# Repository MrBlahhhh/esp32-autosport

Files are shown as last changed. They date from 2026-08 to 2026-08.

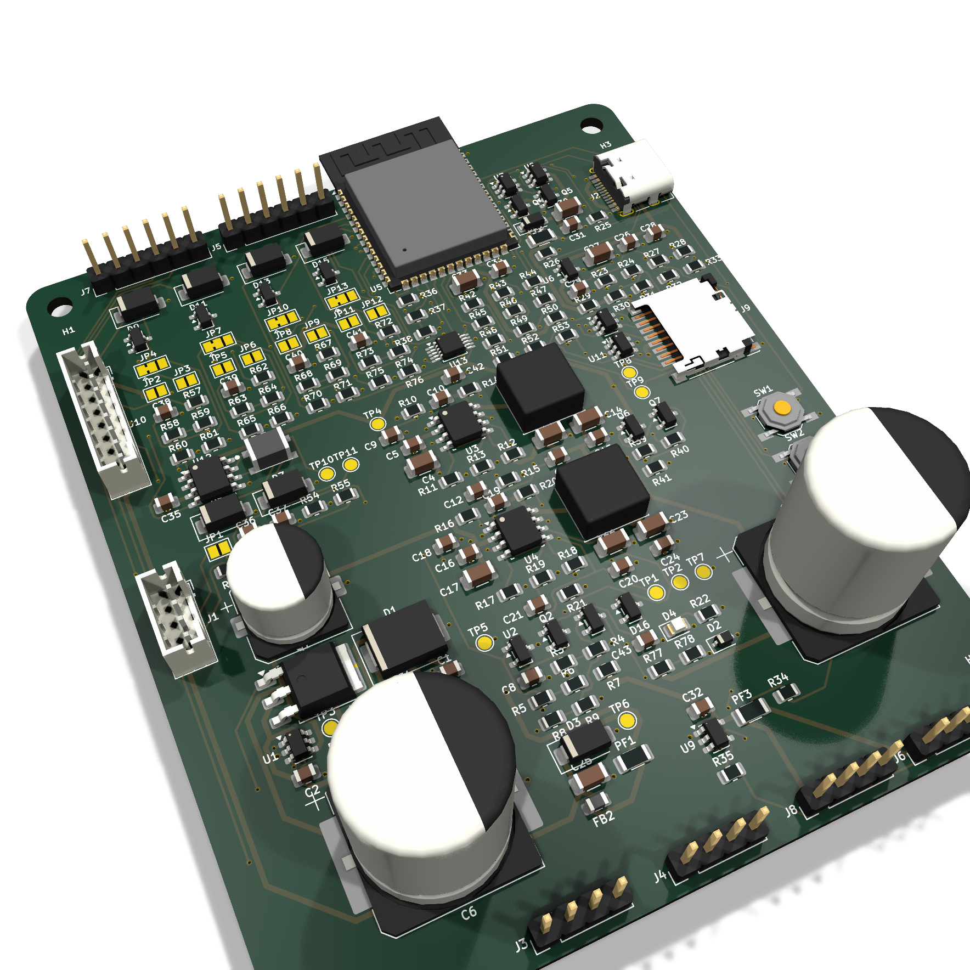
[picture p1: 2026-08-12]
plots/board-iso.png

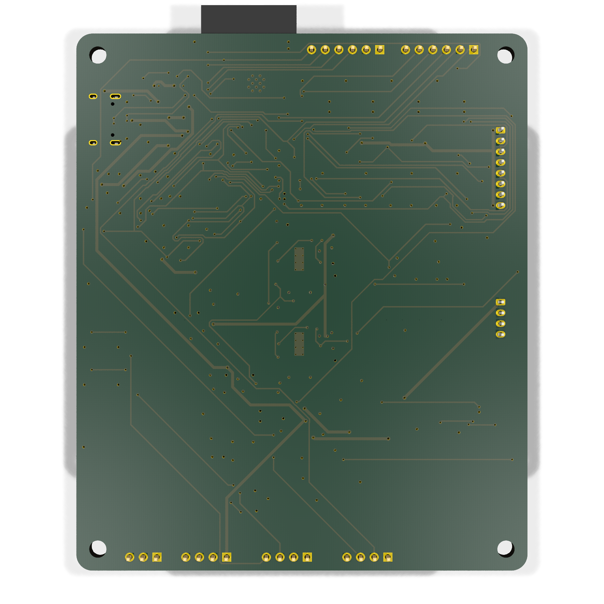
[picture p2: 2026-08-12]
plots/board-back.png

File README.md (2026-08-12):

# ESP32-S3 CAN + microSD Automotive Logger — Rev B

## TL;DR

A data logger you wire straight into a race car: 12 V and CAN come in on one
4-pin plug, sensor readings and CAN traffic get written to a microSD card.

- **You cannot kill it with the wiring.** Battery backwards? Blocks it,
  forever, no blown fuse. Alternator load dump, jump start, ignition spikes?
  Clamped. A sensor wire shorted to 12 V? That channel's fuse trips, the
  board keeps logging.
- **Ignition-off doesn't corrupt the card.** The board sees the power cut
  ~150 ms before it actually dies and uses that time (banked in two big
  capacitors) to finish the write and close the file.
- **4 sensor inputs, jumper-set for 0–3.3 V / 0–5 V / 0–16 V**, readable
  fast-and-rough on the ESP32's own ADC or slow-and-precise on a 16-bit
  ADS1115. Plus battery voltage monitoring, USB-C, a WS2812 shift-light
  header, and spare I/O.
- **The Python in `gen/` is the real source.** It generates, places, routes,
  audits, and circuit-simulates the whole board; the KiCad files are build
  outputs. `python gen/build_board.py` rebuilds the PCB from nothing, and
  [`gen/README.md`](gen/README.md) documents the whole pipeline — including
  the schematic-drawing conventions — so the next board can reuse it.
- **The firmware runs before the board exists.** `gen/simulate_firmware.py`
  compiles the sketch for the PC against a model of this board and feeds it
  CAN frames, sensor voltages and an ignition cut. Porting the proven MINI R53
  shift-light firmware to this hardware turned up five defects that no ERC,
  DRC or SPICE run can see — including a wideband that reads 17 % high and a
  sensor rail that never powers up.
- **State: routed clean, simulated, firmware ported, never manufactured.**
  Order a small prototype run first.

---

A single-CAN, single-microSD ESP32-S3 board with a motorsport-grade front end:
reverse-battery protection that survives being hooked up backwards indefinitely,
load-dump clamping, and four analog sensor inputs whose dividers are selected by
solder jumpers.

Feature set is deliberately close to the Autosport Labs ESP32-CAN-X2 and the
ESP32 Dual CAN-FD dev board — same ESP32-S3-WROOM-1 module, same 4-pin JST-PH
harness convention (12 V / GND / CAN_H / CAN_L), same jumper-selectable 120 Ω
termination — but trades the second CAN channel for an onboard microSD socket
and conditioned analog inputs. Termination ships **off** here rather than on,
which is the one place this board deliberately breaks with that convention:
the common case is plugging into a vehicle bus that is already terminated.

**Status: Rev B, fully routed.** Schematic is ERC-clean on KiCad 9.0. The PCB
is **84 x 100 mm**, 4-layer, **fully placed and routed with zero DRC errors and
nothing unconnected** — 1731 tracks, 323 vias, 206 footprints, 115 nets. Rev B
carries the fixes from an external datasheet review (§7): the LM74700 enable
divider, the ANODE capacitor, two TVS standoff corrections, transient clamps
on the analog harness inputs, and a dozen smaller items. `fab/` holds the
Gerbers, drill, BOM and pick-and-place in JLCPCB's format, BOM and CPL verified
to list the same 167 designators. See §9 for how the board is built, §10 for
what simulation and the physical audit say about it, and §11 for
the ordering steps. **Nothing has ever been fabricated — the first order should
be a small prototype run.**

---

## 1. Specification

| | |
|---|---|
| MCU | ESP32-S3-WROOM-1-N16R8 (16 MB flash, 8 MB octal PSRAM) |
| Supply input | 6–36 V continuous, reverse-protected to −65 V, transients clamped at 64.5 V, 154 ms power-cut ride-through (51 ms worst-case on a flat battery) |
| CAN | 1× CAN 2.0B, TJA1051T/3, ESP32-S3 TWAI controller, split termination, **off by default** |
| Storage | microSD, 4-bit SDMMC, switchable card supply |
| Analog in | 4 channels, solder-jumper divider, **0–5 V by default** (0–3.3 V / 0–16 V by jumper) + optional pull-up bias, shared by the ESP32 ADC and a 16-bit ADS1115 |
| Extras | Battery voltage monitor, USB-C (native USB), I²C/Qwiic, UART0, SPI breakout, WS2812 5 V DIN header, 6-pin spare-IO header |
| Rails | +5 V @ 1 A, +3V3 @ 1 A, +5 V sensor excitation (separately fused) |
| Parts | 195 component instances, 97 distinct BOM lines, all surface-mount except 8 through-hole connectors |

---

## 2. Power chain

```
J1.1 ──[F1 2A]──┬──[FB1 ferrite]── LM74700-Q1 + Q1 (ideal diode) ──┬── +VBAT
                │                                                  ├── C3 100µF bulk
                └── D1 SMCJ40CA clamp                              ├── U3 LM5164 ─→ +5V ─[PF1]─→ +5VS
                    (ahead of the FET)                             └── U4 LM5164 ─→ +3V3
```

### Reverse-battery protection

`U1` (LM74700-Q1) drives `Q1`, a 100 V N-channel MOSFET, as an ideal diode.
`Q1`'s **source faces the battery and its drain faces the load**, so the body
diode points forward: current passes in normal operation, and with the battery
connected backwards the body diode is reverse-biased and the FET is held off.
Nothing conducts, nothing gets hot, and the fuse does not blow — you can hook it
up backwards all day.

The forward drop is the FET's I·R (6.8 mΩ × 0.5 A ≈ 3 mV) rather than a diode's
0.4 V, so nothing is wasted in normal running either.

**Order matters here.** `D1`, the transient clamp, sits *ahead* of the blocking
FET. Clamping downstream of it leaves `Q1` and the LM74700 exposed to whatever
arrives on the harness: on a negative transient `Q1` turns off and stands the
whole pulse across its drain-source, and pulses 1 (−100 V) and 3a (−150 V) both
exceed its 100 V rating. In front of the FET the clamp catches those first —
simulation puts `Q1` at 55 V during pulse 1, against 100 V (§10).

That placement is only safe because `D1` is **bidirectional**. A unidirectional
part in this position would forward-conduct on a sustained reverse connection
and blow `F1`, which is exactly the outcome the ideal diode exists to avoid. At
40 V standoff either way, a −14 V reverse battery is still `Q1`'s job to block
and only real transients are clamped.

`R1`/`R2` set the LM74700 UVLO so the board enables at roughly 5.9 V and drops
out cleanly during cranking rather than browning out in an undefined state.

### Transient rating and its assumption

`D1` is an SMCJ40CA: 40 V standoff either polarity, 64.5 V clamping at 1500 W
(10/1000 µs). 40 V rather than 33 V so the part stands off the declared 36 V
top of the input window instead of sitting in conduction there.

That covers **ISO 7637-2 pulse 5b with centralised load-dump suppression**
(test level ~35 V), which is what any alternator with an internal avalanche
clamp produces — i.e. everything built in the last several decades. Simulation
(§10) shows the harness reaching 31 V in that case with the TVS never
conducting at all. Pulses 1, 2a, 3a and 3b are likewise covered: the worst is
pulse 1, where the clamp takes 0.07 J against roughly 2 J of capability at that
pulse width. A 24 V jump-start sits below the standoff voltage so it does not
conduct.

It does **not** cover unsuppressed load dump. At the pulse 5b level IV of 87 V
the clamp is asked to absorb 219 J against about 6.7 J of capability and is
destroyed (§10). That needs a higher-energy clamp or a series pre-regulator —
**say so if the target vehicle has an external-regulator alternator.**

Both bucks are LM5164s rated to **100 V**, so at the 64.5 V clamp level there
is still headroom on the switcher inputs; the clamp fires before anything
downstream is stressed. The tighter limit is the LM74700's own 65 V, which the
clamp level sits directly on top of — another reason the unsuppressed case is
out of scope rather than marginal.

### Why two bucks instead of a buck plus an LDO

`U3` (+5 V) and `U4` (+3V3) both run directly off `+VBAT`. It costs one extra
inductor versus 12 V→5 V→3.3 V cascading, and buys two things:

1. **Fault isolation.** A shorted 5 V sensor wire in the harness loads `U3`
   and trips `PF1`, but `U4` and the MCU never see it. A cascaded 3.3 V rail
   would collapse with the 5 V rail.
2. **No heat.** A 5 V→3.3 V linear at 600 mA burns ~1 W, which in an engine
   bay at 85 °C ambient is a thermal problem in a small package. A switcher
   burns almost nothing.

Both parts are the same LM5164, so it is one line on the BOM in quantity 20
rather than two different regulators.

### Power-fail detection and ride-through

The ignition cuts this board's power with a log file open on the SD card,
every single drive. The chain that makes that survivable:

1. **Detect** — a TLV431 watches `VBAT_F` *ahead* of Q1 through a 100k/12.7k
   divider and asserts `PWR_FAIL` (GPIO15, rising edge) when the harness
   drops below **11.0 V**. Sensing ahead of the ideal diode is the point:
   when the ignition opens, the harness collapses within microseconds while
   `+VBAT` coasts, so the warning arrives before any stored energy has been
   spent. A 1 M feedback resistor adds ~0.3 V of hysteresis so cranking sag
   cannot chatter the interrupt.
2. **Coast** — `+VBAT` holds 760 µF (100 µF + 2 × 330 µF/100 V). Energy is
   ½CV², so the bank lives on the input rail where a volt is worth most.
3. **Shed** — `SENS_EN` (GPIO16) drives a 2N7002 + AO3401 high-side switch on
   the sensor rail. Sensors are external loads firmware cannot otherwise
   turn off, and at four × 20 mA they double the drain. The switch is off at
   reset — the rail comes up only when firmware asks.

Simulated end to end (§10, `sim/ridethru.png`): detection in under 1 ms, and
from `PWR_FAIL` to the converters dropping out is **154 ms with the sensor
rail shed, 75 ms without** — both measured on the 760 µF bank.

That is the *healthy-battery* case: the ignition opens at 13.5 V and `+VBAT`
starts its coast from there, because `Q1` isolates it from the harness. Open
the ignition on a battery already down at the trip point and the bank starts
at 10.7 V instead — energy goes as V², so that alone is 1.9× less charge. The
Monte Carlo puts that flat-battery corner at **78 ms median, 51 ms at 0.1 %**
with worst-case tolerances (§10). Both are real; they bound opposite ends of
the same event, and firmware should be sized against the 51 ms.

**Firmware contract:** on `PWR_FAIL` rising — drop `SENS_EN`, stop sampling,
flush and close the file, then idle. Do not start a new write while
`PWR_FAIL` is high. The window is guaranteed by hardware; spending it is
firmware's job.

The firmware that spends it now exists and has been run against that window
(§10, *Firmware in the loop*). Measured: the file is closed **31 ms** after
`PWR_FAIL`, leaving 121 ms of the bank unspent, and the card may take up to a
**~130 ms** flush before the close no longer fits — though that, too, is
against the nominal window; on the flat-battery corner the budget is 51 ms and
only a healthy card fits. That is roughly seven times a
healthy card's latency but it is a limit, not unlimited protection — a card
that stalls for longer than that still loses the file.

### Reversed 5 V on the exposed 5 V pins

Asked and answered per connector: **USB-C** cannot be reversed through the
connector (VBUS/GND positions are fixed; the plug is rotation-symmetric).
**J10 sensor +5VS** survives a reversed 5 V by design — D3 forward-conducts
at −0.7 V and PF1 trips, resettable. A **backwards WS2812 strip** trips PF3;
the strip is on its own. **J8 rail break-out is unprotected** — it is a bare
bench header, and a reversed supply clipped onto it lands directly on the
+5 V rail's loads. Treat J8 like any bare rail.

### 5 V sensor excitation

`+5VS` is the +5 V rail behind the `SENS_EN` load switch, `PF1` (200 mA hold
/ 400 mA trip polyfuse), a ferrite, and `D3` (SMAJ6.0A). A sensor wire
shorted to chassis or to battery trips the polyfuse and clamps the transient
without taking the board down — and a tripped rail can now also be cycled
from firmware instead of waiting for the polyfuse to cool.

Note this is a *fused tap off the 5 V rail*, not a separately regulated
reference. For ratiometric sensors where absolute accuracy matters, the ADC
should ratio against a measurement of `+5VS` — or add a dedicated precision
reference. See §7.

---

## 3. Analog input conditioning

Each of the four channels is identical:

```
AINn_IN ──[1k series]──┬─────────[10k]────┬── AINn ──→ ADC
                       │                  │
                  [JPn PULLUP]        [JPn BYPASS] (shorts the 10k)
                       │                  │
                    2.49k             [JPn RANGE] ─┬─[15k]─ GND   (position A)
                       │                           └─[2.21k]─ GND (position B)
                    +5VS                  │
                                    [100nF] + BAT54S clamp to GND / +3V3
```

### Jumper matrix

| RANGE | BYPASS | Input range | Ratio | At the ADC | Clips at | Typical sensor |
|---|---|---|---|---|---|---|
| **A** | open | **0–5.0 V — ships like this** | 0.5769 | 2.885 V at 5.0 V in | 5.37 V in | MAP, TPS, wideband AFR, most 5 V sensors |
| open | **closed** | 0–3.3 V | 1.0000 | 3.300 V at 3.3 V in | 3.10 V in | 3.3 V-native sensor, ratiometric output |
| **B** | open | 0–16 V | 0.1673 | 2.677 V at 16.0 V in | 18.53 V in | Battery-referenced signals, 12 V switch inputs |

**All four channels ship in the 0–5 V position** — `RANGE` bridged 1–2,
`BYPASS` open — because that is what almost every automotive sensor is, and
because it means the firmware's `DIVIDER_GAIN` matches the board as delivered
rather than assuming a jumper somebody has to remember to fit. Cut the 1–2
bridge to move a channel to either of the other two rows.

The upper leg is the 1 k series resistor plus the 10 k, so 11 k against 15 k
gives 15/26 = 0.5769 on the 5 V range and 2.21/13.21 = 0.1673 on the 16 V one.

**These deliberately do not divide to 3.3 V.** The ESP32-S3 ADC tops out near
3.10 V at 12 dB attenuation, and a divider scaled to land exactly there has no
margin: a 5 V sensor rail is rarely exactly 5.000 V, and anything that
overshoots clips silently at full scale — which reads as a plausible-but-wrong
value rather than an obvious fault. At 0.5769 a 5 V channel does not clip until
5.37 V in. The 1:1 mode is the exception and has no headroom by design; it
assumes a sensor that genuinely cannot exceed 3.3 V. The BAT54S clamps protect
the pin either way, but clamping is protection, not measurement.

Source impedance at the ADC node is 11 k ∥ 15 k = **6.35 kΩ** on the 5 V range
(1.84 kΩ on the 16 V range). With the 100 nF filter cap that puts the −3 dB
point at about 250 Hz — ideal for AFR, temperature and pressure, and the limit
if you ever want something fast on a channel.

`PULLUP` is independent of the above: closing it puts 2.49 kΩ to `+5VS` on the
input node, turning the channel into a bias network for **2-wire NTC sensors**
(coolant, oil, air temp) or open-collector/switch-to-ground inputs. Leave it
open for anything that drives its own output.

Every channel lands on **ADC1** (`GPIO1`, `GPIO2`, `GPIO4`, `GPIO5`), which is
the half of the ESP32-S3 ADC that keeps working while WiFi is active. ADC2 is
unusable with WiFi up — that constraint drove the pin assignment.

The same four conditioned nodes also feed `U13`, an **ADS1115** (16-bit
delta-sigma, on the existing I²C bus at 0x48). The ESP32-S3's internal ADC is
only good for ±1–2 % even after calibration — ±0.2 AFR on a 0–5 V wideband
output — so firmware picks per channel: fast-and-rough on the internal ADC, or
slow-and-accurate (up to 860 SPS) on the ADS1115. The divider resistors are
0.1 % thin-film so the front end does not throw away what the converter buys,
and the note in the schematic records that the 1 k series resistor is part of
the divider chain — the exact scale factor is a firmware calibration constant.

`R77` (100 k) and `R64` (10 k) divide `+VBAT` by 11 onto `GPIO6` for
battery-voltage logging: 14.0 V reads 1.27 V, and the 36 V top of the input
range reads 3.27 V.

---

## 4. CAN

`U12` is a TJA1051T/3 — 5 V bus drive with a separate `VIO` pin tied to +3V3, so
the ESP32 sees 3.3 V logic with no level shifter. `S` is pulled low by `R54`
(10 k) so the transceiver comes up in normal mode with the MCU still in reset;
`GPIO21` can raise it for silent (listen-only) sniffing. `CAN_TX` has no
external pull — the TJA1051 pulls TXD high internally, so a floating pin at
boot is recessive and a bare board cannot jam the bus.

Bus side, in order from the transceiver out:

- `L3` common-mode choke — TDK ACT45B-510-2P-TL003, 51 µH, AEC-Q200. The
  footprint is project-local (`footprints/esp32autosport.pretty`) and its pads
  are renumbered so the symbol's winding 1–2 maps to the package.
- Split termination: `R55`/`R56`, two 60.4 Ω in series with `C28` 4.7 nF to
  ground at the midpoint. Split termination beats a single 120 Ω resistor
  because it gives the common-mode noise somewhere to go instead of
  reflecting it.
- `JP1` in series with the top half — **open by default: the board ships
  unterminated**. Bridge the pads only when this board is an end node on a bus
  of its own. Every vehicle bus, OBD-II diagnostics included, is already
  terminated at both ends, and a third 120 Ω across the pair takes it to about
  40 Ω and can stop it working. This deliberately departs from the Autosport
  Labs convention of shipping terminated, because the common case here is
  plugging into a car that is already correct.
- `D6`/`D7` SMAJ26CA bidirectional clamps to ground on each line.

CAN_H/CAN_L run to `J1` pins 3 and 4, so one 4-pin JST-PH carries power and bus
in a single harness.

### OBD-II and "K-DCAN"

A BMW/MINI K+DCAN cable carries **two unrelated buses**, and this board has
hardware for exactly one of them.

**D-CAN — yes, already.** Diagnostic CAN is ISO 15765-4: plain 500 kbit/s CAN
on OBD-II pins 6 and 14, which is what `U12` and the TWAI controller do. `J1`
maps onto an OBD-II plug with nothing in between — pin 16 to `J1.1`, pins 4/5
to `J1.2`, pin 6 to `J1.3`, pin 14 to `J1.4` — so one cable both powers the
board and connects it to the bus. What is left is software: ISO-TP
(ISO 15765-2) segmentation and whichever of UDS or KWP2000 the target speaks.

> **Termination is already off.** `JP1` ships open (§4), which is what a
> vehicle bus wants — it is already terminated at both ends, and a third
> 120 Ω across the pair drops it to ~40 Ω and can stop it working entirely.
> So there is nothing to cut before plugging into a car; bridge `JP1` only
> for a bench bus where this board is an end node. Note also
> that `CAN_S` (GPIO21) lets firmware pick listen-only for sniffing, so the
> board need never ACK a bus it is only observing.

**K-line — no, and it cannot be bodged.** ISO 9141-2 / KWP2000 is a single
bidirectional wire on OBD-II pin 7 idling at battery voltage and pulled to
ground by an open-collector driver. That needs a transceiver — an L9637D or
equivalent — and there is none on this board. Feeding it into an analog input
does not work either: on the 0–16 V setting the anti-alias filter rolls off at
891 Hz (§10), which destroys even 9600 baud, and it gives no way to transmit.
Routing it to `J7` is worse, since those are strapping pins and a K-line
idling high at boot would hold `IO46` in the wrong boot mode.

This matters for the **MINI R53** specifically: its instrument CAN carries
`0x316` at 500 kbit/s, which this board already reads and logs — but its
*diagnostics and flashing* are K-line at 9600 8E1, negotiating to 62500 baud
for flash reads. The shift light and telemetry work on this hardware. A
tuning or flashing tool does not.

Adding it needs an external L9637D module on the `J5` SPI header — the S3's
UARTs matrix onto any GPIO, so two of `GPIO40`–`42`/`47` become K-line TX/RX,
and `J5` supplies +3V3 and ground. The one wire `J5` cannot supply is the
transceiver's battery feed: `J8` breaks out +5 V, +3V3 and ground only, so
12 V has to come from `TP3` or upstream of `J1`. **For a rev C, an on-board
L9637D is the highest-value addition** — SO-8, about a dollar, two GPIOs and a
`+VBAT` tap — and it would make one board cover both halves of a K+DCAN cable.

---

## 5. microSD

Wired for **4-bit SDMMC** (`GPIO9`–`GPIO14`), not SPI — roughly 4× the write
throughput, which matters when logging a busy bus.

- 33 Ω series damping on CLK, CMD and D0–D3.
- 10 kΩ pull-ups on CMD and D0–D3, the value Espressif's SD documentation
  asks for. **These pull to `SD_VDD`, the switched rail, not to +3V3** —
  pull-ups to a permanent rail would back-feed a powered-down card through
  its ESD structures. The pull-up on D3 is also what selects SD mode over
  SPI mode when the card powers up. Card detect keeps a weaker 47 kΩ: it is
  a mechanical contact, not a bus line, so there is no reason to burn the
  standing current.
- `Q6`/`Q7` form a high-side switch on the card supply, driven by `GPIO7`, so
  firmware can hard power-cycle a card that has locked up mid-write. This is
  the single most useful recovery mechanism in a logger; SD cards do wedge.
- `GPIO8` reads the socket's card-detect switch.

**Firmware note:** tristate the SDMMC pins before dropping `SD_PWR_EN`, or the
MCU will back-feed the card through its I/O pins while its supply is off.

---

## 6. GPIO map

| Module pin | GPIO | Net | Function |
|---|---|---|---|
| 39 | IO1 | `AIN1` | Analog ch 1 (ADC1_CH0) |
| 38 | IO2 | `AIN2` | Analog ch 2 (ADC1_CH1) |
| 4 | IO4 | `AIN3` | Analog ch 3 (ADC1_CH3) |
| 5 | IO5 | `AIN4` | Analog ch 4 (ADC1_CH4) |
| 6 | IO6 | `VBAT_SNS` | Battery voltage ÷11 (ADC1_CH5) |
| 7 | IO7 | `SD_PWR_EN` | microSD supply enable (high = on) |
| 12 | IO8 | `SD_CD` | Card detect |
| 17–22 | IO9–IO14 | `SD_D3,D2,D1,D0,CMD,CLK` | SDMMC 4-bit |
| 10, 11 | IO17, IO18 | `CAN_TX`, `CAN_RX` | TWAI |
| 23 | IO21 | `CAN_S` | Transceiver silent mode (low = normal) |
| 13, 14 | IO19, IO20 | `USB_DM`, `USB_DP` | Native USB |
| 31, 32 | IO38, IO39 | `I2C_SDA`, `I2C_SCL` | Qwiic header |
| 36, 37 | IO44, IO43 | `UART_RX`, `UART_TX` | UART0 header |
| 33–35, 24 | IO40–42, IO47 | `SPI_SCK`, `SPI_MISO`, `SPI_MOSI`, `SPI_CS` | SPI breakout |
| 25 | IO48 | `LED_DIN_MCU` | WS2812 data (via 5 V AHCT buffer → header) |
| 27 | IO0 | `MCU_BOOT` | BOOT button |
| 3 | EN | `MCU_EN` | RESET button |
| 15, 16, 26 | IO3, IO46, IO45 | — | Spare-IO header `J7`, each with a 10 k pull-down |
| 8 | IO15 | `PWR_FAIL` | Power-fail interrupt (high = harness below 11 V); also J7 pin 4 as a probe point |
| 9 | IO16 | `SENS_EN` | Sensor-rail (+5VS) enable, active high, off at reset; also J7 pin 5 |
| 28, 29, 30 | IO35, IO36, IO37 | — | **Unusable** — octal PSRAM |

`IO3`, `IO45` and `IO46` are strapping pins, and each carries a 10 kΩ
pull-down (`R36`–`R38`) chosen for its strapping role: `IO45` low sets
VDD_SPI to 3.3 V, `IO46` low selects normal boot, `IO3` low fixes the JTAG
source. The board therefore boots correctly with `J7` empty. What the
pull-downs cannot survive is something plugged into `J7` that actively
*drives* one of them high at boot — 10 kΩ loses to a driver — so do not hang
anything on `J7` that asserts a level before the MCU is out of reset.

### WS2812 shift-light header

`J6` (silk **WS2812**): `LED_5V` / `LED_DIN` / `GND`. `LED_DIN` is driven by a
`74AHCT1G125` powered from `+5V`, so the strip sees a real 5 V logic level.
Firmware bit-bangs / RMT on **GPIO48**. `LED_5V` is behind a 0.5 A polyfuse off
the board 5 V rail — enough for an 8-LED stick, not a full belly-band.

### SPI breakout

`+3V3` / `GND` / `SCK` / `MISO` / `MOSI` / `CS` on GPIO40/41/42/47. Intended for
an external MCP2515 (second CAN), CC1101 (433 MHz TPMS), or MAX6675, etc.

---

## 7. Review before layout

Resolved in the rev A review (2026-08, against datasheet SNVSAU4D and TI
drawing 4214849/B):

1. ~~RON placeholders~~ — computed from Eq. 12: **31.6 kΩ → 396 kHz** on the
   5 V rail, **20.5 kΩ → 402 kHz** on the 3.3 V rail. Minimum on-time at the
   64.5 V clamp is 196 ns / 128 ns, both far above the 50 ns floor.
2. ~~Footprint~~ — the original `EP2.41x3.3mm` exposed pad was *smaller* than
   the DDA0008B pad itself (max 2.71 × 3.4 mm). Now on
   `EP2.95x4.9mm_Mask2.71x3.4mm_ThermalVias`, which matches TI's example land
   pattern exactly (2.95 × 4.9 copper, 2.71 × 3.4 mask-defined opening).
3. ~~Load-dump assumption~~ — confirmed: the target vehicle's alternator never
   exceeds 20 V, so the SMCJ40CA's 40 V standoff has comfortable margin and the
   centralised-suppression assumption in §2 holds. Simulation later put a
   number on what happens if it does not: see §10.
4. ~~Clamp injection~~ — quantified: one analog input shorted to 20 V battery
   back-feeds ≈1.6 mA through its BAT54S into +3V3. With the MCU running
   (≥ 20 mA) the rail cannot lift, but in deep sleep the always-on load is only
   ≈1.3 mA (power LED), so one faulted channel floats the rail to ≈3.6 V and
   two would exceed the ESP32's absolute maximum. Fixed with `D2`, a 3.6 V
   zener rail clamp (MM3Z3V6T1G).

Two more issues surfaced while reading the datasheet, both fixed:

- **Bootstrap capacitors were 100 nF.** The LM5164 datasheet mandates exactly
  2.2 nF and warns that larger values overstress the internal VCC regulator
  and damage the device. Both `CBST` are now 2.2 nF 50 V X7R.
- **No feedback ripple injection.** The outputs are all-ceramic, so FB had no
  in-phase ripple — the datasheet (Table 6-1) says a COT converter is unstable
  without it. Both rails now carry a Type-3 network (RA from SW, CA to the
  output, CB into FB: 121 k / 3.3 nF / 270 pF on 5 V, 95.3 k / 3.3 nF / 270 pF
  on 3.3 V), sized per TI's design example for ≈20 mV of ramp at 14 V in.

5. ~~ESP32-S3 ADC linearity~~ — resolved for the AFR use case: `U13`, an
   onboard ADS1115 (16-bit, I²C), now shares the four conditioned input
   nodes, and the divider resistors are 0.1 % thin-film. See §3.

6. ~~Layout rules~~ — the board is laid out now (§9). The switching-regulator
   rules this item called for are all in `gen/generate_pcb.py` and
   `gen/route_bucks.py` as fixed placements: tight input-cap loops on
   `U3`/`U4` with `C4` at the VIN pin, a solid GND plane under the whole
   ideal-diode block, and the CAN choke beside `J1`.

Still open for a second pair of eyes:

7. `+5VS` accuracy (§2) if ratiometric sensors are used. (AFR is absolute, not
   ratiometric, so this does not affect the wideband channel.)
8. **Nothing has been fabricated.** Every check here is a software check —
   ERC, DRC, datasheet review, sourcing. No one has powered one on.

Found later, during the pin audit (§6), and worth knowing rather than fixing:

9. The WS2812 buffer input floats at boot. `GPIO48` reaches `U9` pin 2 through
   a 33 Ω series resistor with no pull-down, so that CMOS input is undefined
   from power-on until firmware drives it — a brief random flicker on the
   strip and a milliamp or so of shoot-through in `U9`. Harmless, and cheaper
   to fix in firmware (drive `GPIO48` low first) than to respin for.
10. `J7` (Spare IO) has three signals and no ground pin. Use `J8`'s ground two
    headers along. Also note all three of its pins are strapping pins — see
    §6.

### Sourcing (JLCPCB assembly)

**Every part number in `fab/bom.csv` was re-checked against the live LCSC and
JLCPCB catalogues on 2026-08-12** — all 23, one at a time, confirming the MPN,
the package and that the part exists. Two were wrong:

| Was | Resolved to | Should be |
|---|---|---|
| `C8544` for `Q5` MMBT3906 | **S9018, an NPN** from JSCJ | `C84105` — ST(Semtech) MMBT3906, PNP, SOT-23 |
| `C7975` for `U9` SN74AHCT1G125DBVR | **LMV324IPWRG4**, a quad op-amp in TSSOP-14, out of stock | `C7484` — TI SN74AHCT1G125DBVR, SOT-23-5 |

The `Q5` one was live in the BOM and would have assembled an NPN where the USB
over-voltage cutoff needs a PNP — protection that silently does not work. The
`U9` one was only ever in this table; the generator already carried a comment
saying `C7975` was wrong and left the field blank, and that fix never reached
the prose. Both are corrected, and `L2`'s 22 µH inductor picked up a verified
number (`C340243`) on the way past.

The critical semiconductors, all confirmed present and in stock:

| Part | MPN | JLC # | Notes |
|---|---|---|---|
| ESP32 module | ESP32-S3-WROOM-1-N16R8 | C2913202 | 13 087 in stock |
| Buck ×2 | LM5164DDAR | C477928 | Non-automotive variant — the Q1 is backordered at DigiKey and nearly dry at Mouser; same silicon, minus AEC-Q100 |
| Ideal-diode ctrl | LM74700QDBVRQ1 | C2941042 | SOT-23-6, 3 987 in stock |
| Reverse-batt FET | IPD068N10N3G | C88066 | Replaces PSMN4R3-100BSE, **which does not exist** (nearest real Nexperia part is a D2PAK); TO-252, drops into the same footprint, 6.8 mΩ costs ~3 mV at load |
| CAN transceiver | TJA1051T/3 | C58988 | NXP original, 11 085 in stock; the BOM carries the `,118` reel suffix |
| Precision ADC | ADS1115IDGSR | C37593 | VSSOP-10, 24 565 in stock. Non-automotive variant — the Q1 needs a manufacturer quote at DigiKey |
| WS2812 buffer | SN74AHCT1G125DBVR | **C7484** | TI, SOT-23-5. **Not C7975** |
| USB OVP transistor | MMBT3906 | **C84105** | ST(Semtech), PNP. **Not C8544** |
| Buck inductors | ASWPA8050S330MT / S220MT | C340244 / C340243 | Sunlord automotive series, 8×8 mm, 3 A Isat. JLCPCB-catalogue parts — the LCSC product page 404s, which is normal for JLC-only stock |

Nine lines still have no part number and are picked by hand at order time: the
`330 µF`/`100 µF` 100 V electrolytics, the green LED, `PMEG4010`, both
polyfuses, `DMG2301L`, the `TL3342` buttons, `TLV431ASN1T1G`. The 0.1 %
thin-film divider resistors are commodity and auto-match on value + package.

---

## 8. Files

| Path | What |
|---|---|
| `esp32s3-can-sd-logger.kicad_pro` | KiCad project. **Owns the netclasses** — Power 0.5 mm / CAN 0.25 mm — and the 0.2 mm min-drill rule |
| `esp32s3-can-sd-logger.kicad_sch` | Root sheet |
| `power.kicad_sch` | Protection and rails |
| `mcu.kicad_sch` | ESP32-S3, USB-C, headers |
| `sdcard.kicad_sch` | microSD |
| `can.kicad_sch` | CAN transceiver and bus network |
| `analog.kicad_sch` | 4 sensor channels + battery monitor |
| `bom.csv` | BOM with quantities for 1 and 10 boards |
| `netlist.txt` | Human-readable net list (the design's source of truth) |
| `plots/schematic.pdf` | Rendered schematic, all six sheets |
| `gen/generate_schematic.py` | Generator — edit this, not the `.kicad_sch` files |
| `gen/validate.py` | Verifies the output with KiCad itself |
| `gen/build_board.py` | One-command board build: places, stitches, routes, verifies |
| `gen/generate_pcb.py` | Board generator — run with KiCad's bundled Python |
| `gen/stitch_planes.py` | Via from every GND / +3V3 pad to its plane |
| `gen/export_dsn.py` | Specctra export with the inner layers locked as planes |
| `gen/import_ses.py` | Imports the router's session and refills the pours |
| `gen/finish_routing.py` | Ties duplicated connector pins; reports leftovers |
| `gen/maze_route.py` | Rip-up-and-retry router for what the autorouter fences in |
| `gen/tidy_silk.py` | Shrinks and re-places reference designators; no copper |
| `gen/netclasses.py` | Per-net track and via sizes, read from the project file |
| `gen/export_fab.py` | Gerbers, drill, JLC assembly BOM and position files |
| `gen/export_plots.py` | Rebuilds everything under `plots/` — run it after any change |
| `gen/route_bucks.py` | Places buck islands + routes SW/VIN critical copper |
| `esp32s3-can-sd-logger.kicad_pcb` | Generated 4-layer board, fully placed and routed |
| `footprints/esp32autosport.pretty` | Project footprints (TDK ACT45B CAN choke) |
| `plots/board-routed.png` | Render of the finished board, top |
| `plots/board-back.png` | Render of the finished board, bottom — routing only, no parts |
| `fab/` | Gerbers, drill, JLC BOM and pick-and-place (generated) |
| `docs/PREORDER.md` | Pre-order checklist: what is checked, what is not, what to do at upload |
| `gen/audit_paste.py` | Stencil apertures: IPC-7525 area ratio and thermal-pad paste coverage |
| `gen/audit_mechanical.py` | Vibration screen: board resonance and Steinberg fatigue on the tall cans |
| `docs/BRINGUP.md` | Staged first-power checklist, tied to the study values |
| `firmware/esp32_shiftlight_wideband/` | Firmware for this board: shift light, wideband BLE bridge, microSD logger |
| `firmware/vendor/` | Verbatim copy of the R53 sketch — the control build, do not edit |
| `gen/simulate_firmware.py` | Firmware-in-the-loop studies: runs the sketch and feeds it inputs |
| `fwsim/` | The host shims and board model those studies run on |
| `gen/mutate_firmware.py` | Mutation test: breaks the firmware 16 ways and checks the suite notices |
| `sim/fw/` | Per-run scenario, trace, serial log and findings (generated) |

### KiCad version

The committed files are **KiCad 7.0 schematic format** (`version 20230121`).
KiCad 8 and 9 open them directly and upgrade the format on load, so nothing
needs converting — just open `esp32s3-can-sd-logger.kicad_pro`. Note that once
KiCad 9 saves, the files are rewritten in 9's format; re-running the generator
would put them back to 7's.

### Running ERC

`kicad-cli` gained an `erc` subcommand in 8.0. On KiCad 8 or 9, `validate.py`
picks it up automatically and reports violations as failures. To run it alone:

```sh
kicad-cli sch erc --output erc.json --format json \
    --severity-error --severity-warning esp32s3-can-sd-logger.kicad_sch
```

On KiCad 7 the check is skipped with a notice, since the subcommand does not
exist there. **ERC passes clean on KiCad 9.0** (no errors, no warnings) as of
rev A; the committed files embed symbol definitions from the KiCad 9 libraries,
so opening them on an older KiCad may report harmless lib-mismatch warnings.

### Regenerating

The schematic is generated. The netlist tables in `gen/generate_schematic.py`
are authoritative; symbol geometry and **all pin numbering** are pulled from the
installed KiCad libraries, so no pin number is ever hand-typed.

```sh
python3 gen/generate_schematic.py
python3 gen/validate.py
```

`validate.py` loads every sheet through KiCad, exports the hierarchy's netlist,
asserts that KiCad's own extracted connectivity matches `netlist.txt`
node-for-node, and runs ERC where available. It currently passes on **107 nets /
168 component instances**.

The generator embeds symbol definitions copied verbatim from the installed
libraries, so the embedded copies always match whatever KiCad generation you
regenerate on (it handles both the 7/8 space-indented and the 9 tab-indented
library formats, and resolves the generic MOSFET symbols from `Transistor_FET`
where KiCad 9 moved them out of `Device`). The generator prints a warning when
the library generation differs from the one last validated against — run
`validate.py` afterwards; it will catch a sheet that fails to load and runs a
full ERC.

Editing the `.kicad_sch` files by hand is fine — they are ordinary KiCad files —
but the next generator run will overwrite them.

---

## 9. Board layout and routing

The board is generated the same way the schematic is. One command does the
whole chain:

```sh
python gen/build_board.py --freerouting freerouting.jar
```

| Stage | Script | What it does |
|---|---|---|
| 1 | `generate_pcb.py` | Places every part, draws the outline, planes, keepouts |
| 2 | `route_bucks.py` | Hand-shaped copper for the two buck power loops |
| 3 | `stitch_planes.py` | A via from every GND / +3V3 pad down to its plane |
| 4 | `export_dsn.py` | Specctra export, **In1/In2 marked as power planes** |
| 5 | freerouting | Routes the remaining signals on F.Cu / B.Cu |
| 6 | `import_ses.py` | Brings the routes back, refills the pours |
| 7 | `finish_routing.py` | Ties duplicated connector pins, reports leftovers |
| 8 | `maze_route.py` | Rips up and re-routes whatever is still open |
| 9 | `tidy_silk.py` | Shrinks and shuffles the reference designators |

84 x 100 mm, 4 layers: **F.Cu / GND / +3V3 / B.Cu**, JLCPCB JLC04161H-7628
stackup, 0.2 mm minimum drill (the LM5164 thermal vias), 0.5 mm copper-to-edge
enforced by a rule-area band around the perimeter.

Five things in that pipeline are worth knowing, because every one of them
was learned the hard way:

**The inner layers must be declared `power` in the DSN.** KiCad exports every
copper layer as `signal`, so an autorouter cheerfully runs traces straight
through what are meant to be solid pours -- the first attempt here had `IO45`
and `SPI_MOSI` crossing the middle of the +3V3 plane, which fragmented it and
orphaned everything that depended on it. `export_dsn.py` rewrites those two
layer declarations, and routing then stays on the outer layers where it
belongs.

**Plane pads are stitched before routing, not after.** A pad on GND or +3V3
does not want a routed track, it wants a via next to it; doing all 113 of them
up front means the router treats them as obstacles and has only signals left to
solve. 110 get a via; the three that do not are the exposed thermal pads of
`U3`, `U4` and the module, which the pour bonds to directly. `stitch_planes.py` places each via with real point-to-rectangle and
point-to-segment distance checks -- bounding boxes are far too pessimistic in a
dense field and refuse room that is really there.

**The last few connections need rip-up, not a better search.** An autorouter
takes the easy nets first and fences the awkward ones in, so what it leaves
behind has no path at all -- `SD_CLK` ran straight under the ESP32 module's
pads 20 and 21 and walled both of them off, and at 1.27 mm pitch nothing slips
past sideways. `maze_route.py` grids each copper layer at 0.1 mm, searches both
layers at once with Dijkstra, and when that fails works out which nets are
pressed against the dead end, tears them out, routes the trapped net through
the space they leave, and re-routes them afterwards. Three details make it
work rather than thrash:

- **A rip removes tracks, never pads.** Ignoring a ripped net's pads too lets
  the router lay copper straight across them.
- **Blockers are ranked from the tighter pocket.** Flood from both ends and
  score the smaller one -- an end that can reach half the board has a frontier
  thousands of cells long, and the innocent nets along it drown out the few
  actually doing the trapping.
- **Connections are to a net, not a pad.** USB-C carries D- on both A7 and B7;
  A7 escapes only down a 16 um corridor, finer than any grid, while B7 opens
  onto the whole board. Aiming at the net's existing copper turns an
  impossible route into an easy one.

Nets with more than four pads are never ripped: a two-pad signal comes back as
one trace, but a rail that daisy-chains six decoupling caps comes back as six
separate connections, each able to fail on its own.

**The netclasses live in the `.kicad_pro`, and two things used to lose them.**
This one is worth spelling out because it fails silently -- narrow track is
legal track, so nothing errors, nothing warns, and the board looks finished.

`generate_pcb.py` builds its board with `CreateEmptyBoard()`, which knows only
the Default class; saving that board rewrote the project file from the board's
own settings and threw Power and CAN away. Everything downstream then routed
at the default width, **including the 1 A rails** -- 0.2 mm copper, which is
1.01 A at a 20 °C rise and 147 mV of drop over a 60 mm run. On `+5VS`, the
sensor excitation rail, that droop lands directly on every ratiometric reading
the 0.1 % dividers exist to protect. The generator now lifts `net_settings` out
before the save and puts it back after, and reports what it restored.

The second loss was `net.GetNetClass()`, which returns an undecorated
SwigPyObject in these scripts and raises `AttributeError` on any method. A
`try/except ... return DEFAULT` around it turns straight into 0.2 mm power
rails. `gen/netclasses.py` reads the classes and their glob patterns out of the
project file instead, and both routers size every track and via from it.

**Pads are not their bounding boxes.** The router's occupancy grid may use
bounding boxes -- being too cautious only costs it room -- but deciding *where
a trace may end* cannot. A 1.70 mm round header pad has a 1.70 mm square
bounding box whose corners are ~0.35 mm off the copper, so 23 % of the apparent
landing area is bare laminate. Ending there produces a connection that is not
one, which is how every header on J3/J4/J5/J7 stayed open while the router
insisted it had routed them. The island builder asks `pad.HitTest()` instead,
which is exact for round, oval and rounded-rectangle pads alike.

### Placement

- **Left edge:** sensor harness (`J10`) and power/CAN harness (`J1`) -- one
  wiring direction toward the car.
- **Top:** four identical analog channel columns with their solder jumpers
  facing up for probing; ESP32 module top-centre with the **antenna
  overhanging the board edge**, so the module's own RF keepout falls entirely
  off-board; Spare-IO and SPI headers to its left.
- **Right edge:** USB-C and microSD for bench access, then RESET/BOOT and the
  status LEDs.
- **Middle:** the two stacked buck islands, each with its input caps at the
  VIN pin and its RON/FB/ramp network alongside.
- **Bottom edge:** battery front end beside `J1`, and the UART0 / I2C / rail /
  WS2812 headers along the edge.

The USB-C receptacle sits ~2.5 mm inboard of flush rather than overhanging.
Its A/B duplicate pins (D+ on A6 and B6, D- on A7 and B7) have to be tied
together on copper for a reversible cable, and at 0.5 mm pitch that needs a
via channel between the pad row and the edge keepout. The case opening sets
plug access anyway.

## 10. Simulation and physical audit

Two scripts check what ERC and DRC structurally cannot. ERC asks whether the
netlist is self-consistent and DRC asks whether the copper is manufacturable;
neither asks whether the circuit works, or whether the board survives a car.

```
python gen/simulate.py                          # ngspice: the circuits
"…/KiCad/9.0/bin/python.exe" gen/audit_pcb.py   # pcbnew: the layout's physics
"…/KiCad/9.0/bin/python.exe" gen/overstress.py  # closed-form worst case
```

`simulate.py` needs ngspice, numpy and matplotlib and runs on any Python 3. It
writes its decks, data and plots to `sim/`, so every number below can be
re-derived rather than taken on trust.

**What it confirms.** The divider maths in §3 is right to three digits: 5.0 V
in gives 2.859 V at the ADC on the 0–5 V setting and 16.0 V gives 2.670 V on
the 0–16 V setting, against the 2.88 and 2.67 the schematic notes predict.
Both converters run well inside their inductors — 0.27 A of ripple on a 2.13 A
peak against a 3.0 A saturation rating for +5 V, 0.35 A on 1.18 A against
3.4 A for +3V3 — with 26 mV and 44 mV of output ripple at 13.5 V in, computed
against the output MLCCs' biased capacitance rather than their printed value.
ISO 7637-2 pulses 2a, 3a and 3b never reach the clamp at all: the 100 µF bulk
and the ferrite swallow them and the TVS absorbs a measured 0 J.

**What it flags.**

1. **Pulse 1 still browns the board out, now for ~5.6 ms.** A -100 V, 2 ms
   transient turns Q1 off, and the board runs on the 760 uF bank at full
   load until the harness recovers. The ride-through caps shrank the outage
   from 8.2 ms but cannot absorb it: the pulse actively holds the harness
   at -47 V for 2 ms, and the bank spends most of its charge riding that
   out. Nothing is damaged -- Q1 stands off 59 V against its 100 V rating --
   and the power-fail detector fires on the way down, so firmware sees it
   as an ordinary power cut and closes the file. A reset mid-drive on a
   full ISO pulse 1 is the accepted outcome. **This is a decision, not a
   defect.**

2. **An unsuppressed load dump destroys the front end.** At the pulse 5b
   level IV of 87 V the SMCJ40CA absorbs 219 J against roughly 6.7 J of
   capability at that pulse width. The suppressed 35 V case is a non-event:
   31 V at the harness, the TVS never conducts. So D1's note claiming it
   "absorbs ISO 7637-2 pulse 5b load dump" holds only for a vehicle with a
   centrally suppressed alternator — every modern one, but an assumption the
   board depends on rather than a property it has.

3. **The anti-alias corner moves with the range jumper**: 261 Hz on the 0–5 V
   setting, 891 Hz on 0–16 V, 1.65 kHz bypassed. The 100 nF sees a different
   source impedance in each configuration, so the filter is whatever the
   divider leaves it. Two of the three sit above the 430 Hz Nyquist of the
   ADS1115 at its fastest rate.

4. **A 36 V input with BYPASS closed backfeeds +3V3.** Each channel pushes
   32 mA through its BAT54S into the rail, 129 mA across four. Harmless while
   the ESP32 is drawing its share; a rail-pumping hazard on a sleeping or
   unpowered board with a live loom.

5. **A non-compliant USB brick used to backfeed the 5 V rail — now cut
   off.** VBUS reaches +5V through PF2 and D5, and the buck can source but
   not sink, so a brick that negotiated 9 V put ~8.4 V on the rail — over
   the TJA1051's 6 V absolute maximum. Fixed with a TLV431 + AO3401 series
   cutoff tripping at 5.77 V (the same recipe as the sensor-rail switch):
   re-simulated, a compliant 5 V source passes at 4.99 V, the switch opens
   at 5.95 V of brick, and the rail never exceeds 5.2 V from anything up
   to 14 V. Off-the-shelf OVP parts were rejected first — the TPS25200
   class cuts off near 7 V, which is no protection for a 6 V limit.

**Second-round studies** (also in `gen/simulate.py`):

- **Battery-connect inrush**: the 760 µF bank charges through Q1's body diode
  before the LM74700 wakes — **44.0 A peak, 0.274 A²s** of surge and 11.7 mJ
  in the diode over 0.80 ms. The fuse's I²t burden is linear in C, so this is
  the price of the bigger bank: it was 0.20 A²s at 540 µF. A 2 A nano fuse is specified around 1 A²s; verify the exact
  figure on the datasheet at order, but the margin is ~3.6×.
- **Engine crank (ISO 16750-2 profile)**: warm (6.0 V dip) and cold (4.5 V
  dip, 15 ms) both ride through — the bank carries the bottom of the dip and
  the 6.5 V starter plateau sits above the converters' dropout. `PWR_FAIL`
  asserts exactly once per crank; the 1 M hysteresis prevents chatter, so
  firmware sees one clean "close the file" event per start.
- **Monte Carlo tolerances** (20 000 samples): power-fail trip lands in
  10.72–11.29 V at 99.8 %; the 0.1 % analog divider stack holds gain error
  to ±0.08 %; +5 V spans 4.85–5.15 V and +3V3 spans 3.19–3.38 V worst-case;
  the battery monitor's 1 % divider is ±1.9 % — calibrate it in firmware.
  Ride-through on a **flat battery** (bank starting at the 10.7 V trip point
  rather than 13.5 V) is 78 ms median and **51 ms at the 0.1 % corner** with
  caps −20 % and load +40 %. That is the number firmware has to fit inside,
  not the 154 ms of §2 — which assumes a healthy battery.

**What it does not cover.** The LM5164's control loop. It is a constant-on-time
part with an encrypted TI model, so the buck deck drives the power stage at an
ideal duty cycle: it answers what the passives have to survive, not whether the
loop is stable or how it recovers from a load step. That needs TI's PSpice
model.

`audit_pcb.py` reads the routed board and checks rail current capacity against
IPC-2221, copper inside the antenna keepout, how far each bypass capacitor sits
from the pin it bypasses, dissipation against the copper and thermal vias under
each converter, and drilled holes that overlap. That last check exists because
DRC only compares holes on *different* nets: two vias of the same net can sit
on one point and pass, and the fab then drills it twice.

The decoupling check is what found the two placement defects fixed here — the
+3V3 converter had no input capacitor of its own and was reaching 12.6 mm
across to the +5 V island's pair, and the CAN transceiver's +5 V bypass sat
8.8 mm from its supply pin. Both now sit at their pins, pinned by `PIN_FIXED`
in `gen/generate_pcb.py` so the zone packer cannot drift them again.

### Firmware in the loop

A third script runs the **firmware itself** and feeds it inputs:

```
python gen/simulate_firmware.py
```

The sketch is compiled unmodified for the PC against shims for Arduino,
FastLED, NimBLE, Wire, SD_MMC and TWAI, on a virtual clock, over a model of
this board — which GPIO is really wired to what, the divider ratios, the
switched sensor rail, the ADC ceiling, the power-fail detector and the
ride-through budget. Scenarios inject CAN frames, sensor voltages, BLE
connect/subscribe events and harness collapse. `fwsim/README.md` documents it,
including what it cannot see.

It exists because ERC, DRC and ngspice all pass on a board whose firmware
reads the wrong pin. A wrong GPIO number is not a compile error; it is a board
that boots, prints happy status lines, and measures nothing.

**The control.** `firmware/vendor/` holds a verbatim copy of the shift-light +
wideband sketch running in the MINI today. Study 1 requires the harness to
agree that it is clean on its own hardware before any claim it makes about
this board is worth reading.

**What it found.** Run unmodified on this board, that known-good firmware has
five defects, none of them bugs in it — every one is a pin that means
something different here:

| | |
|---|---|
| WS2812 data | drives `GPIO4`, which is `AIN3` here. The strip is on `GPIO48`; the shift light is dark for the entire run |
| TWAI TX/RX | `GPIO5`/`GPIO6` are `AIN4` and `VBAT_SNS` here. No frame ever arrives, and the CAN controller drives two analog inputs |
| I²C (ADS1115) | `GPIO7`/`GPIO8` are `SD_PWR_EN` and `SD_CD` here. Selecting the 16-bit converter from the phone toggles the microSD supply |
| `DIVIDER_GAIN` | 2.0 is the reciprocal of that board's 10k/10k. This front end is 0.5769, so every wideband reading is **17 % high**, and the sketch's own 5.5 V clamp then silently truncates the top of the range |
| `+5VS` | switched and off at reset. Nothing on the sensor harness reads anything until `SENS_EN` goes high, which that firmware never does |

Plus the power-fail contract above, which that board has no signal for.

**The port.** `firmware/esp32_shiftlight_wideband/` is the same firmware with
those fixed, plus SD logging and the `PWR_FAIL` path. It passes all 49 checks.
Study 11 is what sized the shutdown: it swept card latency and caught a
redundant `flush()` before `close()` in the shutdown path — two full card
writes instead of one — which had cut the tolerable card latency roughly in
half. `sim/firmware.png` plots the shift light tracking CAN and the
ignition-off sequence.

### Assembly and mechanics

Two checks that no ERC, DRC or SPICE run reaches, both added because the
capacitor change made them relevant.

**Stencil** (`gen/audit_paste.py`). Paste release is governed by IPC-7525's
area ratio; below ~0.66 the paste stays in the aperture and the joint starves.
The worst aperture here is **1.04** at JLC's standard 0.12 mm foil, so the
0.5 mm-pitch USB-C is comfortable. At the other extreme, a large exposed pad
given a solid aperture floats the part on molten solder: the three that matter
are already windowed in the library footprints — `U5` to **48 %** across nine
apertures, `U3` and `U4` to **44 %** across four each. Both converters sit
slightly under the 50 % guide, which is safe for assembly and marginally thin
for heat transfer; noted rather than changed.

**Vibration** (`gen/audit_mechanical.py`). The ride-through capacitors are
16 mm cans standing 22 mm off the board on two solder joints each — the
tallest, heaviest parts on it, and 1.58× the overturning moment of the
16 × 17.5 mm cans they replaced. Screened against ISO 16750-3 body-mount
random vibration: first mode ~272 Hz, 26.6 Grms response by Miles' equation,
0.267 mm of 3-sigma deflection against a **0.44 mm** Steinberg 10⁷-cycle
limit. It passes, with **1.7×** margin — thin enough that a bead of RTV or
epoxy staking each can at assembly is cheap insurance, and the script says so.
These are screening calculations with their assumptions printed; they say
"fine", not "qualified".

### External DFT review

An automated design-for-test review (tomachie, 85/100) was run on the design.
Three findings became hardware: **test points on SD_CLK/SD_CMD** (the SD bus
is the most likely bring-up debug target and was otherwise unprobeable),
**a second USBLC6 on the USB-C CC pins** (first contacts to mate on every
plug insertion, previously bare), and **two SRV05-4 arrays on the card-slot
contacts** (swapped by hand constantly; only the ESP32's ~2 kV pin diodes
stood behind them).

The rest was triaged and declined deliberately: its "unconnected J9 pin 4"
is a pin-type classification of the FET-switched SD_VDD (the `PWR_FLAG`
case, verified connected on copper); PWR_FAIL/SENS_EN/I2C/SPI/UART "missing
test points" are already on 0.1" headers, which beat test points; IPC-7351B
footprint renaming, ATE isolation resistors on the buttons, bed-of-nails
coverage scores and boundary scan are production-line concerns that a
prototype run priced for flying-probe does not buy anything from.

### Bring-up

[`docs/PREORDER.md`](docs/PREORDER.md) is the checklist to work through
**before** uploading `fab/` — what has been checked, what has not, and the
handful of things only JLC's own DFM report can tell you.

[`docs/BRINGUP.md`](docs/BRINGUP.md) is the staged first-power checklist —
every step carries the expected value and points back at the simulation
study that derived it. `fab/board.step` is the full 3D model for designing
the dash enclosure around.

### Ordering note: BOM part-number coverage

`fab/bom.csv` is in JLCPCB's format (`Comment,Designator,Footprint,JLCPCB
Part #`), and BOM/CPL designators are machine-verified to agree. All 70
lines carry a part number — the 30 specific ones checked against the live
catalogue, and the 40 generic R/C filled in from what JLC's own matcher chose
on a real order run. **Nothing is left to pick by hand, and nothing is left to
fuzzy-matching.** The nine lines that used to be blank were
filled in on 2026-08-13, after a real order run showed what the fuzzy matcher
does when the field is empty. Never guess a C-number into the file -- a wrong
part number assembles the wrong part, and two of the ones already in here
turned out to be exactly that.

**Three parts are deliberately absent from `fab/`** and are hand-fitted:
`C3`, `C6` and `C7`, the bulk and ride-through electrolytics. JLCPCB's SMD
aluminium electrolytic library stops at **47 µF** once 100 V is required, so
there is no part to order: `C3` matched nothing at all, and the only offer for
`C6`/`C7` was `C3034842`, a **through-hole** radial can on an SMD land
pattern. Buy all three separately and solder them yourself — they are the
largest parts on the board and the easiest to hand-solder. This is not a
consequence of the 220 → 330 µF change; the 220 µF part was equally
unavailable, and nobody had run a catalogue match to find out.

## 11. Handoff — remaining work

**Schematic is done.** Do not redesign power/CAN/analog unless a datasheet
conflict appears. Edit `gen/generate_schematic.py` only; then
`python gen/generate_schematic.py && python gen/validate.py`.

**The board is finished.** 341 of 341 connections routed, **zero DRC errors,
zero unconnected**: 1432 tracks, 249 vias, solid GND and +3V3 pours, every net
at its netclass width. Rebuild it any time with `python gen/build_board.py --freerouting freerouting.jar` —
placement, plane vias and the buck loops are deterministic, so the only thing
that varies between runs is the autorouter's solution for the signals, and
stage 8 closes out whatever it leaves.

The 105 remaining DRC findings are all `warning`-severity silkscreen overlap
on a board with 206 parts in 84 x 100 mm. Reference designators are at 0.8 mm,
the floor for both the board's own text rule and JLC's silkscreen, and values
are hidden. Nothing here affects fabrication or assembly.

### Ordering it from JLCPCB, step by step

Everything you upload is already in `fab/`. Regenerate it any time with
`python gen/export_fab.py`.

**1 — Upload the board.** At [jlcpcb.com](https://jlcpcb.com), *Order now*,
then *Add gerber file* and give it `fab/esp32s3-can-sd-logger-gerbers.zip`.
It will read 84 x 100 mm and 4 layers off the files.

**2 — Board options.** Everything not listed here can stay at its default.

| Option | Set it to | Why |
|---|---|---|
| Layers | 4 | detected automatically |
| PCB Qty | 5 | the cheapest quantity, and this is a first run |
| Thickness | 1.6 mm | what the stackup assumes |
| Impedance control | **No** | nothing here is fast enough to need it — see below. Leaving it off also keeps you on JLC's default 4-layer 1.6 mm stackup, JLC04161H-7628, which is what the board is built to anyway |
| Surface finish | **ENIG** | worth the few extra dollars — HASL leaves an uneven surface, and the USB-C and the module are 0.5 mm pitch |
| Outer copper | 1 oz | |
| Remove order number | "Specify a location" or Yes | otherwise they print their job number wherever they like |

**Why no impedance control.** It is the option people reach for on a
4-layer board, and this one does not need it. The ESP32-S3's USB is
**full-speed only** (12 Mbps, no high-speed PHY), and at those edge rates a
trace has to run past roughly 100 mm before it behaves like a transmission
line — `USB_DM` is 30 mm and `USB_DP` 27 mm. CAN at 1 Mbps has edges measured
in tens of nanoseconds against a 49 mm run, and the SD bus is 40 MHz over
10 mm with 33 Ω series damping already fitted. There is no RF on the board;
the antenna is inside the module. Turning impedance control on would cost more
and pin the stackup you were going to get regardless.

**3 — Turn on assembly.** Switch *PCB Assembly* on. Assembly side **Top**,
quantity 5, tooling holes *Added by JLCPCB*. Every part is on the top face.

**4 — Upload the parts files.** BOM is `fab/bom.csv`, CPL (they may call it
"pick and place") is `fab/positions.csv`. Both list the same **167
designators** — they have to, because JLC pairs them up by designator and
anything present in one and missing from the other simply does not get
assembled. The eight through-hole connectors are deliberately in neither
file; you solder those yourself, so there is nothing to mark "do not place".

**The BOM's part-number column must be headed `JLCPCB Part #`.** That is the
only name JLC reads. Head it `LCSC` and the column is silently ignored, every
line falls through to the fuzzy text matcher, and you get offered a mechanical
limit switch for a Schottky diode named "40V 1A" and a real WS2812 LED for a
header named WS2812. Both happened.

**5 — Match the parts.** All **70** lines arrive with a part number and match
themselves. **There is nothing to pick.** Most carry a specific
manufacturer part number and should match on it — the rest are generic
passives where any equivalent will do.
Take *Basic* parts over *Extended* where the value and package match; Extended
parts add a setup fee each. Two things to hold to: the 0.1 % divider resistors
(`R43`–`R62`) must stay **0.1 %**, that tolerance is the whole point of the
analog front end, and `C3`/`C6`/`C7` (the bulk and ride-through electrolytics) must stay **100 V** rated.

**6 — Check the placement preview, carefully.** This is the step that bites
people. JLC's library orients some packages differently from KiCad, so
polarised parts can come back rotated 180°. Look hard at every diode (`D1`–
`D14`), the electrolytics `C3`/`C6`/`C7`, the LEDs, and the ICs, and correct any that
face the wrong way in their previewer. Everything else is symmetrical and
cannot go on backwards.

**7 — Order.** Roughly two weeks including assembly.

### The eight parts you solder yourself

JLC places all 167 surface-mount parts. These eight are through-hole, and
through-hole assembly is a separate, pricier service — it is easier to buy
them and solder them yourself. They are large, widely spaced, and a good
first soldering job.

| Ref | Part |
|---|---|
| `J1` | 4-pin JST-PH — power and CAN harness |
| `J10` | 8-pin JST-PH — sensor harness |
| `J3` `J4` `J5` `J6` `J7` `J8` | 0.1" pin headers — UART0, I²C/Qwiic, SPI, WS2812, spare IO, rail break-out |

The mounting holes, the 13 solder jumpers and the 7 test points are bare
copper, not parts — nothing to fit.

### After the boards arrive

Before connecting anything to a car: put a bench supply on `J1` at **12 V with
the current limit set to 100 mA**, and check `TP3` (+VBAT), `TP4` (+5 V),
`TP5` (+3V3) and `TP6` (+5VS) with a meter, against ground on `TP7`.
(`TP1` and `TP2` are the converters' power-good outputs, not rails — both
should read high once the rails are up. The full map is `TP1` PG_5V, `TP2`
PG_3V3, `TP3` +VBAT, `TP4` +5V, `TP5` +3V3, `TP6` +5VS, `TP7` GND, `TP8`
SD_CLK, `TP9` SD_CMD, `TP10` CAN_H, `TP11` CAN_L.) If a rail is wrong or the supply
hits its limit, nothing is damaged. Then set the jumpers for your sensors
per the table in §3 if you need something other than the default. The `RANGE`
jumpers ship **bridged 1-2, the 0–5 V range**, which is what almost every
automotive sensor wants and what the firmware's `DIVIDER_GAIN` assumes.

### This board has never been fabricated

Rev B has been checked as hard as software can check it — ERC, DRC, a
datasheet review that caught five real defects (§7), and part-by-part JLC
sourcing — but no one has yet held one. Treat the first order as a
prototype run: build a few, not fifty.

**Firmware exists now** — `firmware/esp32_shiftlight_wideband/`, ported from
the R53 shift-light sketch and passing all 31 firmware-in-the-loop checks
(§10). It covers TWAI, the WS2812 header on GPIO48, the wideband on the
internal ADC and the ADS1115, microSD logging and the `PWR_FAIL` shutdown
path. The GPIO map in §6 is still the contract, and `fwsim/` now enforces it.

**Still out of scope:** the SPI client breakout, the three spare-IO pins, and
anything the simulator explicitly cannot see — the radio, USB, FreeRTOS
scheduling and flash wear (`fwsim/README.md`). None of it has run on real
silicon; the firmware has never been flashed to a board, because no board
exists yet.

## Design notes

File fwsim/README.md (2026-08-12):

# fwsim — running the firmware, not just the circuit

`gen/simulate.py` answers what the **circuit** does. This answers what the
**firmware** does on top of it.

That is a different question, and on a board whose GPIO map is not the one the
code was written against it is a more dangerous one. A wrong pin number is not
a compile error. It is a board that boots, prints cheerful status lines once a
second, and measures nothing.

```sh
python gen/simulate_firmware.py                 # everything
python gen/simulate_firmware.py --only port     # one study
python gen/simulate_firmware.py --sketch r53    # just the original
```

## How it works

The sketch is compiled **unmodified** for the host against shims in `shim/`
that implement the Arduino, FastLED, NimBLE, Wire, SD_MMC and TWAI calls it
makes. Under the shims sits a model of the board. `runner.cpp` calls `setup()`
once and `loop()` until the scenario ends.

Two ideas carry the whole thing.

**Time is virtual.** `delay(20)` does not sleep, it advances a counter, and so
does every modelled cost: a WS2812 refresh, an I²C transaction, an ADC
conversion, a card flush. A minute of driving runs in milliseconds and runs
identically every time. It also means the numbers are only as good as those
costs — they are listed in `sim.cpp` and are the first thing to argue with if a
timing result looks wrong.

**The board is a model, not an assumption.** A GPIO is not a number, it is
whatever the schematic hung on it. Reading an ADC on a pin this board uses as
the microSD supply enable does not return a value, it returns a fault. Two
profiles are built in, both from README §2, §3 and §6:

| Profile | What it is |
|---|---|
| `s3zero` | Waveshare ESP32-S3-Zero, SN65HVD230, 10k/10k on the wideband — what the R53 sketch was written for |
| `autosport` | this board |

`s3zero` exists to be the control. Before the harness is allowed to say
anything about the new board, study 1 requires it to agree that the shipping
R53 firmware — known-good, running in a car right now — is clean on its own
hardware. A harness that fails that check is broken, whatever else it reports.

## Scenarios

A scenario is a line-based text file. Bare directives configure the run; lines
beginning `@<ms>` are events applied at that moment in simulated time.

```
board autosport
duration 3000
trace 2                 # trace sample period, ms

@0    vbat 13.8         # harness volts; drives PWR_FAIL and the ride-through
@0    sensorrail 1 5vs  # channel 1 is excited from the switched +5VS rail
@0    range 1 r5v       # jumper: bypass | r5v | r16v
@0    canid 0x316
@0    canrate 100       # frames/s from the generator, 0 stops it
@0    rpm 3000          # what the generator encodes
@500  ble connect
@600  ble subscribe 1
@1500 vbat 0.0          # ignition off
```

Other commands: `canframe <id> <dlc> <bytes...>` injects one raw frame,
`busoff` forces the bus-off state, `sensor <ch> <volts>` sets a source,
`ads 0|1` fits or removes the ADS1115, `ble hwmode <n>` / `ble disconnect` /
`ble initfail 1`, `sdflush <ms>` and `sdstall 0|1` set card latency.

Each run writes four files to `sim/fw/`: the scenario, a `.csv` trace, a `.log`
of the firmware's own serial output with virtual timestamps, and
`.faults.txt`. Every number in the report can be re-derived from them.

## How good are these tests?

Measured, not asserted. `gen/mutate_firmware.py` takes the ported firmware,
introduces sixteen real defects one at a time -- a constant carried over from
the other board, a deleted line, a transposed pin -- rebuilds, and re-runs the
studies against each mutant. A defect that still passes is a hole in the
suite, not a harmless change.

The first run caught **7 of 16 (44 %)**, and the survivors all had one shape:
the LED bands, the stale blanking, the bus-off recovery and the notify gating
were only ever exercised against the vendored R53 sketch on the `s3zero`
model. The ported firmware inherited the confidence without ever being asked.
Studies 13 and 14 exist because of that, and the suite now catches **16 of 16**.

Run it after changing the firmware or the studies:

```sh
python gen/mutate_firmware.py          # ~5 min, rebuilds per mutation
python gen/mutate_firmware.py --list   # what it tries
```

Two of the sixteen only fail because a check asserts on *warnings*, not just
errors -- a WS2812 buffer left floating at boot, a card unmounted by pulling
its supply. Both are legal C++ that a compiler and a DRC are equally blind to.

## Findings

Faults are recorded once per (code, message) pair, so a bug inside a 20 ms loop
produces one line and not three thousand. Severity is `ERROR` (this does not
work on this board), `WARN` (works, but is storing up trouble) or `note`.

The runner exits non-zero if any `ERROR` was recorded, so a scenario can be a
CI gate.

## What it does not cover

The shims model the **API contract**, not the implementation. A bug inside
NimBLE will not appear here, and neither will a stack overflow, a heap
fragmentation failure, an RMT peripheral conflict, FreeRTOS scheduling, flash
wear or anything about the radio. There is no Xtensa instruction set involved —
this is the sketch's logic compiled for x86.

It answers questions about the firmware's own logic and its fit to the
hardware. For anything below that line the answer is still a board on a bench.

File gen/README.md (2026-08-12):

# The generator pipeline

Everything in this project is generated: the Python in this directory is the
source of truth and every `.kicad_sch` / `.kicad_pcb` / `fab/` / `plots/`
file is a build artifact. Nothing is ever hand-edited in KiCad — if it were,
the next regeneration would silently discard it. This file documents how the
pipeline works and, more importantly, the rules that were learned the hard
way, so the next boards can reuse all of it. The intended flow for a new design is at the bottom of this file.

## The one-command loops

```
# schematic loop (any Python 3)
python gen/generate_schematic.py && python gen/validate.py

# board loop (needs KiCad 9 installed, freerouting.jar in the repo root)
python -u gen/build_board.py --passes 60

# the checks DRC cannot make (after a build)
"C:\Program Files\KiCad\9.0\bin\python.exe" gen/audit_pcb.py
python gen/simulate.py            # needs ngspice, numpy, matplotlib

# outputs
python gen/export_plots.py        # schematic.pdf + three board renders
"...\bin\python.exe" gen/export_fab.py   # JLCPCB gerbers/BOM/CPL
```

## What each file owns

| file | owns |
|---|---|
| `generate_schematic.py` | the part and net tables (the design itself), sheet packing, symbol/wire/label emission, netclasses, title blocks |
| `sch_blocks.py` | hand-drawn schematic layouts for every recurring circuit — coordinates only, no electrical content |
| `generate_pcb.py` | board outline, placement zones, fixed placements (`FIXED`, `BUCK_FIXED`, `PIN_FIXED`), planes, keepouts |
| `build_board.py` | the 10-stage build driver, with a lock so two builds cannot fight |
| `route_bucks.py` | hand-shaped copper for the switching loops |
| `finish_routing.py` | ties for duplicated connector pins (runs before AND after autorouting) |
| `stitch_planes.py` | a via from every GND/+3V3 pad to its plane, with hole-collision checks |
| `maze_route.py` | rip-up-and-retry router for whatever freerouting leaves open |
| `tidy_silk.py` | reference designator declutter; touches no copper |
| `validate.py` | compares KiCad's own netlist node-for-node against `netlist.txt`, runs ERC |
| `audit_pcb.py` | current capacity, antenna keepout, decoupling distance, thermal, drill overlaps |
| `simulate.py` | twelve ngspice/numpy/scipy studies of the circuits themselves |
| `audit_routes.py` | post-route extraction: IR drop over the real copper, bus lengths/skew, SW-node area |
| `audit_straps.py` | every ESP32 strapping pin's state at reset vs what the netlist hangs on it |
| `overstress.py` | closed-form worst-case for every external input |
| `export_plots.py` | schematic.pdf + board renders (top, back, iso) into `plots/` |
| `export_fab.py` | JLCPCB gerber zip, BOM csv, CPL csv into `fab/` (KiCad python) |

## Design rules the pipeline enforces mechanically

- Parts are identified by **(sheet, value, exact pad-net signature)**
  everywhere — placement tables, schematic blocks, buck routing. References
  renumber on every run and must never be used as keys.
- Values are **display-short** ("600R", "0.2A PTC", "AO3401A"); ratings live
  in the hidden Voltage/Tolerance/Note/MPN fields. `split_value()` separates
  voltage and tolerance automatically. Because values are matching keys, a
  value rename must be applied to `generate_schematic.py`, `sch_blocks.py`,
  `generate_pcb.py` and `audit_pcb.py` in the same commit.
- Every recurring or nontrivial circuit gets a **hand-drawn block** in
  `sch_blocks.py`. The column packer is only for true one-liners (bypass
  caps, single pull-resistors that belong to no connector) — anything that
  reads as "parts floating in space" should be blocked or attached.

## How to draw a schematic block (the hard-won rules)

A block is a dict: `sheet`, `anchor` (value, netset), `parts`
[(value, netset, dx, dy, rot)], `wires` [polylines], `junctions`, `rails`
[(net, x, y, facing)], `labels` {net: (x, y, angle)}. All coordinates are
mm relative to the anchor, on the **1.27 mm grid** — 12.07 is not a grid
point, 12.70 is; off-grid ends throw ERC "off connection grid" warnings.

**Rotation → pin positions** (sheet coordinates, y grows downward):

- Two-pin R/C/L/fuse (pins 1/2 at lib (0, ±3.81)):
  rot 0 → pin 1 top, pin 2 bottom; rot 180 → flipped;
  rot 90 → pin 1 left; rot 270 → pin 1 right.
- GSD FETs / BEC BJTs (G/B lib (−5.08, 0), D/C (2.54, 5.08), S/E (2.54, −5.08)):
  rot 0 → gate left, drain top, source bottom;
  rot 90 → gate bottom, drain left-top, source right-top;
  rot 270 → gate top, source left-bottom, drain right-bottom.
  The mapping is: rot 270 ≡ (lx,ly)→(ly,lx), rot 90 ≡ (lx,ly)→(−ly,−lx).
- TL431DBZ: A left, K right, REF top (rot 0).

**Connectivity rules** (each of these broke a build before it was learned):

- A wire must **end** at every junction on it. To tap a wire mid-span,
  split it into two wires that both end at the tap point and add a junction
  there. Three or more wire-ends (or wire-ends plus a pin) at one point
  need a junction; exactly two objects sharing an endpoint connect without
  one, and adding a junction to a bare two-object meeting point *breaks*
  the netlist.
- Crossing wires without a junction are legal and do not connect — use
  crossings freely, the way any dense schematic does.
- A wire routed through a third part's **pin point** connects to it. Route
  around pins you do not mean to touch.
- Labels attach anywhere along a wire or at a pin end. One label position
  per net per block. The emitter picks local vs global form automatically
  from whether the net leaves the sheet.
- Pins on power nets (GND, +3V3, +5V, +VBAT, +5VS, VBUS) may simply be
  left unwired: the emitter hangs the right power symbol on them. Only
  signal nets need wires or labels.
- **The anchor keeps its natural rotation** — only member parts get the
  block's `rot`. If the drawing needs a part rotated, that part cannot be
  the anchor (this is why SENSW anchors on the 2N7002, not the P-FET).
- Value text is placed above/below the body; leave a grid step of air
  between parallel runs or the text lands on the neighbouring wire.

**Label and text readability** (learned by zooming into ugly sheets):

- Every private net still needs exactly **one label for its name** — delete
  them all and KiCad silently renames the net `Net-(R5-Pad2)`, which breaks
  name-based netlist comparison and the schematic/board net linkage. But
  the label does not have to sit on the circuit: put it on a **short
  vertical spur** (one wire, one junction) rising into open sheet, angle 90.
- Labels at wire ends must extend **away** from the circuit: angle 180 on a
  left-pointing stub, 0 on a right-pointing one. A label anchored at a left
  stub-end with angle 0 prints its text right across the part it feeds.
- Part pitch on a shared run: **>= 10-12 mm** between centres, more when a
  value is long. Budget a full symbol's width between one part's text and
  the next part's body.
- Every pin that gets an auto GND/power symbol needs **~10 mm of empty
  sheet** beyond it for the symbol body plus its text.
- To actually judge a sheet, render it: `kicad-cli sch export svg`, then a
  headless browser screenshot (`msedge --headless --screenshot=... file:///
  ...svg`), and zoom in. Text collisions are invisible at full-page scale
  and glaring at reading scale — review at the scale a reader uses.

**Never put a control character in any emitted string.** A literal newline
inside a symbol property is accepted by KiCad's loader and then silently
breaks connectivity for every symbol after it in the file — the netlist
drops them with no error pointing anywhere near the cause. The emitter now
flattens all whitespace in properties; keep it that way.

## Writing simulation decks (ngspice gotchas, each cost an hour)

- `tran` picks its own tmax and will step right over ns-scale pulses.
  Always pass it explicitly: `tran <step> <stop> 0 <step>`.
- An "ideal diode" as a tanh-blended behavioral source leaks backward.
  Use a hard clamp: `B1 a b I=max(V(a)-V(b),0)/R_on`.
- An RC delay hung directly on a behavioral comparator output loads it and
  shifts the threshold. Buffer first: `Bbuf buf 0 V=V(comp)`, RC off `buf`.
- LTRA transmission lines go unstable next to coupled inductors; the ideal
  `T` element (`T1 p1 n1 p2 n2 Z0=120 TD=21n`) is solid. Calibrate drivers
  to the datasheet's loaded test condition, not open-circuit levels.
- `wrdata` on an AC vector writes complex pairs. Convert first:
  `let m = mag(v(out))` and write `m`.
- Keep component values in the decks in step with the schematic tables —
  the duplication is deliberate; a disagreement is a bug report.

## Fab outputs, plots, and the ordering package

- JLCPCB BOM header is exactly `Comment,Designator,Footprint,JLCPCB Part #`.
  Basic parts auto-match from the footprint+value; extended parts need a
  real LCSC C-number in the part's `lcsc=` field — **never guess one**.
  Parts without a number get listed in the project README for hand-matching
  in the order UI. Check BOM designator count == CPL count after export.
- `kicad-cli pcb render` needs its rotate argument quoted *inside* the
  string: `["--rotate", "'-30,0,25'"]` — without the inner quotes the
  leading `-` is eaten as a flag.
- STEP model for enclosure work: `kicad-cli pcb export step --subst-models`.
- **NTFS timestamp tunneling:** a regenerated file keeps its old
  CreationTime — even through delete-then-recreate within ~15 s — and
  Explorer's default "Date" column shows CreationTime, so fresh plots look
  stale to the user. After regenerating, stamp them:
  `Get-ChildItem plots | % { $_.CreationTime = $_.LastWriteTime }`.

## Build discipline (how a night of rebuilds went wrong)

- **One build at a time, ever.** The `.build_board.lock` exists for this;
  never put `rm -f .build_board.lock` inside a launch command "to be safe" —
  that is how two autorouters ended up writing the same board file.
- Stopping a build's shell does **not** stop freerouting: the java process
  survives and keeps routing a board that no longer exists. Kill java
  explicitly (`taskkill /F /IM java.exe`) after aborting a build.
- Always launch the driver with `python -u`. Block-buffered stdout means an
  empty log for ten minutes, which is indistinguishable from a hang and has
  caused healthy builds to be killed.
- A placement zone must have **more rect area than the sum of its parts'
  courtyards** (SOT-23 ~12 mm2, 0805 ~7 mm2, plus ~30 % packing loss). The
  shelf packer does not fail when a zone is too small -- it silently spills
  parts onto whatever is below. Watch the post-placement DRC line (the
  early tie stage prints it) instead of waiting ten minutes for routing.
- freerouting runs at below-normal priority (set in build_board.py) so a
  build does not take the machine down with it.

## Verification ladder

Every change climbs the same ladder, and each rung catches a class of
mistake the rung below cannot:

1. `generate_schematic.py` — dies loudly on unmatched block parts.
2. `validate.py` — ERC plus node-for-node netlist comparison.
3. `build_board.py` — DRC to 0 violations / 0 unconnected.
4. `audit_pcb.py` — the physics DRC does not know about.
5. `simulate.py` — does the circuit *work*, across tolerance and abuse.

## Starting a new board from this pipeline

The next boards are dedicated PCBs for **existing, running ESP32 projects**,
so the requirements are not invented — they are extracted:

0. Read the running project's firmware first. The pin map (`#define`s /
   board config), the peripheral drivers it initialises (which buses, which
   sensors, which voltages), and the modules on the current dev-board build
   ARE the part tables. List every external connection the firmware
   touches, then add the infrastructure the dev board was silently
   providing: power input + protection, USB, decoupling, boot straps,
   and (for anything in a vehicle) the ride-through/PWR_FAIL contract so
   firmware can keep its existing shutdown behaviour.

1. Copy `gen/` wholesale; delete the project-specific tables in
   `generate_schematic.py` (sheets/parts) and `generate_pcb.py` (zones,
   FIXED/BUCK_FIXED/PIN_FIXED, HOLES, board size) and `sch_blocks.py`.
2. Write the part tables first; run the schematic loop until validate
   passes with everything column-packed and ugly.
3. Draw blocks for each circuit cluster; re-run the loop after each one.
4. Define zones roughly, build the board, then iterate placement from the
   courtyard-overlap warnings and the renders.
5. Keep `simulate.py`'s decks in step with the schematic tables — the
   component values are duplicated there on purpose, so a disagreement is
   a bug report.
6. Before ordering: full ladder green, `export_fab.py`, BOM==CPL count,
   `docs/BRINGUP.md`-style staged checklist written from the studies'
   expected values, and JLC's free DFM at upload as the last gate.

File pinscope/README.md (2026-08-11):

# Pinscope inputs

[Pinscope](https://github.com/Faradworks/Pinscope) is a datasheet-backed
schematic reviewer: it parses a netlist and BOM into a design graph, pulls pin
tables and limits out of the manufacturers' datasheet PDFs, and reviews each IC
against its datasheet *and* its context in this circuit. It is the one class of
check nothing else here does — KiCad's ERC knows the netlist is self-consistent,
but has no idea whether pin 5 of `U7` is allowed to sit at 3.3 V.

These two files are what it takes as input. Regenerate them whenever the
schematic changes:

```sh
kicad-cli sch export netlist --format pads \
    --output pinscope/esp32-autosport.asc esp32s3-can-sd-logger.kicad_sch
python gen/export_pinscope_bom.py
```

| File | What |
|---|---|
| `esp32-autosport.asc` | PADS-PCB netlist — 168 parts, 107 nets |
| `esp32-autosport-bom.csv` | BOM in Pinscope's column layout (`Reference`, `Manufacturer Part Number`, …) |

Both have been checked against Pinscope's own parsers
(`backend/pinscopex/parsers.py`): format detected as `pads`, 168 parts and 107
nets recovered, `validate_netlist()` returns **no errors**, and every reference
in the netlist resolves in the BOM apart from `TP1`–`TP7`, which are bare
copper pads and correctly absent.

## Running it

Pinscope needs an **Anthropic API key** — it calls the API to read the
datasheets, so a run costs real money, which is why this repo stops at
preparing the inputs.

It has no CLI. The documented route is the web UI on `localhost:3000`, but the
FastAPI backend exposes the whole flow, so it can also be driven with `curl`:

```
POST /projects                        create
POST /projects/{id}/upload/netlist    esp32-autosport.asc
POST /projects/{id}/upload/bom        esp32-autosport-bom.csv
POST /projects/{id}/upload/datasheets the PDFs
POST /pipeline/{id}/estimate          what the run will cost
POST /pipeline/{id}/start
GET  /pipeline/{id}/status
GET  /report/{id}                     findings, with page citations
```

Datasheets are needed for the eight ICs — `U1` LM74700-Q1, `U2`/`U3` LM5164,
`U4` ESP32-S3-WROOM-1, `U5` USBLC6-2SC6, `U6` SN74AHCT1G125, `U7` TJA1051T/3,
`U8` ADS1115 — plus the FETs if you want them covered. Pinscope can fetch them
itself given DigiKey API keys, or take uploaded PDFs.

## What preparing these already found

Nothing to do with Pinscope's analysis — just from making the BOM parse:

- `bom.csv` was written with **seven values against an eight-column header**,
  so the LCSC column was dropped entirely and every note shifted left into it.
  Fixed in `gen/generate_schematic.py`.
- With the LCSC numbers visible again, the sourcing table in the main README
  turned out to have the wrong part for the CAN transceiver: **C58988**, not
  C38695.

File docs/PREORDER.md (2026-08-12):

# Pre-order checklist

Everything worth checking before `fab/` is uploaded and money is spent. Run
top to bottom; each stage says what it proves and, where it can be automated,
the command that does it.

The board has never been fabricated, so the point of this list is not
confidence — it is making sure the *checkable* things have been checked, and
being explicit about what is left resting on judgement.

```sh
python gen/validate.py            # schematic vs netlist.txt, plus ERC
python gen/audit_docs.py          # docs vs design: designators and numbers
python gen/audit_polarity.py      # every polarised part, plus a fab checklist
python gen/simulate.py            # 12 circuit studies (needs ngspice)
python gen/simulate_firmware.py   # 49 firmware-in-the-loop checks
python gen/mutate_firmware.py     # proves those checks would fail if the firmware broke
python gen/audit_paste.py         # stencil apertures: IPC-7525 + thermal-pad coverage
python gen/audit_mechanical.py    # vibration screen for the tall capacitors
"…/KiCad/9.0/bin/python.exe" gen/audit_pcb.py
"…/KiCad/9.0/bin/python.exe" gen/audit_routes.py
"…/KiCad/9.0/bin/python.exe" gen/audit_straps.py
"…/KiCad/9.0/bin/python.exe" gen/overstress.py
```

All of the above pass as of 2026-08-12.

---

## 1. Automated, and currently green

| Check | Script | What it would catch |
|---|---|---|
| Schematic matches the netlist, ERC clean | `validate.py` | a generator edit that did not land |
| Docs match the design | `audit_docs.py` | the `U7`/`U12` class of error, and any number in the README rotting |
| Polarity of every diode, electrolytic, IC | `audit_polarity.py` | a part designed in backwards |
| Circuit behaviour, 12 studies | `simulate.py` | ISO 7637-2 survival, ripple, ride-through, inrush, crank, tolerances |
| Firmware against a model of this board | `simulate_firmware.py` | wrong GPIO, wrong divider constant, an unspent power-fail window |
| Whether those firmware checks are worth anything | `mutate_firmware.py` | a test suite that passes because it asserts nothing — 16 of 16 injected defects caught |
| Stencil apertures | `audit_paste.py` | starved fine-pitch joints; a thermal pad given so much paste the part floats |
| Vibration on the tall parts | `audit_mechanical.py` | solder-joint fatigue on the 22 mm capacitor cans |
| Copper: current capacity, decoupling distance, thermals, overlapping drills | `audit_pcb.py` | a 1 A rail on 0.2 mm track; two vias drilled on one point |
| Routing quality | `audit_routes.py` | |
| Strapping pins | `audit_straps.py` | a boot pin held the wrong way |
| Worst-case part stress | `overstress.py` | a part run past its rating at the clamp level |

## 2. Done by hand this session, worth repeating if parts change

- **Every JLC part number checked against the live catalogue**, one at a time,
  confirming MPN and package. This found `C8544` (an NPN sold as our PNP) and
  `C7975` (a quad op-amp sold as our logic buffer). §7 records the outcome.
  **Repeat this whenever a part number changes** — nothing offline can do it,
  because it is a question about someone else's inventory.
- **Footprint-vs-package sanity**: the catalogue lookup returns a package for
  each part; compare it with the footprint in `bom.csv`. That is what would
  have caught `C7975` (TSSOP-14 against a SOT-23-5 land) even without noticing
  the MPN was wrong.

## 3. Not yet done — worth doing before ordering

Ranked by what they would cost if skipped. Items 1-3 of the original list are
now automated and green (see above); what is left is the part that needs
someone else's data or a physical model.

1. **JLC's own DFM report.** Free at upload, and it checks their actual
   process: minimum annular ring, solder-mask sliver, silkscreen-on-pad,
   acid traps. Nothing here models their fab. **Upload the gerbers and read
   the report before paying** — the single highest-value remaining check, and
   it costs nothing.
2. **Placement preview, part by part.** `audit_polarity.py` prints the 32
   parts that have an orientation with board position and which net pin 1
   sits on. Every polarised part is placed at 0°, so anything that appears
   rotated in JLC's previewer is their library, not this design.
3. **3D clearance against the enclosure.** `fab/board.step` is current, but
   the ride-through capacitors went from 16×17.5 mm to 16×22 mm. Re-check the
   dash enclosure against the new STEP.
4. **A behavioural COT loop model.** `simulate.py` drives the LM5164 power
   stage at an ideal duty cycle because TI's model is encrypted, so loop
   stability and load-step recovery are answered by nothing at all. A
   behavioural constant-on-time model in ngspice would not be silicon-exact
   but would close that gap.
5. **2-D thermal solve at 70 °C ambient.** `audit_pcb.py` does closed-form
   per-part dissipation into copper area; a finite-difference solve over the
   real pours would catch interactions, including whether the taller cans now
   shadow `U3`/`U4`.

## 4. Things that cannot be checked without hardware

State them rather than pretend otherwise:

- **Nothing has been powered on.** Every check in this repository is a
  software check.
- **The LM5164 control loop.** Constant-on-time with an encrypted TI model;
  `simulate.py` drives the power stage at an ideal duty cycle, so it answers
  what the passives survive, not whether the loop is stable or how it recovers
  from a load step. Needs TI's PSpice model or a bench.
- **RF.** The antenna is inside the module and overhangs the board edge; no
  RF simulation was done or is planned.
- **Real ESD and real transients.** Simulated against ISO 7637-2 waveforms,
  never injected.
- **The firmware on real silicon.** `fwsim` models the API contract, not the
  implementation: no NimBLE bug, stack overflow, RMT conflict, PSRAM init
  problem or FreeRTOS scheduling issue can appear in it.
- **`+5VS` accuracy for ratiometric sensors** (§7 item 7), still open.
- **The vibration screen is a screen.** `audit_mechanical.py` idealises the
  board as a simply-supported plate and uses Steinberg's empirical fatigue
  limit. It says "fine with 1.7x margin", not "qualified". Its assumptions are
  printed with every run for exactly that reason.

## 5. Ordering-day gotchas already known

From §11, repeated here because they are the ones that cost money:

- The BOM's part-number column must be headed exactly **`JLCPCB Part #`**.
  Any other name is silently ignored and every line falls through to the
  fuzzy matcher.
- **Check the placement preview for polarity** — see §2 above.
- Take *Basic* over *Extended* where value and package match; Extended parts
  carry a setup fee each.
- `R43`–`R62` must stay **0.1 %**; `C3`/`C6`/`C7` must stay **100 V**.
- The eight through-hole connectors are deliberately in neither the BOM nor
  the CPL. `export_fab.py` now re-execs itself under KiCad's Python to
  guarantee that — it used to return an empty exclusion set when `pcbnew` was
  missing, producing fab files that looked perfect and quietly asked JLC to
  assemble all eight.

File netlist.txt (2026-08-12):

Net connectivity for ESP32-S3 CAN + microSD Automotive Logger rev B
(114 nets)

+3V3           #FLG5.1 C20.2 C22.1 C23.1 C24.1 C27.1 C28.1 C29.1 C36.1 C42.1 D11.2 D13.2 D15.2 D16.2 D2.1 D4.2 D9.2 J3.1 J4.2 J5.1 J8.2 L2.2 Q6.2 R15.2 R18.1 R21.2 R23.1 R24.1 R31.1 R32.1 R33.2 R39.1 R5.1 R53.1 TP5.1 U10.5 U11.5 U12.5 U13.8 U5.2
+5V            #FLG4.1 C11.2 C13.1 C14.1 C15.1 C32.1 C35.1 D5.1 J8.1 L1.2 PF3.1 Q2.2 R12.1 R7.1 TP4.1 U12.3 U9.5
+5VS           #FLG6.1 C25.1 D3.1 FB2.2 J10.1 J10.8 JP11.1 JP2.1 JP5.1 JP8.1 TP6.1
+VBAT          #FLG2.1 C16.1 C17.1 C3.1 C4.1 C5.1 C6.1 C7.1 Q1.3 R10.1 R16.1 R77.1 TP3.1 U1.4 U3.2 U4.2
AIN1           C38.1 D9.3 JP3.2 JP4.2 R59.2 U13.4 U5.39
AIN1_A         JP3.1 R57.2 R58.2 R59.1
AIN1_IN        D8.1 J10.2 R57.1
AIN1_PU        JP2.2 R58.1
AIN1_R1        JP4.1 R60.1
AIN1_R2        JP4.3 R61.1
AIN2           C39.1 D11.3 JP6.2 JP7.2 R64.2 U13.5 U5.38
AIN2_A         JP6.1 R62.2 R63.2 R64.1
AIN2_IN        D10.1 J10.3 R62.1
AIN2_PU        JP5.2 R63.1
AIN2_R1        JP7.1 R65.1
AIN2_R2        JP7.3 R66.1
AIN3           C40.1 D13.3 JP10.2 JP9.2 R69.2 U13.6 U5.4
AIN3_A         JP9.1 R67.2 R68.2 R69.1
AIN3_IN        D12.1 J10.4 R67.1
AIN3_PU        JP8.2 R68.1
AIN3_R1        JP10.1 R70.1
AIN3_R2        JP10.3 R71.1
AIN4           C41.1 D15.3 JP12.2 JP13.2 R74.2 U13.7 U5.5
AIN4_A         JP12.1 R72.2 R73.2 R74.1
AIN4_IN        D14.1 J10.5 R72.1
AIN4_PU        JP11.2 R73.1
AIN4_R1        JP13.1 R75.1
AIN4_R2        JP13.3 R76.1
BST_3V3        C19.1 U4.7
BST_5V         C10.1 U3.7
CANH_T         L3.1 U12.7
CANL_T         L3.3 U12.6
CAN_H          D6.1 J1.3 JP1.1 L3.2 TP10.1
CAN_L          D7.1 J1.4 L3.4 R56.2 TP11.1
CAN_RX         U12.4 U5.11
CAN_S          R54.1 U12.8 U5.23
CAN_SPLIT      C37.1 R55.2 R56.1
CAN_TX         U12.1 U5.10
EN_3V3         C18.1 R16.2 U4.3
EN_5V          C9.1 R10.2 U3.3
FB_3V3         C21.2 R18.2 R19.1 U4.5
FB_5V          C12.2 R12.2 R13.1 U3.5
GATE_RB        Q1.1 U1.5
GND            #FLG1.1 C13.2 C14.2 C15.2 C16.2 C17.2 C18.2 C2.2 C22.2 C23.2 C24.2 C25.2 C26.2 C27.2 C28.2 C29.2 C3.2 C30.2 C31.2 C32.2 C33.2 C34.2 C35.2 C36.2 C37.2 C38.2 C39.2 C4.2 C40.2 C41.2 C42.2 C43.2 C5.2 C6.2 C7.2 C8.2 C9.2 D1.2 D10.2 D11.1 D12.2 D13.1 D14.2 D15.1 D16.1 D2.2 D3.2 D6.2 D7.2 D8.2 D9.1 J1.2 J10.6 J10.7 J2.A1 J2.A12 J2.B1 J2.B12 J2.S1 J3.4 J4.1 J5.2 J6.3 J7.6 J8.3 J8.4 J9.10 J9.6 Q3.2 Q7.2 R11.2 R13.2 R17.2 R19.2 R2.2 R22.2 R25.2 R26.2 R27.2 R30.2 R36.2 R37.2 R38.2 R4.2 R41.2 R54.2 R60.2 R61.2 R65.2 R66.2 R70.2 R71.2 R75.2 R76.2 R78.2 R9.2 SW1.2 SW2.2 TP7.1 U1.2 U10.2 U11.2 U12.2 U13.1 U13.3 U2.3 U3.1 U3.9 U4.1 U4.9 U5.1 U5.40 U5.41 U6.3 U7.2 U8.2 U9.1 U9.3
I2C_SCL        J4.4 R32.2 U13.10 U5.32
I2C_SDA        J4.3 R31.2 U13.9 U5.31
IO3            J7.1 R36.1 U5.15
IO45           J7.2 R37.1 U5.26
IO46           J7.3 R38.1 U5.16
LED_5V         J6.1 PF3.2
LED_DIN        R35.1 U9.4
LED_DIN_A      R34.2 U9.2
LED_DIN_J      J6.2 R35.2
LED_DIN_MCU    R34.1 U5.25
MCU_BOOT       R24.2 SW2.1 U5.27
MCU_EN         C26.1 R23.2 SW1.1 U5.3
PFD_SENSE      C8.1 R3.2 R4.1 R6.2 U2.2
PG_3V3         R21.1 TP2.1 U4.6
PG_5V          R15.1 TP1.1 U3.6
PWR_FAIL       J7.4 R5.2 R6.1 U2.1 U5.8
PWR_LED_K      D4.1 R22.1
RAMP_3V3       C20.1 C21.1 R20.2
RAMP_5V        C11.1 C12.1 R14.2
RON_3V3        R17.1 U4.4
RON_5V         R11.1 U3.4
SD_CD          J9.9 R53.2 U11.4 U5.12
SD_CLK         R42.1 U5.22
SD_CLK_C       J9.5 R42.2 TP8.1 U10.1
SD_CMD         R43.1 U5.21
SD_CMD_C       J9.3 R43.2 R48.2 TP9.1 U10.3
SD_D0          R44.1 U5.20
SD_D0_C        J9.7 R44.2 R49.2 U10.4
SD_D1          R45.1 U5.19
SD_D1_C        J9.8 R45.2 R50.2 U10.6
SD_D2          R46.1 U5.18
SD_D2_C        J9.1 R46.2 R51.2 U11.1
SD_D3          R47.1 U5.17
SD_D3_C        J9.2 R47.2 R52.2 U11.3
SD_EN_G        Q7.1 R40.2 R41.1
SD_PG          Q6.1 Q7.3 R39.2
SD_PWR_EN      R40.1 U5.7
SD_VDD         #FLG8.1 C33.1 C34.1 J9.4 Q6.3 R48.1 R49.1 R50.1 R51.1 R52.1
SENS_EN        J7.5 R8.1 U5.9
SENS_EN_G      Q3.1 R8.2 R9.1
SENS_G         Q2.1 Q3.3 R7.2
SPI_CS         J5.6 R33.1 U5.24
SPI_MISO       J5.4 U5.34
SPI_MOSI       J5.5 U5.35
SPI_SCK        J5.3 U5.33
SW_3V3         C19.2 L2.1 R20.1 U4.8
SW_5V          C10.2 L1.1 R14.1 U3.8
TERM_A         JP1.2 R55.1
UART_RX        J3.3 U5.36
UART_TX        J3.2 U5.37
USB_CC1        J2.A5 R25.1 U8.1
USB_CC2        J2.B5 R26.1 U8.3
USB_DM         U5.13 U7.4
USB_DM_CON     J2.A7 J2.B7 U7.3
USB_DP         U5.14 U7.6
USB_DP_CON     J2.A6 J2.B6 U7.1
VBAT_F         D1.1 F1.2 FB1.1 R3.1
VBAT_FB        #FLG3.1 C1.2 C2.1 FB1.2 Q1.2 R1.1 U1.6
VBAT_IN        F1.1 J1.1
VBAT_SNS       C43.1 D16.3 R77.2 R78.1 U5.6
VBAT_UVLO      R1.2 R2.1 U1.3
VBUS           #FLG7.1 C30.1 C31.1 D5.2 Q4.3 U7.5 U8.5
VBUS_G         Q4.1 Q5.3 R27.1
VBUS_IN        J2.A4 J2.A9 J2.B4 J2.B9 PF2.1
VBUS_OV        Q5.1 R28.2 U6.1
VBUS_OVS       R29.2 R30.1 U6.2
VBUS_R         PF2.2 Q4.2 Q5.2 R28.1 R29.1
VCAP           C1.1 U1.1
VSENS_F        FB2.1 PF1.2
VSENS_SW       PF1.1 Q2.3

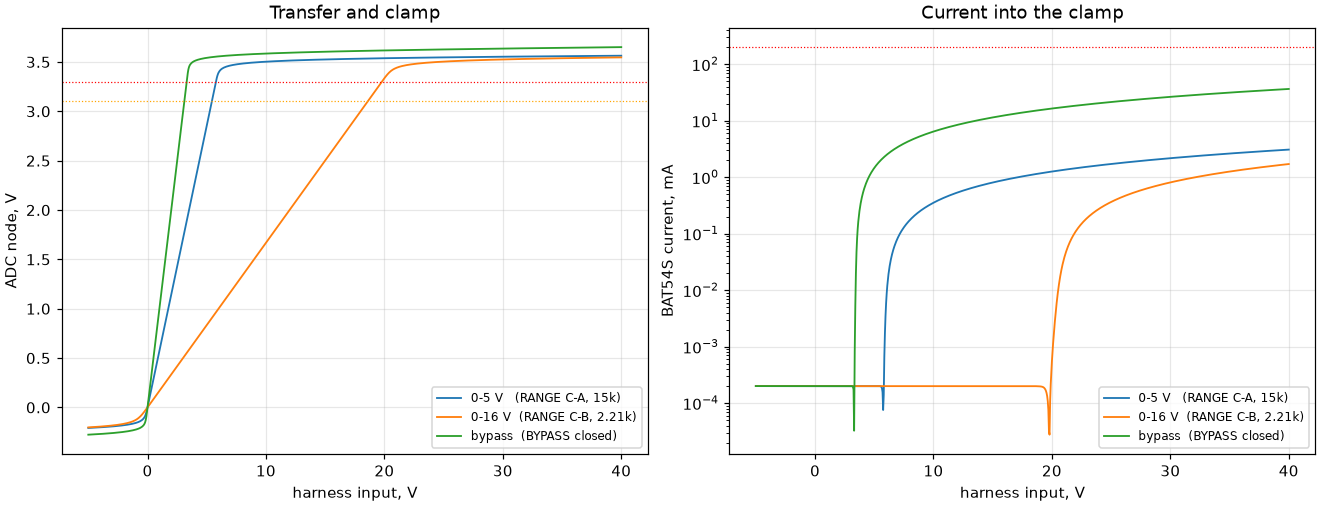
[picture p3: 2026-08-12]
sim/analog.png

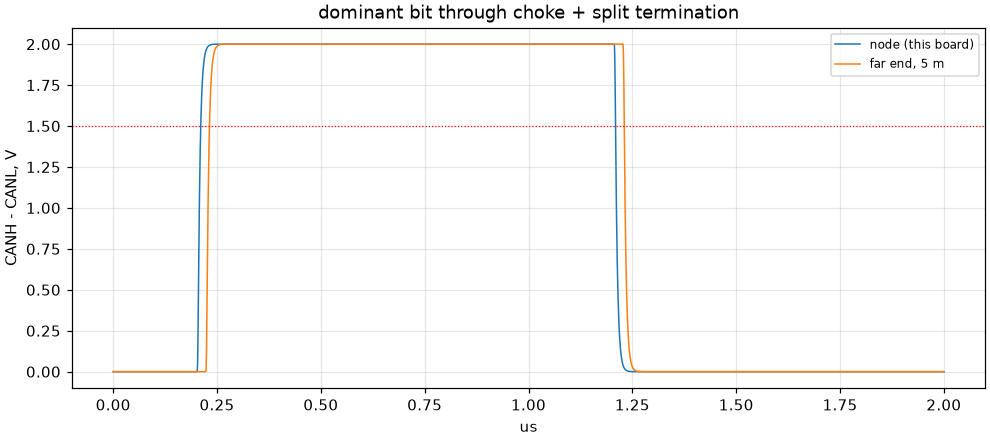
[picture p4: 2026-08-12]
sim/canbus.png

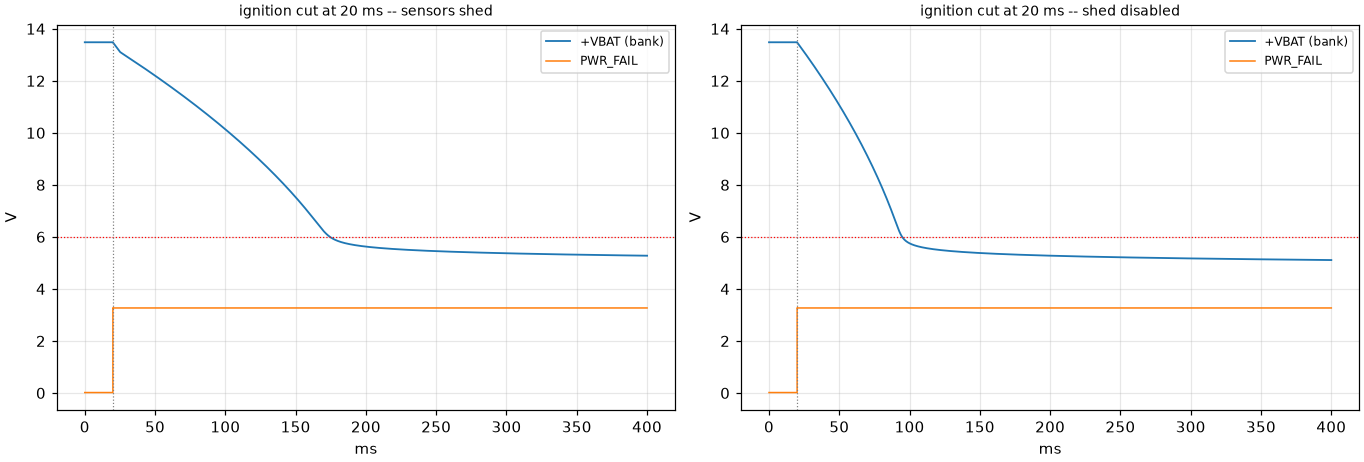
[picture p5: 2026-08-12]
sim/ridethru.png

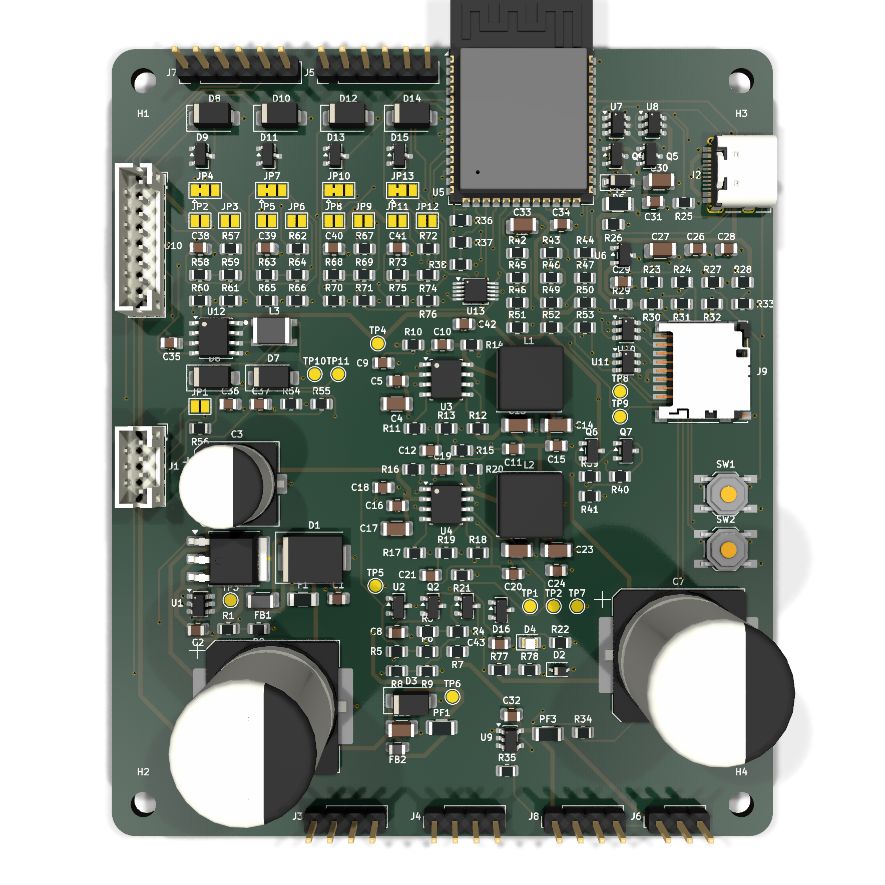
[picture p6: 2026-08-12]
plots/board-routed.png

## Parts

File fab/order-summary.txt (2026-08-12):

Parts order for 5 boards
========================================

1. From LCSC -- paste fab/order-lcsc-paste.txt into their
   quick-order box, or upload order-lcsc-simple.csv.
   Order quantities are already rounded up to LCSC's
   minimum order quantity and order multiple.

   part          order  needed  comment            designators
   C49678          100      75  100nF 16V          C15,C24,C28,C29,C31,C32,C34,C35,C36,C38,C39,C4
   C17414          100      75  10k                R23,R24,R28,R33,R36,R37,R38,R48,R49,R5,R50,R51
   C149504         100      65  100k               R1,R10,R12,R15,R16,R18,R21,R27,R39,R41,R7,R77,
   C17634          100      35  33                 R34,R42,R43,R44,R45,R46,R47
   C408389          50      25  BAT54S             D11,D13,D15,D16,D9
   C28260          100      20  2.2nF 50V          C10,C11,C19,C20
   C12891          100      20  22uF 16V           C13,C14,C22,C23
   C13585          100      20  10uF 16V           C25,C27,C30,C33
   C223989          21      20  SMAJ40CA           D10,D12,D14,D8
   C864177         100      20  1k 0.1%            R57,R62,R67,R72
   C2930178        100      20  2.49k              R58,R63,R68,R73
   C856630         100      20  10k 0.1%           R59,R64,R69,R74
   C728642         100      20  15k 0.1%           R60,R65,R70,R75
   C865368         100      20  2.21k 0.1%         R61,R66,R71,R76
   C28233          100      15  100nF 100V         C16,C2,C5
   C28323          100      10  1uF 16V            C1,C26
   C1732           100      10  270pF 50V          C12,C21
   C6872041        100      10  10uF 100V          C17,C4
   C128805         100      10  10nF 100V          C18,C9
   C134976          11      10  SMAJ26CA-13-F      D6,D7
   C17313          100      10  MF-MSMF050         PF2,PF3
   C15127           50      10  AO3401A            Q2,Q4
   C8545            50      10  2N7002             Q3,Q7
   C49254250       100      10  31.6k              R11,R13
   C17513          100      10  1k                 R22,R40
   C27834          100      10  5.1k               R25,R26
   C5713386        100      10  100k 1%            R29,R3
   C17673          100      10  4.7k               R31,R32
   C72998          100      10  60.4               R55,R56
   C2886898         11      10  TL3342F160QG       SW1,SW2
   C13612           50      10  SRV05-4.TCT        U10,U11
   C127592          50      10  TLV431ASN1T1G      U2,U6
   C477928          11      10  LM5164DDAR         U3,U4
   C7519            50      10  USBLC6-2SC6        U7,U8
   C1744           100       5  4.7nF 50V          C37
   C46653          100       5  1nF 50V            C8
   C80273            6       5  SMCJ40CA           D1
   C116949          50       5  MM3Z3V6T1G         D2
   C223993           6       5  SMAJ6.0A           D3
   C2297           100       5  green              D4
   C193342          50       5  PMEG4010           D5
   C187595         100       5  0466002.NR         F1
   C1533835        100       5  742792625          FB1
   C2661452        100       5  742792022          FB2
   C165948           6       5  TYPE-C-31-M-12     J2
   C719027           6       5  DM3D-SF            J9
   C340244           6       5  ASWPA8050S330MT    L1
   C340243           6       5  ASWPA8050S220MT    L2
   C76584            6       5  ACT45B-510-2P-TL00 L3
   C719178         100       5  MF-MSMF020         PF1
   C88066            6       5  IPD068N10N3G       Q1
   C84105           50       5  MMBT3906           Q5
   C7472914         50       5  DMG2301L           Q6
   C17438          100       5  121k               R14
   C2933365        100       5  20.5k              R17
   C163405         100       5  57.6k              R19
   C2960780        100       5  44.2k              R2
   C2930435        100       5  95.3k              R20
   C2930188        100       5  27.4k 1%           R30
   C17408          100       5  100                R35
   C2933300        100       5  12.7k 1%           R4
   C17713          100       5  47k                R53
   C17514          100       5  1M                 R6
   C17828          100       5  8.2k               R78
   C2941042         50       5  LM74700QDBVRQ1     U1
   C58988            6       5  TJA1051T/3,118     U12
   C37593            6       5  ADS1115IDGSR       U13
   C2913202          6       5  ESP32-S3-WROOM-1-N U5
   C7484            50       5  SN74AHCT1G125DBVR  U9

   69 distinct parts, 4920 pieces after MOQ rounding
   LCSC enforces the true per-part minimum at checkout, so
   anything undercalled here is bumped there, not rejected.

2. Not available from LCSC/JLC -- source separately

   C3           x5   100uF 100V SMD electrolytic, 10 mm can
                Nichicon UCD2A101MNL1GS or equivalent. Land is CP_Elec_10x10.5

   C6, C7       x10  330uF 100V SMD electrolytic, 16 mm can
                Land is CP_Elec_16x22 (same pads as 16x17.5). If 330 uF only exists at 18 mm, fit 220 uF at 16 mm instead -- the bank drops to 540 uF and the ride-through to ~108 ms, which is what the board was simulated at originally

   J1           x5   JST PH 4-pin vertical header, 2.00 mm
                B4B-PH-K-S

   J10          x5   JST PH 8-pin vertical header, 2.00 mm
                B8B-PH-K-S

   J3, J4, J8   x15  0.1" pin header, 1x04 vertical
                any

   J5, J7       x10  0.1" pin header, 1x06 vertical
                any

   J6           x5   0.1" pin header, 1x03 vertical
                any

   harness      x5   JST PH crimp housings + crimps for J1 (4) and J10 (8)
                buy with the headers or the harness cannot be made up

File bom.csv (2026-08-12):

Qty (1 board) | Qty (10 boards) | References | Value | Voltage | Tolerance | Footprint | Manufacturer part number | LCSC | Notes
1 | 10 | C1 | 1uF | 50V |  | Capacitor_SMD:C_0805_2012Metric |  | C28323 | LM74700 charge-pump reservoir
4 | 40 | C10 C11 C19 C20 | 2.2nF | 50V |  | Capacitor_SMD:C_0805_2012Metric |  | C28260 | Bootstrap: datasheet mandates exactly 2.2nF X7R -- a larger value overstresses the internal VCC regulator and damages the device
2 | 20 | C12 C21 | 270pF | 50V |  | Capacitor_SMD:C_0805_2012Metric |  | C1732 | Ramp coupling capacitor CB
4 | 40 | C13 C14 C22 C23 | 22uF | 16V |  | Capacitor_SMD:C_1206_3216Metric |  | C12891
15 | 150 | C15 C24 C28 C29 C31 C32 C34 C35 C36 C38 C39 C40 C41 C42 C43 | 100nF | 16V |  | Capacitor_SMD:C_0805_2012Metric |  | C49678
3 | 30 | C16 C2 C5 | 100nF | 100V |  | Capacitor_SMD:C_0805_2012Metric |  | C28233 | LM74700 ANODE input capacitor: the datasheet requires a minimum 22nF at ANODE and this node is behind FB1 with nothing else on it
4 | 40 | C25 C27 C30 C33 | 10uF | 16V |  | Capacitor_SMD:C_1206_3216Metric |  | C13585
1 | 10 | C26 | 1uF | 16V |  | Capacitor_SMD:C_0805_2012Metric |  | C28323 | EN reset delay
1 | 10 | C3 | 100uF | 100V |  | Capacitor_SMD:CP_Elec_10x10.5 | Nichicon UCD2A101MNL1GS |  | Bulk hold-up; any 100uF >=80V SMD electrolytic on a 10x10.5 land works -- match in the JLC catalog at order. Pin 1 is +
1 | 10 | C37 | 4.7nF | 50V |  | Capacitor_SMD:C_0805_2012Metric |  | C1744 | Split-termination common-mode stabiliser
2 | 20 | C17 C4 | 10uF | 100V |  | Capacitor_SMD:C_1206_3216Metric |  | C6872041 | Switcher input bypass
2 | 20 | C6 C7 | 330uF | 100V |  | Capacitor_SMD:CP_Elec_16x22 |  |  | Power-fail ride-through. With the sensor rail shed and the LEDs off the board draws about 0.35 W here, so the bank holds the rails up long enough to finish the block in flight and close the file. 16x22 rather than 16x17.5: the two footprints are identical in every copper and courtyard layer -- only the can is 4.5 mm taller -- so the extra 220 uF costs nothing but enclosure height. Any 330uF >=80V on a 16 mm land works; match in the JLC catalogue at order. Pin 1 is +
1 | 10 | C8 | 1nF | 50V |  | Capacitor_SMD:C_0805_2012Metric |  | C46653 | Just enough to keep switching noise off the reference. Larger would delay the very detection this exists to make early
2 | 20 | C18 C9 | 10nF | 100V |  | Capacitor_SMD:C_0805_2012Metric |  | C128805 | EN sits on a bare 100k to VBAT; this keeps a high-impedance enable node quiet in a vehicle
1 | 10 | D1 | SMCJ40CA |  |  | Diode_SMD:D_SMC | Littelfuse SMCJ40CA | C80273 | 40V standoff / 64.5V clamp @ 1500W, bidirectional: absorbs ISO 7637-2 pulse 5b load dump and the negative pulses, ahead of the FET. 40V not 33V so the part stands off the declared 36V input top
1 | 10 | D2 | 3.6V 300mW |  |  | Diode_SMD:D_SOD-323 | onsemi MM3Z3V6T1G | C116949 | Rail clamp: an analog input shorted to battery back-feeds ~1.6mA through its BAT54S into +3V3; with the MCU asleep the rail would otherwise float above the ESP32's 3.6V absolute maximum
1 | 10 | D3 | SMAJ6.0A |  |  | Diode_SMD:D_SMA | Littelfuse SMAJ6.0A | C223993 | Clamps harness-injected transients on the sensor 5V. 6.0V standoff, not 5.0V: a 5.0V part on a 5.0V rail leaks up to 800uA continuously
1 | 10 | D4 | green |  |  | LED_SMD:LED_0805_2012Metric |  | C2297 | The board's only LED: +3V3 is up, so the whole supply chain came through -- battery, ideal diode, and both converters
1 | 10 | D5 | 40V 1A |  |  | Diode_SMD:D_SOD-123 | PMEG4010 | C193342 | OR-ing: bench USB can power the board, but the 5V buck (5.00V) reverse-biases it whenever the car is connected
2 | 20 | D6 D7 | SMAJ26CA |  |  | Diode_SMD:D_SMA | Diodes Inc SMAJ26CA-13-F | C134976 | Bidirectional bus clamp
4 | 40 | D10 D12 D14 D8 | SMAJ40CA |  |  | Diode_SMD:D_SMA | Littelfuse SMAJ40CA | C223989 | Ch1 harness transient clamp (bidirectional, 400W)
5 | 50 | D11 D13 D15 D16 D9 | BAT54S |  |  | Package_TO_SOT_SMD:SOT-23 | MDD BAT54S | C408389 | Ch1 rail clamp (both polarities)
1 | 10 | F1 | 2A slow |  |  | Fuse:Fuse_1206_3216Metric | Littelfuse 0466002.NR | C187595 | Sacrificial: only opens on a hard fault, not on reverse polarity
1 | 10 | FB1 | 600R |  |  | Inductor_SMD:L_1206_3216Metric | Wurth 742792625 | C1533835 | Conducted-emissions bead
1 | 10 | FB2 | 600R |  |  | Inductor_SMD:L_0805_2012Metric | Wurth 742792022 | C2661452
4 | 40 | H1 H2 H3 H4 | M3 |  |  | MountingHole:MountingHole_3.2mm_M3
1 | 10 | J1 | PWR + CAN harness |  |  | Connector_JST:JST_PH_B4B-PH-K_1x04_P2.00mm_Vertical | JST B4B-PH-K-S(LF)(SN) | C131334 | Pin 1 +12V, 2 GND, 3 CAN_H, 4 CAN_L (Autosport Labs harness order)
1 | 10 | J10 | Sensor harness |  |  | Connector_JST:JST_PH_B8B-PH-K_1x08_P2.00mm_Vertical | JST B8B-PH-K-S(LF)(SN) | C157974 | Two 5V and two ground pins so sensors can be paired up
1 | 10 | J2 | USB-C |  |  | Connector_USB:USB_C_Receptacle_HRO_TYPE-C-31-M-12 | HRO TYPE-C-31-M-12 | C165948 | Programming / CDC console only -- not a power path in the car
1 | 10 | J3 | UART0 |  |  | Connector_PinHeader_2.54mm:PinHeader_1x04_P2.54mm_Vertical
1 | 10 | J4 | I2C / Qwiic |  |  | Connector_PinHeader_2.54mm:PinHeader_1x04_P2.54mm_Vertical
1 | 10 | J5 | SPI |  |  | Connector_PinHeader_2.54mm:PinHeader_1x06_P2.54mm_Vertical |  |  | IO40 SCK / IO41 MISO / IO42 MOSI / IO47 CS -- GPIO-matrix SPI
1 | 10 | J6 | WS2812 |  |  | Connector_PinHeader_2.54mm:PinHeader_1x03_P2.54mm_Vertical |  |  | Shift-light header: +5V / 5V-logic DIN / GND
1 | 10 | J7 | Spare IO |  |  | Connector_PinHeader_2.54mm:PinHeader_1x06_P2.54mm_Vertical |  |  | IO3/IO45/IO46 are strapping pins, each with a 10k pull-down -- anything attached must not fight them at boot. Pins 4 and 5 are no longer spare: IO15 is the power-fail interrupt and IO16 is the sensor-rail enable. They stay on the header as probe points, so the ride-through can be watched on a scope without unsoldering anything, but nothing else may drive them. The ground pin is here so a probe or a ribbon has a return
1 | 10 | J8 | Rail break-out |  |  | Connector_PinHeader_2.54mm:PinHeader_1x04_P2.54mm_Vertical
1 | 10 | J9 | microSD push-pull |  |  | Connector_Card:microSD_HC_Hirose_DM3D-SF | Hirose DM3D-SF | C719027 | Push-pull socket; DET is the card-present switch
1 | 10 | JP1 | TERM (default OFF) |  |  | Jumper:SolderJumper-2_P1.3mm_Open_Pad1.0x1.5mm |  |  | Ships OPEN: unterminated. Bridge the pads only when this board is an END node on its own bus. A vehicle's bus -- OBD-II diagnostics included -- is already terminated at both ends, and a third 120 ohm across the pair takes it to about 40 ohm and can stop it working. Defaulting terminated made that an easy mistake to make
1 | 10 | JP10 | RANGE3 (default 0-5V) |  |  | Jumper:SolderJumper-3_P1.3mm_Bridged12_Pad1.0x1.5mm |  |  | Ships BRIDGED 1-2 = the 0-5V range, which is what almost every automotive sensor is. Cut 1-2 and bridge 2-3 for 0-16V; cut 1-2 and leave both open for no divider (then close BYPASS3 for a raw 0-3.3V sensor). Defaulting to 0-5V also means the firmware's DIVIDER_GAIN matches the board as shipped
1 | 10 | JP11 | PULLUP4 |  |  | Jumper:SolderJumper-2_P1.3mm_Open_Pad1.0x1.5mm |  |  | Close for 2-wire NTC / open-collector sensors
1 | 10 | JP12 | BYPASS4 |  |  | Jumper:SolderJumper-2_P1.3mm_Open_Pad1.0x1.5mm |  |  | Close for a raw 0-3.3V sensor (shorts the upper leg)
1 | 10 | JP13 | RANGE4 (default 0-5V) |  |  | Jumper:SolderJumper-3_P1.3mm_Bridged12_Pad1.0x1.5mm |  |  | Ships BRIDGED 1-2 = the 0-5V range, which is what almost every automotive sensor is. Cut 1-2 and bridge 2-3 for 0-16V; cut 1-2 and leave both open for no divider (then close BYPASS4 for a raw 0-3.3V sensor). Defaulting to 0-5V also means the firmware's DIVIDER_GAIN matches the board as shipped
1 | 10 | JP2 | PULLUP1 |  |  | Jumper:SolderJumper-2_P1.3mm_Open_Pad1.0x1.5mm |  |  | Close for 2-wire NTC / open-collector sensors
1 | 10 | JP3 | BYPASS1 |  |  | Jumper:SolderJumper-2_P1.3mm_Open_Pad1.0x1.5mm |  |  | Close for a raw 0-3.3V sensor (shorts the upper leg)
1 | 10 | JP4 | RANGE1 (default 0-5V) |  |  | Jumper:SolderJumper-3_P1.3mm_Bridged12_Pad1.0x1.5mm |  |  | Ships BRIDGED 1-2 = the 0-5V range, which is what almost every automotive sensor is. Cut 1-2 and bridge 2-3 for 0-16V; cut 1-2 and leave both open for no divider (then close BYPASS1 for a raw 0-3.3V sensor). Defaulting to 0-5V also means the firmware's DIVIDER_GAIN matches the board as shipped
1 | 10 | JP5 | PULLUP2 |  |  | Jumper:SolderJumper-2_P1.3mm_Open_Pad1.0x1.5mm |  |  | Close for 2-wire NTC / open-collector sensors
1 | 10 | JP6 | BYPASS2 |  |  | Jumper:SolderJumper-2_P1.3mm_Open_Pad1.0x1.5mm |  |  | Close for a raw 0-3.3V sensor (shorts the upper leg)
1 | 10 | JP7 | RANGE2 (default 0-5V) |  |  | Jumper:SolderJumper-3_P1.3mm_Bridged12_Pad1.0x1.5mm |  |  | Ships BRIDGED 1-2 = the 0-5V range, which is what almost every automotive sensor is. Cut 1-2 and bridge 2-3 for 0-16V; cut 1-2 and leave both open for no divider (then close BYPASS2 for a raw 0-3.3V sensor). Defaulting to 0-5V also means the firmware's DIVIDER_GAIN matches the board as shipped
1 | 10 | JP8 | PULLUP3 |  |  | Jumper:SolderJumper-2_P1.3mm_Open_Pad1.0x1.5mm |  |  | Close for 2-wire NTC / open-collector sensors
1 | 10 | JP9 | BYPASS3 |  |  | Jumper:SolderJumper-2_P1.3mm_Open_Pad1.0x1.5mm |  |  | Close for a raw 0-3.3V sensor (shorts the upper leg)
1 | 10 | L1 | 33uH |  |  | Inductor_SMD:L_Sunlord_SWPA8040S | Sunlord ASWPA8050S330MT | C340244 | Shielded molded, Isat 3A vs the 1.75A max peak limit
1 | 10 | L2 | 22uH |  |  | Inductor_SMD:L_Sunlord_SWPA8040S | Sunlord ASWPA8050S220MT | C340243 | Same automotive series as L1. C340243 verified against the live JLC catalogue 2026-08-12: 22uH, 3A Isat, 8x8mm -- one part number below L1's C340244, which is the 33uH of the same series
1 | 10 | L3 | 51uH |  |  | esp32autosport:L_CommonMode_TDK_ACT45B | TDK ACT45B-510-2P-TL003 | C76584 | AEC-Q200 CAN choke; footprint pads renumbered so symbol winding 1-2 is the package's top (1-4) winding
1 | 10 | PF1 | 0.2A PTC |  |  | Resistor_SMD:R_1206_3216Metric | Bourns MF-MSMF020 | C719178 | Resettable: a shorted sensor wire trips this, not the board. Now behind the load switch, so a short is also something firmware can clear by dropping SENS_EN, rather than waiting for the fuse to cool
2 | 20 | PF2 PF3 | 0.5A hold |  |  | Resistor_SMD:R_1206_3216Metric | Bourns MF-MSMF050 | C17313
1 | 10 | Q1 | IPD068N10 |  |  | Package_TO_SOT_SMD:TO-252-3_TabPin2 | Infineon IPD068N10N3G | C88066 | Source to battery, drain to load: body diode blocks reverse polarity. The previously specified PSMN4R3-100BSE does not exist
2 | 20 | Q2 Q4 | AO3401A |  |  | Package_TO_SOT_SMD:SOT-23 | Alpha & Omega AO3401A | C15127 | Sensor-rail load switch. Source to +5V, so the body diode points into the rail and the switch blocks with the gate high
1 | 10 | Q3 | 2N7002 |  |  | Package_TO_SOT_SMD:SOT-23 | onsemi 2N7002 | C8545 | Level shifter: the P-FET's gate has to be pulled to GND from 5V, and a 3.3V GPIO cannot do that directly
1 | 10 | Q5 | MMBT3906 |  |  | Package_TO_SOT_SMD:SOT-23 | ST(Semtech) MMBT3906 | C84105 | Pulls the P-FET gate to its source on overvoltage. NOTE: this was C8544 until 2026-08-12, which is an S9018 -- an NPN, and not this part at all. Ordering it would have assembled the wrong polarity into the USB over-voltage cutoff and left the protection inoperative. Verified against the live catalogue: C84105 is an ST(Semtech) MMBT3906, PNP, SOT-23, 40 V
1 | 10 | Q6 | DMG2301L |  |  | Package_TO_SOT_SMD:SOT-23 | DMG2301L | C7472914 | High-side switch so firmware can power-cycle a wedged card
1 | 10 | Q7 | 2N7002 |  |  | Package_TO_SOT_SMD:SOT-23 | 2N7002 | C8545 | Level shift for the P-ch gate. Prefer an AEC-Q101 equivalent: the standard 2N7002 is not automotive qualified
13 | 130 | R1 R10 R12 R15 R16 R18 R21 R27 R39 R41 R7 R77 R9 | 100k |  |  | Resistor_SMD:R_0805_2012Metric |  | C149504 | UVLO upper leg
2 | 20 | R11 R13 | 31.6k |  |  | Resistor_SMD:R_0805_2012Metric |  | C49254250 | RON = 5.0V x 2500 / 400kHz (Eq 12) -> 396kHz; tON = 237ns at the 53.3V clamp, comfortably above the 50ns minimum
1 | 10 | R14 | 121k |  |  | Resistor_SMD:R_0805_2012Metric |  | C17438 | Ripple-injection ramp resistor RA
1 | 10 | R17 | 20.5k |  |  | Resistor_SMD:R_0805_2012Metric |  | C2933365 | RON = 3.3V x 2500 / 400kHz (Eq 12) -> 402kHz; tON = 154ns at the 53.3V clamp, above the 50ns minimum
1 | 10 | R19 | 57.6k |  |  | Resistor_SMD:R_0805_2012Metric |  | C163405 | FB lower
1 | 10 | R2 | 44.2k |  |  | Resistor_SMD:R_0805_2012Metric |  | C2960780 | UVLO lower leg. Ratio 0.3065 against V_EN_IH 1.06/2.0/2.6V gives release at 3.5/6.5/8.5V. The earlier 25.5k assumed a 1.2V threshold and would not have started until 9.8V typical, 12.8V worst case
1 | 10 | R20 | 95.3k |  |  | Resistor_SMD:R_0805_2012Metric |  | C2930435 | Ripple-injection ramp resistor RA
2 | 20 | R22 R40 | 1k |  |  | Resistor_SMD:R_0805_2012Metric |  | C17513
2 | 20 | R25 R26 | 5.1k |  |  | Resistor_SMD:R_0805_2012Metric |  | C27834
2 | 20 | R29 R3 | 100k |  | 1% | Resistor_SMD:R_0805_2012Metric |  | C5713386 | Power-fail divider, upper leg
1 | 10 | R30 | 27.4k |  | 1% | Resistor_SMD:R_0805_2012Metric |  | C2930188 | Trip at 1.24V x 127.4/27.4 = 5.77V: above a compliant source's 5.25V ceiling, below the TJA1051's 6V absolute maximum
2 | 20 | R31 R32 | 4.7k |  |  | Resistor_SMD:R_0805_2012Metric |  | C17673
7 | 70 | R34 R42 R43 R44 R45 R46 R47 | 33 |  |  | Resistor_SMD:R_0805_2012Metric |  | C17634 | Edge-rate limit into the level shifter
1 | 10 | R35 | 100 |  |  | Resistor_SMD:R_0805_2012Metric |  | C17408 | Series termination into the strip. The buffer drove the connector directly, and a WS2812 strip is metres of unterminated lead
1 | 10 | R4 | 12.7k |  | 1% | Resistor_SMD:R_0805_2012Metric |  | C2933300 | Lower leg: trips at 1.24V * 112.7/12.7 = 11.00V on the harness, below anything a healthy battery does and far above the converters' dropout, so there is a whole ride-through between detect and death
15 | 150 | R23 R24 R28 R33 R36 R37 R38 R48 R49 R5 R50 R51 R52 R54 R8 | 10k |  |  | Resistor_SMD:R_0805_2012Metric |  | C17414 | Cathode pull-up. 10k gives the part 330uA, over the TLV431's 100uA minimum cathode current. A 2.5V TL431 would need 1mA and so a 2.2k here, and the divider below would have to change with it
1 | 10 | R53 | 47k |  |  | Resistor_SMD:R_0805_2012Metric |  | C17713 | Card-detect pull-up
2 | 20 | R55 R56 | 60.4 |  |  | Resistor_SMD:R_0805_2012Metric |  | C72998 | Split termination upper half
4 | 40 | R57 R62 R67 R72 | 1k |  | 0.1% | Resistor_SMD:R_0805_2012Metric |  | C864177 | Ch1 series/fault-current limit; 0.1% thin film -- it is inside the divider chain, so its tolerance is a gain error
4 | 40 | R58 R63 R68 R73 | 2.49k |  |  | Resistor_SMD:R_0805_2012Metric |  | C2930178 | Ch1 bias resistor
4 | 40 | R59 R64 R69 R74 | 10k |  | 0.1% | Resistor_SMD:R_0805_2012Metric |  | C856630 | Ch1 divider upper leg, 0.1% thin film for AFR-grade accuracy
1 | 10 | R6 | 1M |  |  | Resistor_SMD:R_0805_2012Metric |  | C17514 | Hysteresis, about 0.3V at the harness. Without it a battery sagging across the threshold on crank would chatter the interrupt
4 | 40 | R60 R65 R70 R75 | 15k |  | 0.1% | Resistor_SMD:R_0805_2012Metric |  | C728642 | 0-5V range: 5.0V in -> ~2.88V at the ADC (1k series included); exact scale is a firmware calibration constant
4 | 40 | R61 R66 R71 R76 | 2.21k |  | 0.1% | Resistor_SMD:R_0805_2012Metric |  | C865368 | 0-16V range: 16.0V in -> ~2.67V at the ADC (1k series included)
1 | 10 | R78 | 8.2k |  |  | Resistor_SMD:R_0805_2012Metric |  | C17828 | Divide by 13.2, not 11: at 36V the 11:1 divider put 3.27V on the pin, above the ADC's usable 3.1V, so the reading saturated near the top of the declared input window
1 | 10 | SW1 | RESET |  |  | Button_Switch_SMD:SW_SPST_TL3342 | TL3342F160QG | C2886898 | Genuine E-Switch is scarce at LCSC; any 5.2mm gull-wing tact fits
1 | 10 | SW2 | BOOT |  |  | Button_Switch_SMD:SW_SPST_TL3342 | TL3342F160QG | C2886898
1 | 10 | U1 | LM74700-Q1 |  |  | Package_TO_SOT_SMD:SOT-23-6 | LM74700QDBVRQ1 | C2941042 | Ideal-diode controller; blocks reverse battery via Q1
2 | 20 | U10 U11 | SRV05-4 |  |  | Package_TO_SOT_SMD:SOT-23-6 | Semtech SRV05-4.TCT | C13612 | Card-slot ESD clamp, CLK/CMD/D0/D1
1 | 10 | U12 | TJA1051T/3 |  |  | Package_SO:SOIC-8_3.9x4.9mm_P1.27mm | TJA1051T/3,118 | C58988 | 5V bus drive with a 3.3V VIO pin, so no level shifting to the ESP32
1 | 10 | U13 | ADS1115 |  |  | Package_SO:VSSOP-10_3x3mm_P0.5mm | ADS1115IDGSR | C37593 | 16-bit 4-ch I2C ADC for AFR-grade accuracy; ADDR to GND = 0x48
2 | 20 | U2 U6 | TLV431A |  |  | Package_TO_SOT_SMD:SOT-23 | TLV431ASN1T1G | C127592 | Power-fail comparator. Below the trip point it stops conducting and R_pu takes PWR_FAIL high, so the interrupt is a rising edge and an absent or dead part reads as 'failing' rather than as 'fine'. PINOUT: this uses KiCad's TL431DBZ numbering (1 K, 2 REF, 3 A) on a plain SOT-23. Shunt references are NOT consistent between vendors in this package -- CONFIRM against the datasheet for the exact part ordered. If REF and A are swapped the part simply never conducts and PWR_FAIL sits permanently asserted: loud, harmless, and obvious on the bench, but it will not be caught by ERC or DRC
1 | 10 | U3 | LM5164 (5V) |  |  | Package_SO:SOIC-8-1EP_3.9x4.9mm_P1.27mm_EP2.95x4.9mm_Mask2.71x3.4mm_ThermalVias | LM5164DDAR | C477928 | 100V synchronous buck, ultra-low Iq. Non-automotive variant; the Q1 is scarce
1 | 10 | U4 | LM5164 (3V3) |  |  | Package_SO:SOIC-8-1EP_3.9x4.9mm_P1.27mm_EP2.95x4.9mm_Mask2.71x3.4mm_ThermalVias | LM5164DDAR | C477928 | Second buck straight off the battery: a shorted 5V sensor harness cannot brown out the MCU
1 | 10 | U5 | ESP32-S3-WROOM-1-N16R8 |  |  | RF_Module:ESP32-S3-WROOM-1 | ESP32-S3-WROOM-1-N16R8 | C2913202 | 16MB flash / 8MB octal PSRAM. Pins 28-30 (IO35/36/37) are consumed by the octal PSRAM and must stay unconnected. IO3/IO45/IO46 on the spare header are strapping pins -- leave floating at boot.
2 | 20 | U7 U8 | USBLC6-2SC6 |  |  | Package_TO_SOT_SMD:SOT-23-6 | USBLC6-2SC6 | C7519 | USB ESD clamp, behind the OVP switch so its own 5.5 V VBUS-pin limit is honoured too
1 | 10 | U9 | 74AHCT1G125 |  |  | Package_TO_SOT_SMD:SOT-23-5 | SN74AHCT1G125DBVR | C7484 | 5 V buffer so WS2812 DIN is a real 5 V rail, not 3.3 V hoping

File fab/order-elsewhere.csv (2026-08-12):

Designators | Qty per board | Order Qty | What | Note
C3 | 1 | 5 | 100uF 100V SMD electrolytic, 10 mm can | Nichicon UCD2A101MNL1GS or equivalent. Land is CP_Elec_10x10.5
C6, C7 | 2 | 10 | 330uF 100V SMD electrolytic, 16 mm can | Land is CP_Elec_16x22 (same pads as 16x17.5). If 330 uF only exists at 18 mm, fit 220 uF at 16 mm instead -- the bank drops to 540 uF and the ride-through to ~108 ms, which is what the board was simulated at originally
J1 | 1 | 5 | JST PH 4-pin vertical header, 2.00 mm | B4B-PH-K-S
J10 | 1 | 5 | JST PH 8-pin vertical header, 2.00 mm | B8B-PH-K-S
J3, J4, J8 | 3 | 15 | 0.1" pin header, 1x04 vertical | any
J5, J7 | 2 | 10 | 0.1" pin header, 1x06 vertical | any
J6 | 1 | 5 | 0.1" pin header, 1x03 vertical | any
harness | 1 | 5 | JST PH crimp housings + crimps for J1 (4) and J10 (8) | buy with the headers or the harness cannot be made up

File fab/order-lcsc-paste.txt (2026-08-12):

C49678,100
C17414,100
C149504,100
C17634,100
C408389,50
C28260,100
C12891,100
C13585,100
C223989,21
C864177,100
C2930178,100
C856630,100
C728642,100
C865368,100
C28233,100
C28323,100
C1732,100
C6872041,100
C128805,100
C134976,11
C17313,100
C15127,50
C8545,50
C49254250,100
C17513,100
C27834,100
C5713386,100
C17673,100
C72998,100
C2886898,11
C13612,50
C127592,50
C477928,11
C7519,50
C1744,100
C46653,100
C80273,6
C116949,50
C223993,6
C2297,100
C193342,50
C187595,100
C1533835,100
C2661452,100
C165948,6
C719027,6
C340244,6
C340243,6
C76584,6
C719178,100
C88066,6
C84105,50
C7472914,50
C17438,100
C2933365,100
C163405,100
C2960780,100
C2930435,100
C2930188,100
C17408,100
C2933300,100
C17713,100
C17514,100
C17828,100
C2941042,50
C58988,6
C37593,6
C2913202,6
C7484,50

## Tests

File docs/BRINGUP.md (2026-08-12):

# First-power bring-up checklist

Work through this in order on the first board back from assembly. Every
step has an expected value; stop at the first one that misses and debug
there — later stages assume the earlier ones.

**Bench setup:** current-limited supply, leads to J1 pin 1 (+) and pin 2
(GND). No card, no sensors, nothing on USB yet.

## Stage 0 — before power

- [ ] Visual against `plots/board-iso.png`: connector orientations, the two
      220 µF cans, no tombstones on the SOT-23s.
- [ ] Meter, diode mode, across every rail TP to GND (TP7): none reads a
      dead short. `+VBAT` (TP3) shows the bucks' input caps charging; `+5V`
      (TP4) and `+3V3` (TP5) each read a diode-ish ~0.4–0.6 V from the
      converters' body diodes — 0.000 V here means a solder bridge.

## Stage 1 — front end only (current limit 100 mA, 13.5 V)

- [ ] Input current after inrush: **≤ 60 mA** (module idle + LED).
- [ ] TP3 `+VBAT` = supply minus ~10 mV (the ideal diode is enhancing;
      0.4–0.7 V low means the LM74700 isn't driving Q1 — check R1/R2).
- [ ] TP4 `+5V` = **5.00 ± 0.15 V**, TP5 `+3V3` = **3.28 ± 0.10 V**
      (tolerance windows from the Monte Carlo, study 8).
- [ ] TP1 `PG_5V`, TP2 `PG_3V3` both high (~3.3 V).
- [ ] Green LED on.
- [ ] TP6 `+5VS` = **0 V** — the sensor rail is off until firmware asserts
      SENS_EN. If it reads 5 V, Q2/Q3 are misplaced or R7 is missing.
- [ ] J7 pin 4 `PWR_FAIL` = **low** at 13.5 V in. Lower the supply: it must
      snap high at **11.0 ± 0.3 V** and snap back low ~0.3 V higher.
- [ ] Nothing warm to the touch after 5 minutes.

## Stage 2 — reverse and ride-through (still no firmware)

- [ ] Swap the supply leads (current limit still 100 mA): input current
      **0 mA**, nothing heats. Swap back.
- [ ] Scope TP3 and kill the supply: `+VBAT` should coast down over tens of
      ms (the 540 µF bank), not collapse instantly.

## Stage 3 — USB (no J1 power)

- [ ] Plug a known 5 V USB source: board boots (LED on), TP4 ≈ 4.5 V
      (through the OR-ing diode — this is normal on USB power).
- [ ] The port enumerates as the ESP32-S3 CDC device.
- [ ] If you have a 9 V-capable brick and a sacrificial attitude: the OVP
      should simply disconnect (board dead, no damage, recovers on a 5 V
      source). Simulated trip 5.95 V.

## Stage 4 — firmware smoke test (J1 power)

- [ ] Flash over USB. Boot straps verified by design (audit_straps), so a
      failure to enter download mode means the BOOT button, not the straps.
- [ ] Firmware asserts `SENS_EN` (IO16): TP6 `+5VS` rises to ~4.9 V.
- [ ] Insert a card, fire `SD_PWR_EN`: card mounts. If not, scope the
      **SD_CLK / SD_CMD test points** by the socket — CMD0 out and a
      response back tells you card vs. bus in one look.
- [ ] CAN: with a second node and 120 Ω at the far end, send a frame.
      TP10/TP11 (CAN_H/CAN_L) show ~2.5 V recessive, splitting to
      ~3.5/1.5 V dominant. (TP8/TP9 are SD_CLK/SD_CMD, not the bus.)
- [ ] Power-cut drill: with a file open and logging, kill J1. The file
      must be intact on the card. `PWR_FAIL` on J7.4 shows the warning
      edge on a scope; the bank buys ~100 ms (study 4).

## Stage 5 — analog channels

- [ ] Jumpers as shipped = all open = 0–3.3 V range floating: readings
      near zero, not railed.
- [ ] Feed 2.500 V into AIN1: internal ADC and ADS1115 agree within 2 %.
      Set RANGE A (0–5 V): 5.000 V in reads 2.86 V at the pin (divider
      confirmed to three digits in study 2).
- [ ] Feed −5 V (reversed sensor): channel reads ~0, board unbothered.

Everything in this list traces to a study in `gen/simulate.py` or an audit
in `gen/`; if a measurement misses its window, the matching study says
what the value is made of.

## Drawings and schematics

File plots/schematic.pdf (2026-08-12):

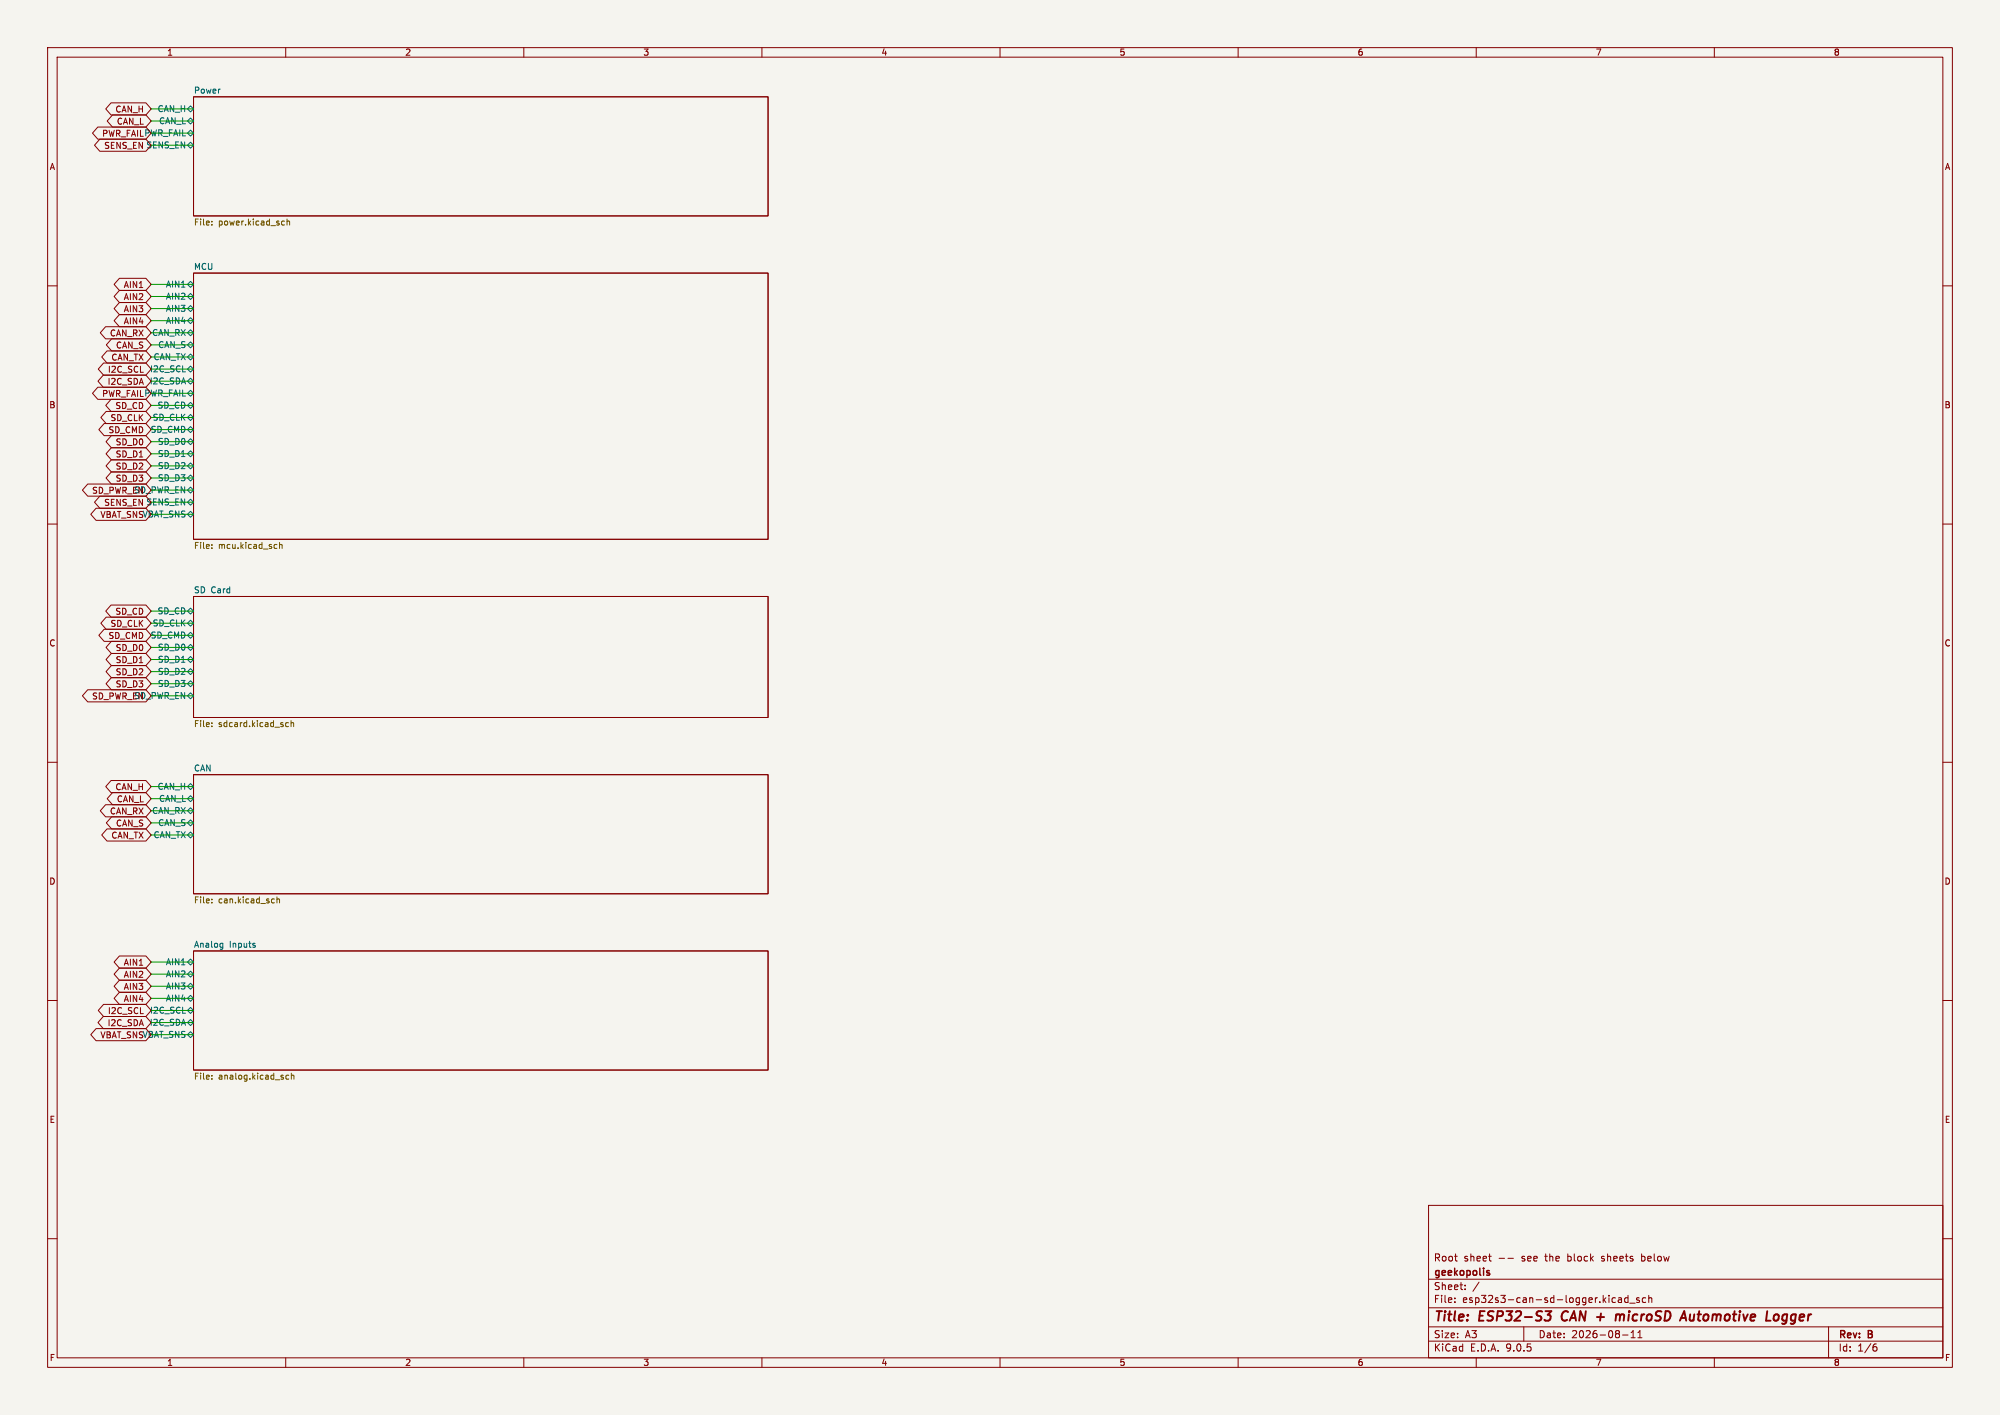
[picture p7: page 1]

Analog Inputs File: analog.kicad_sch

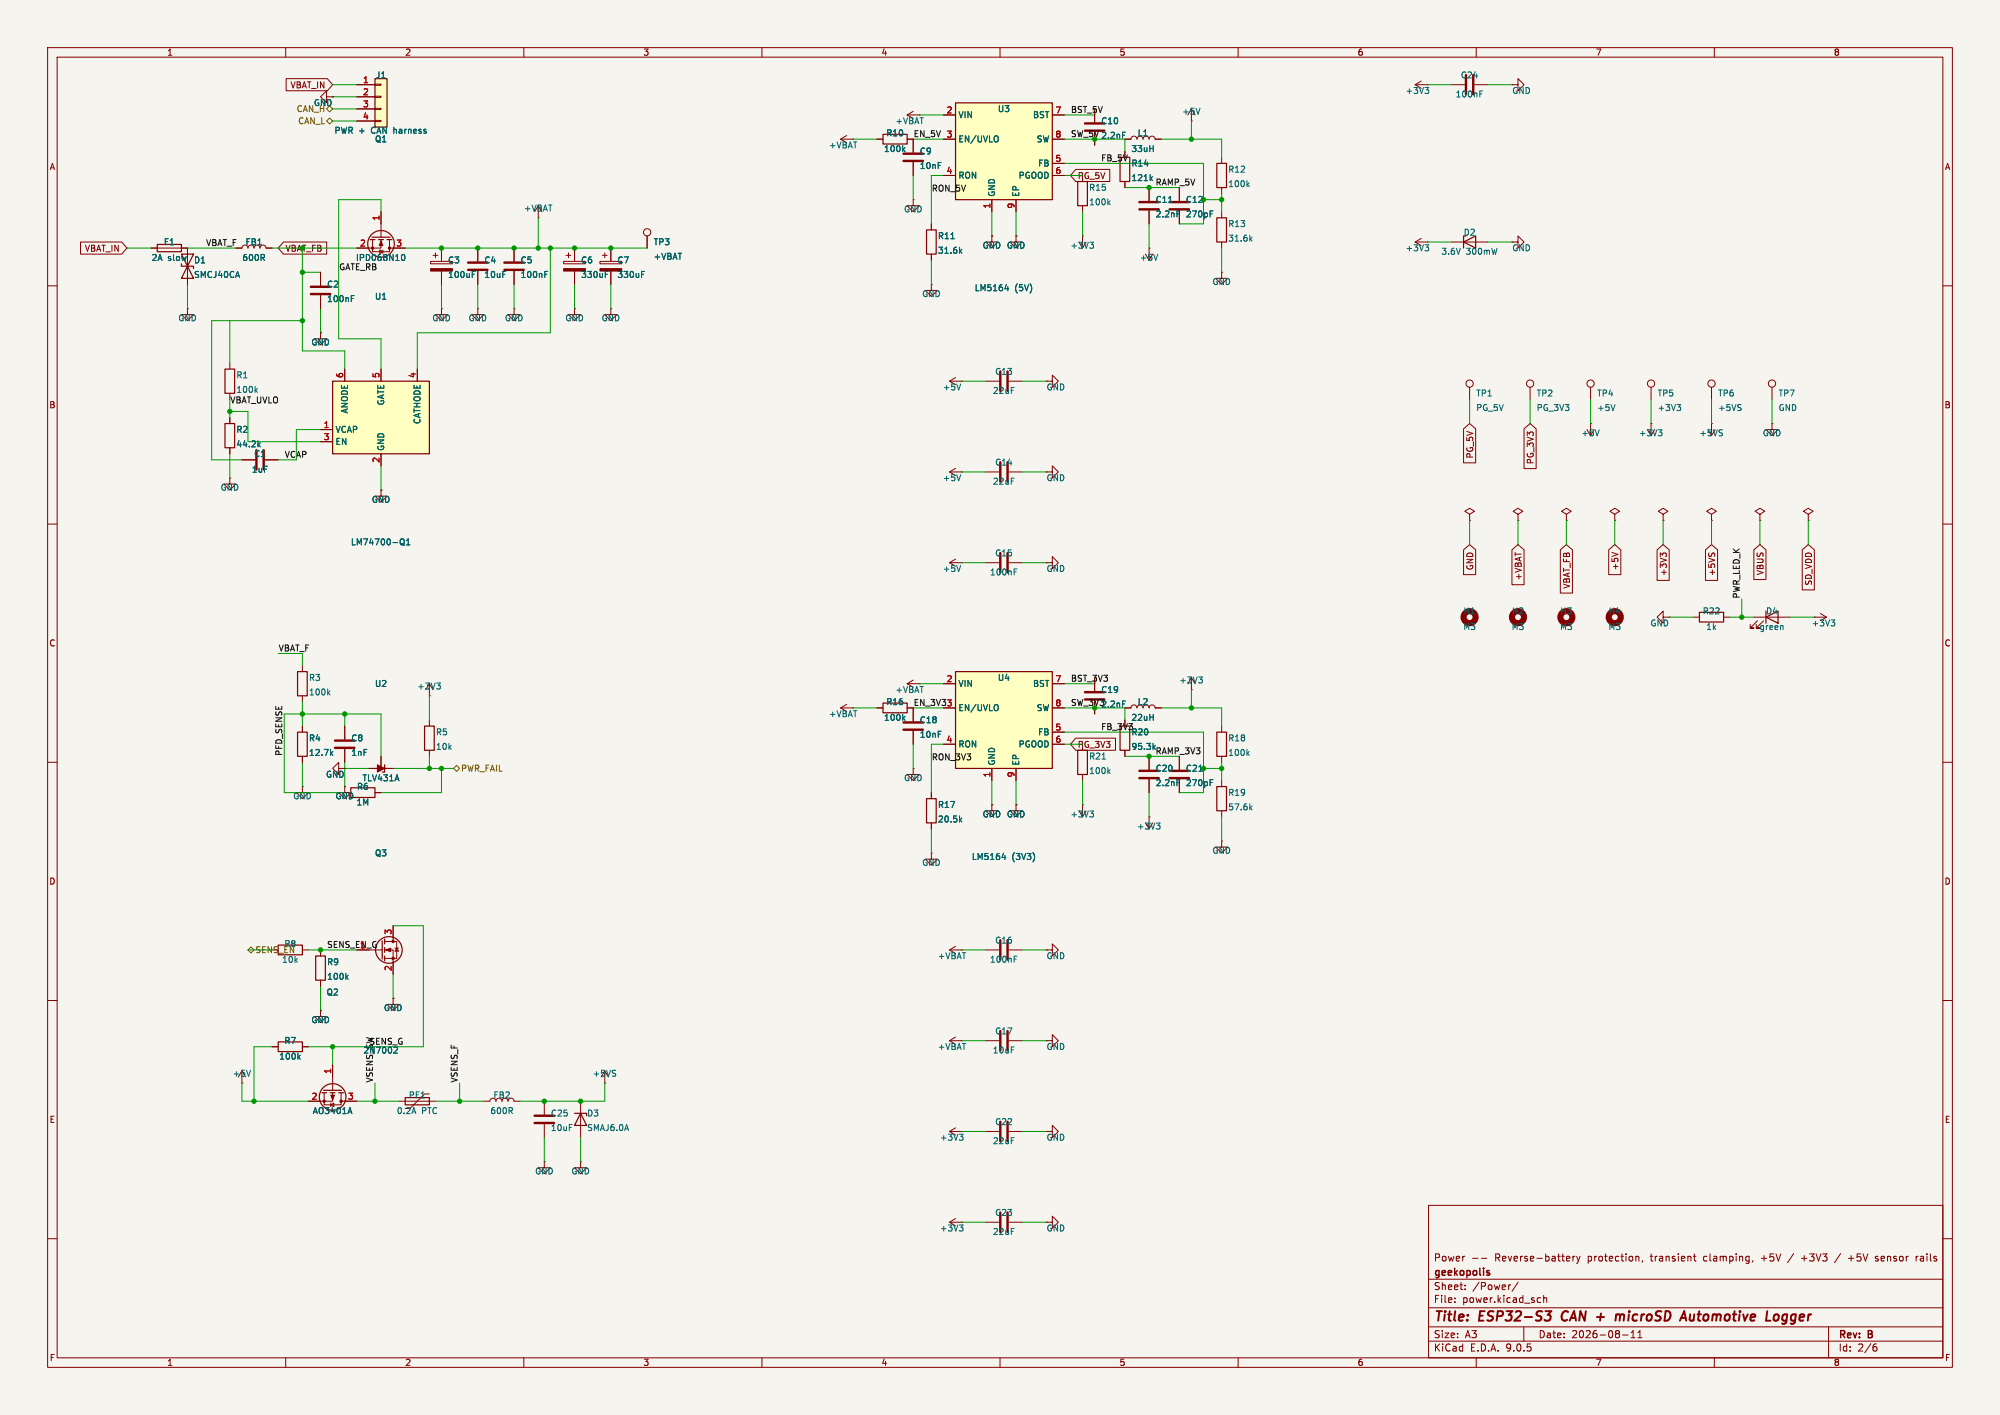
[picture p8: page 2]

9 BST 7 SW 8 FB 5 PGOOD 6 GND GND

9 BST 7 SW 8 FB 5 PGOOD 6 U3

9 BST 7 SW 8 FB 5 PGOOD 6 GND

9 BST 7 SW 8 FB 5 PGOOD 6 U4

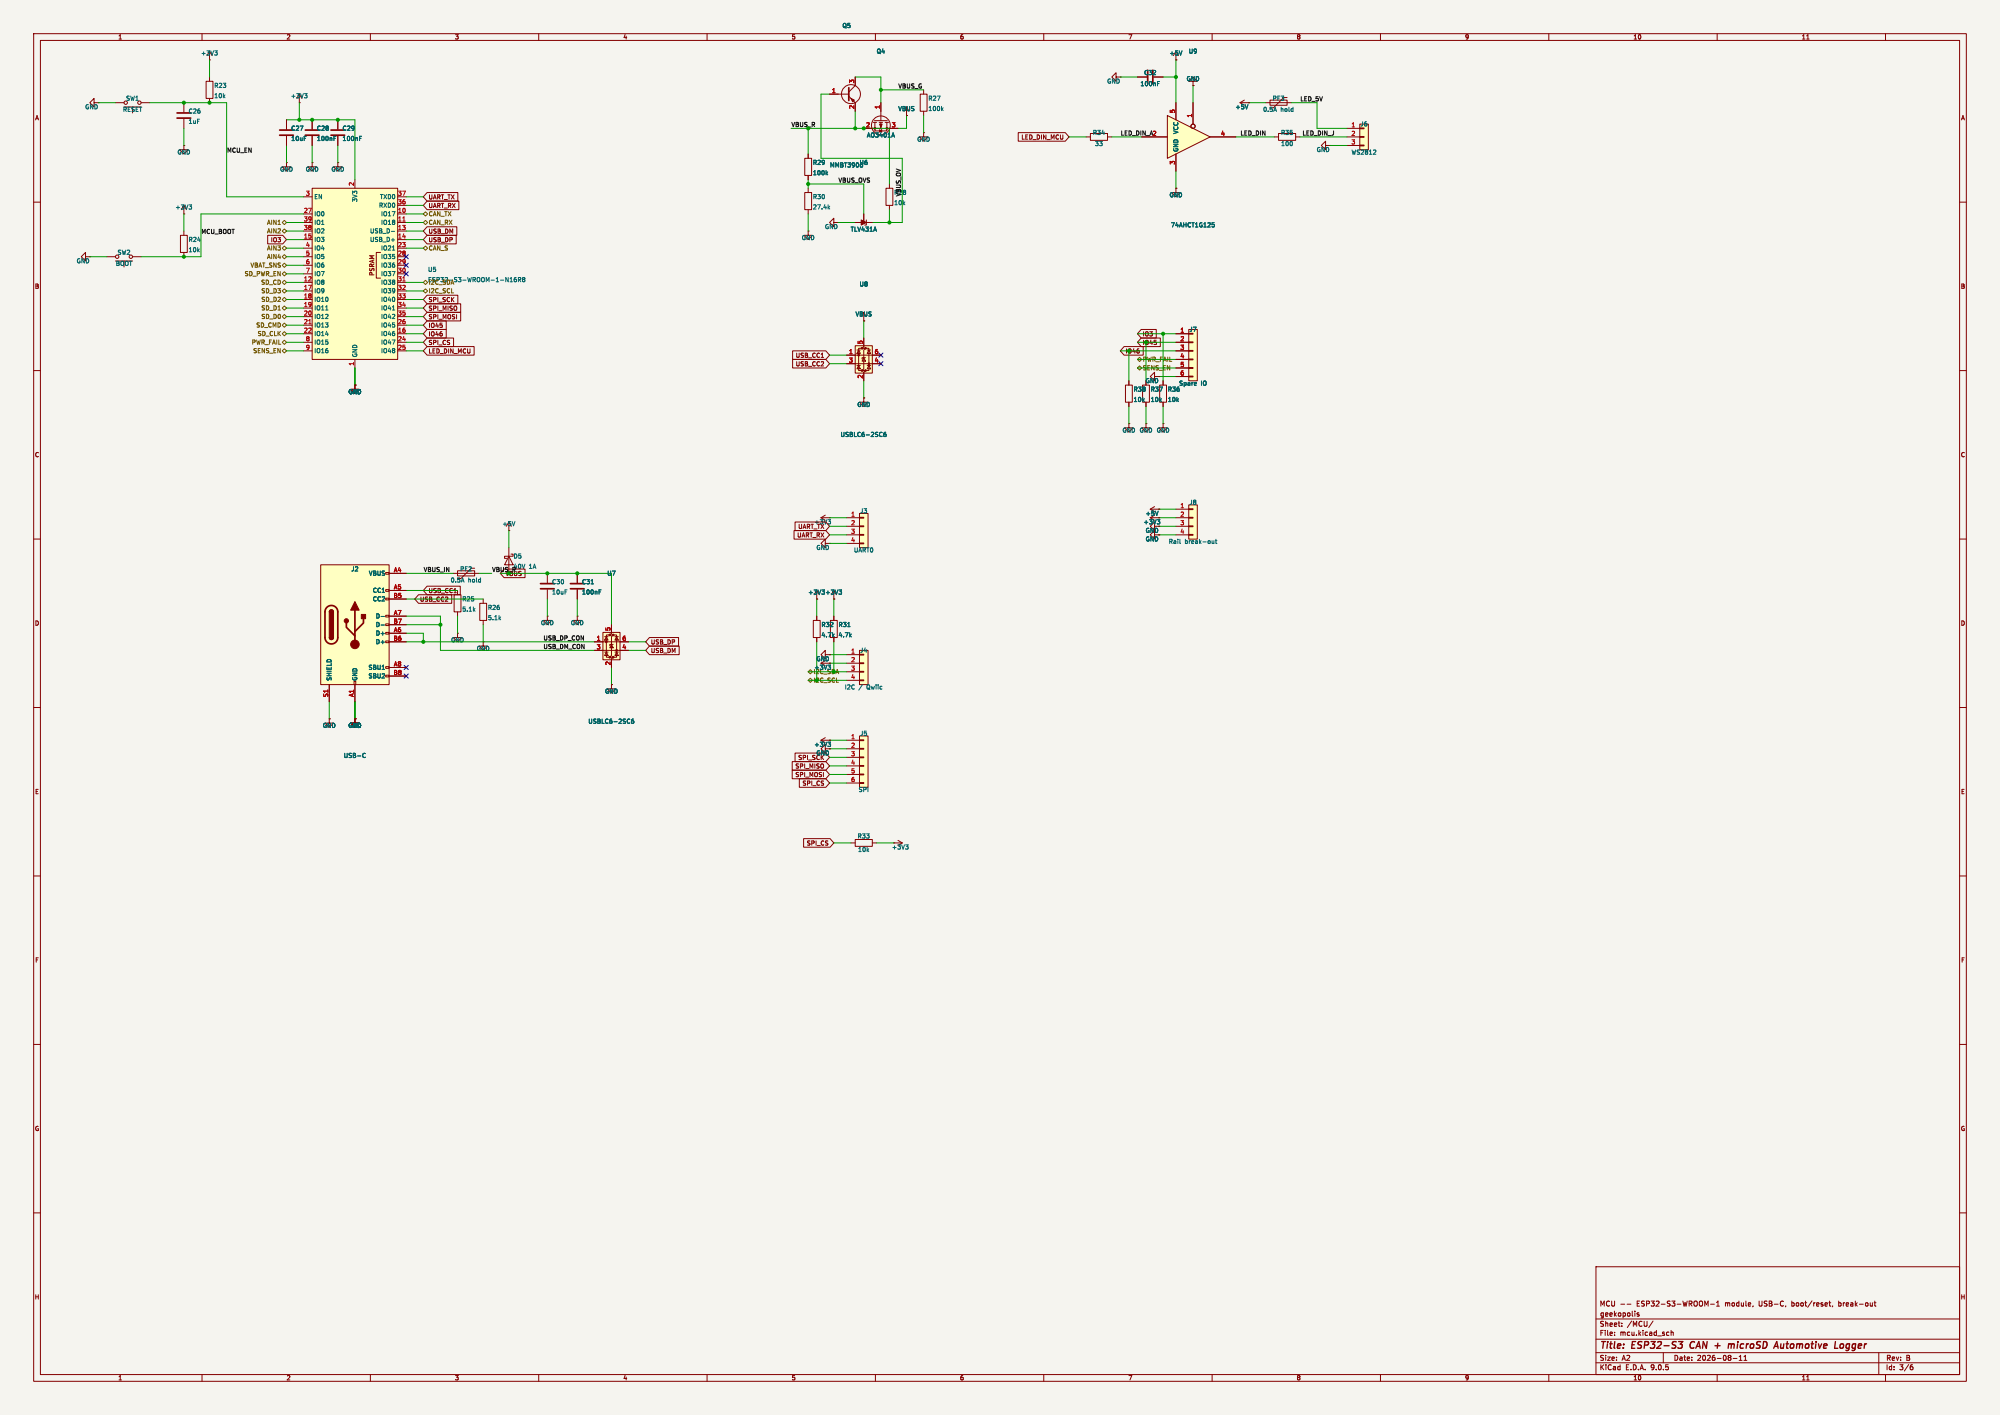
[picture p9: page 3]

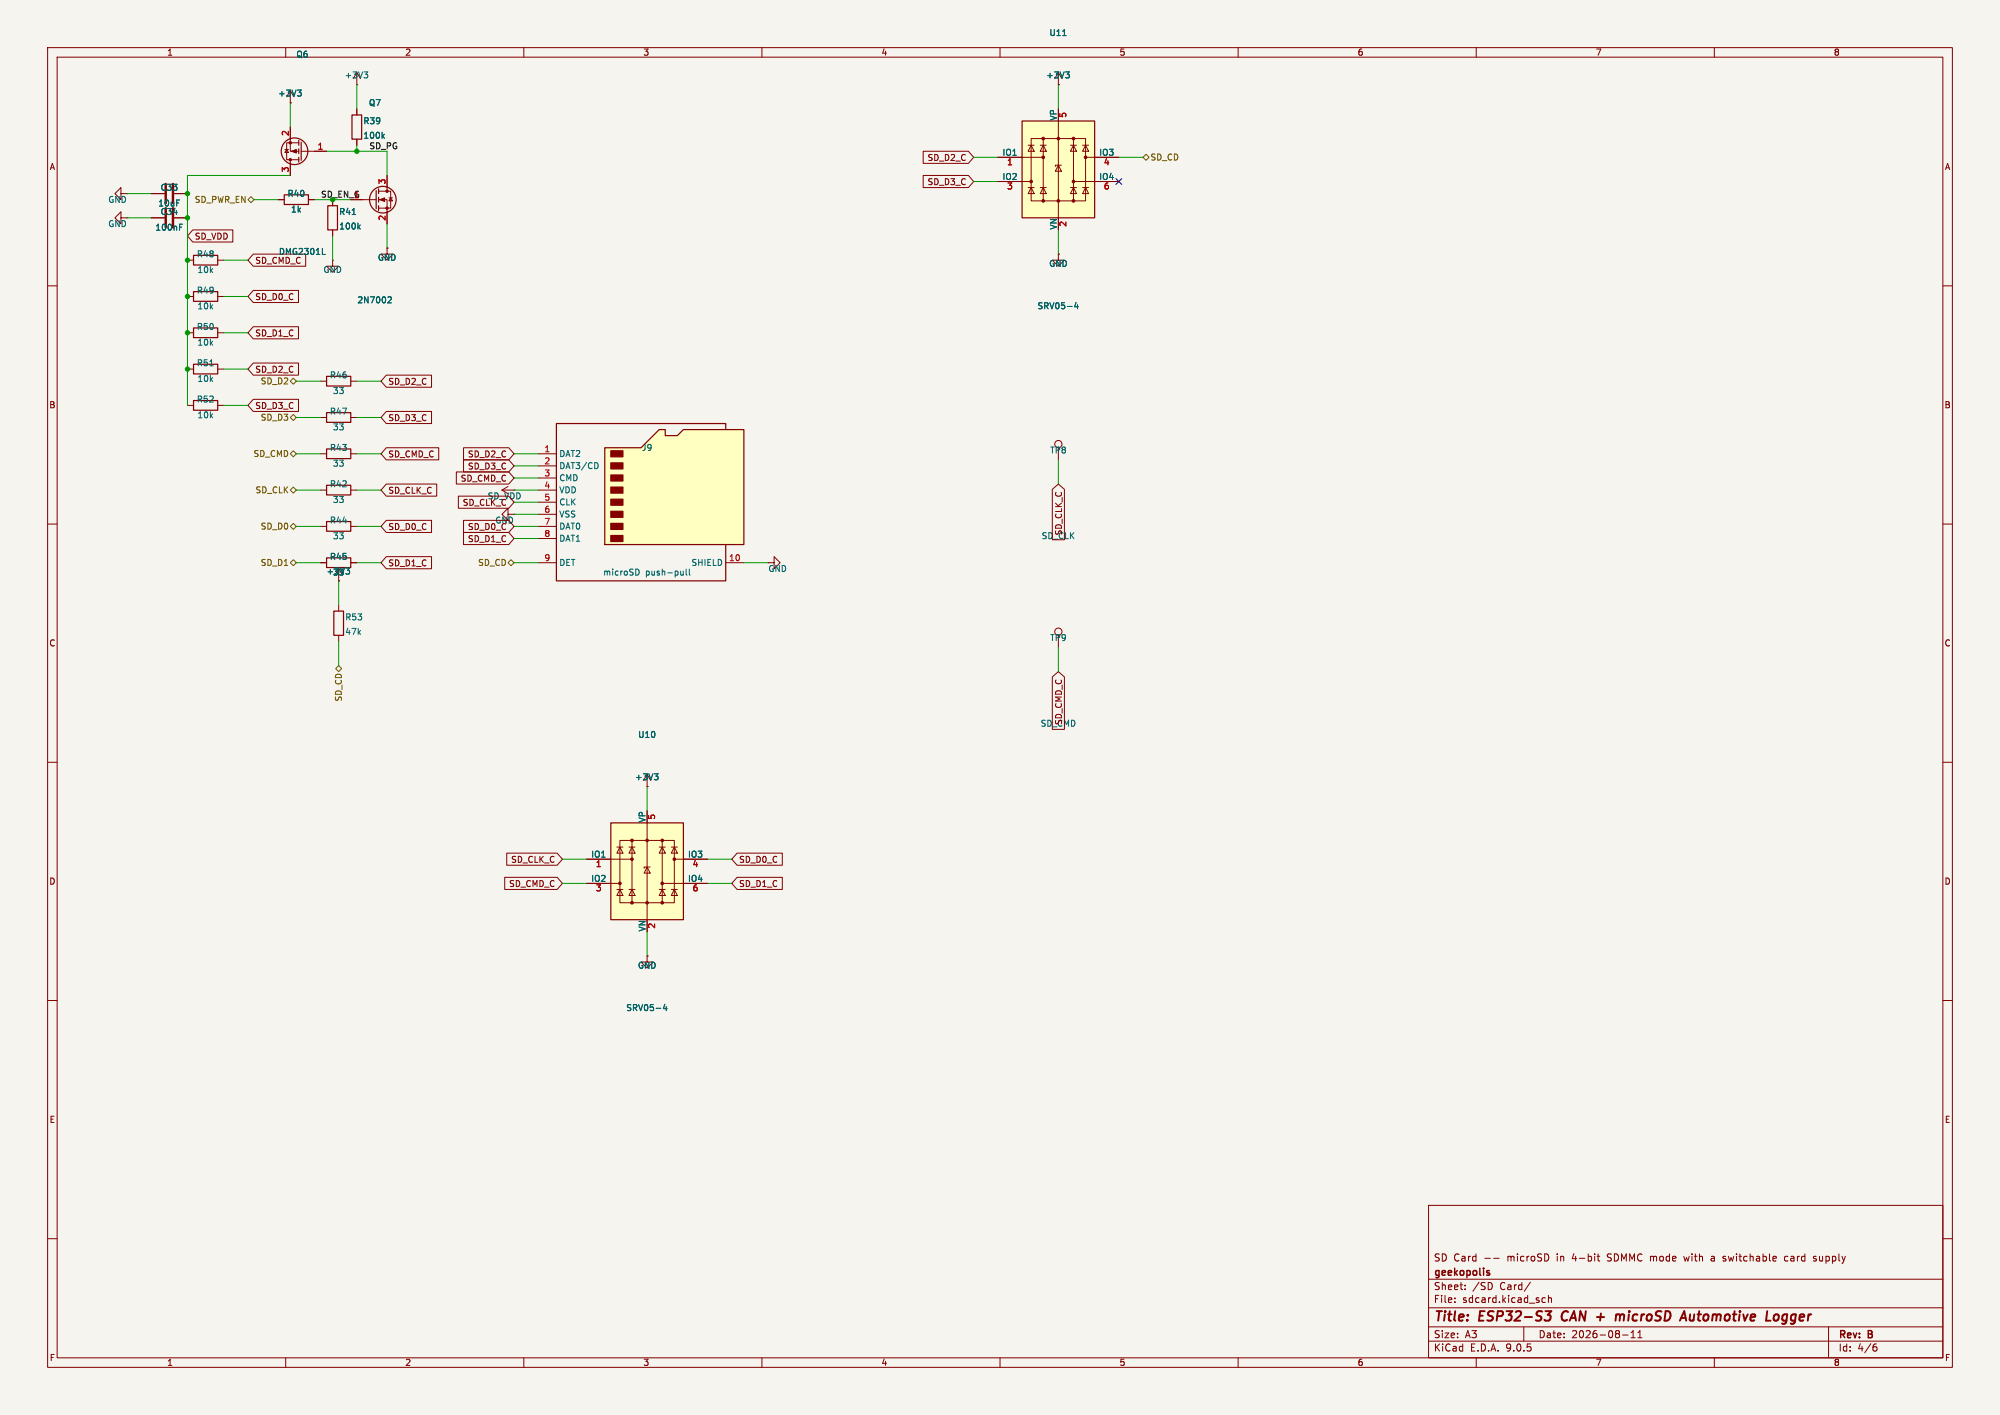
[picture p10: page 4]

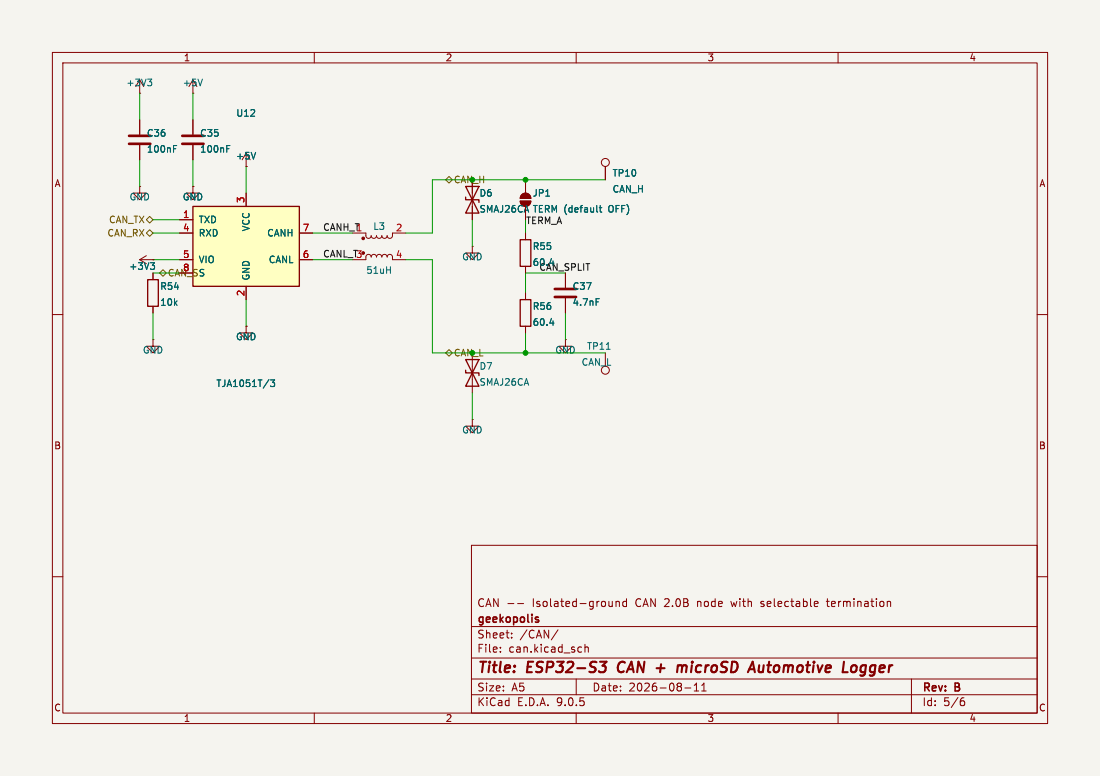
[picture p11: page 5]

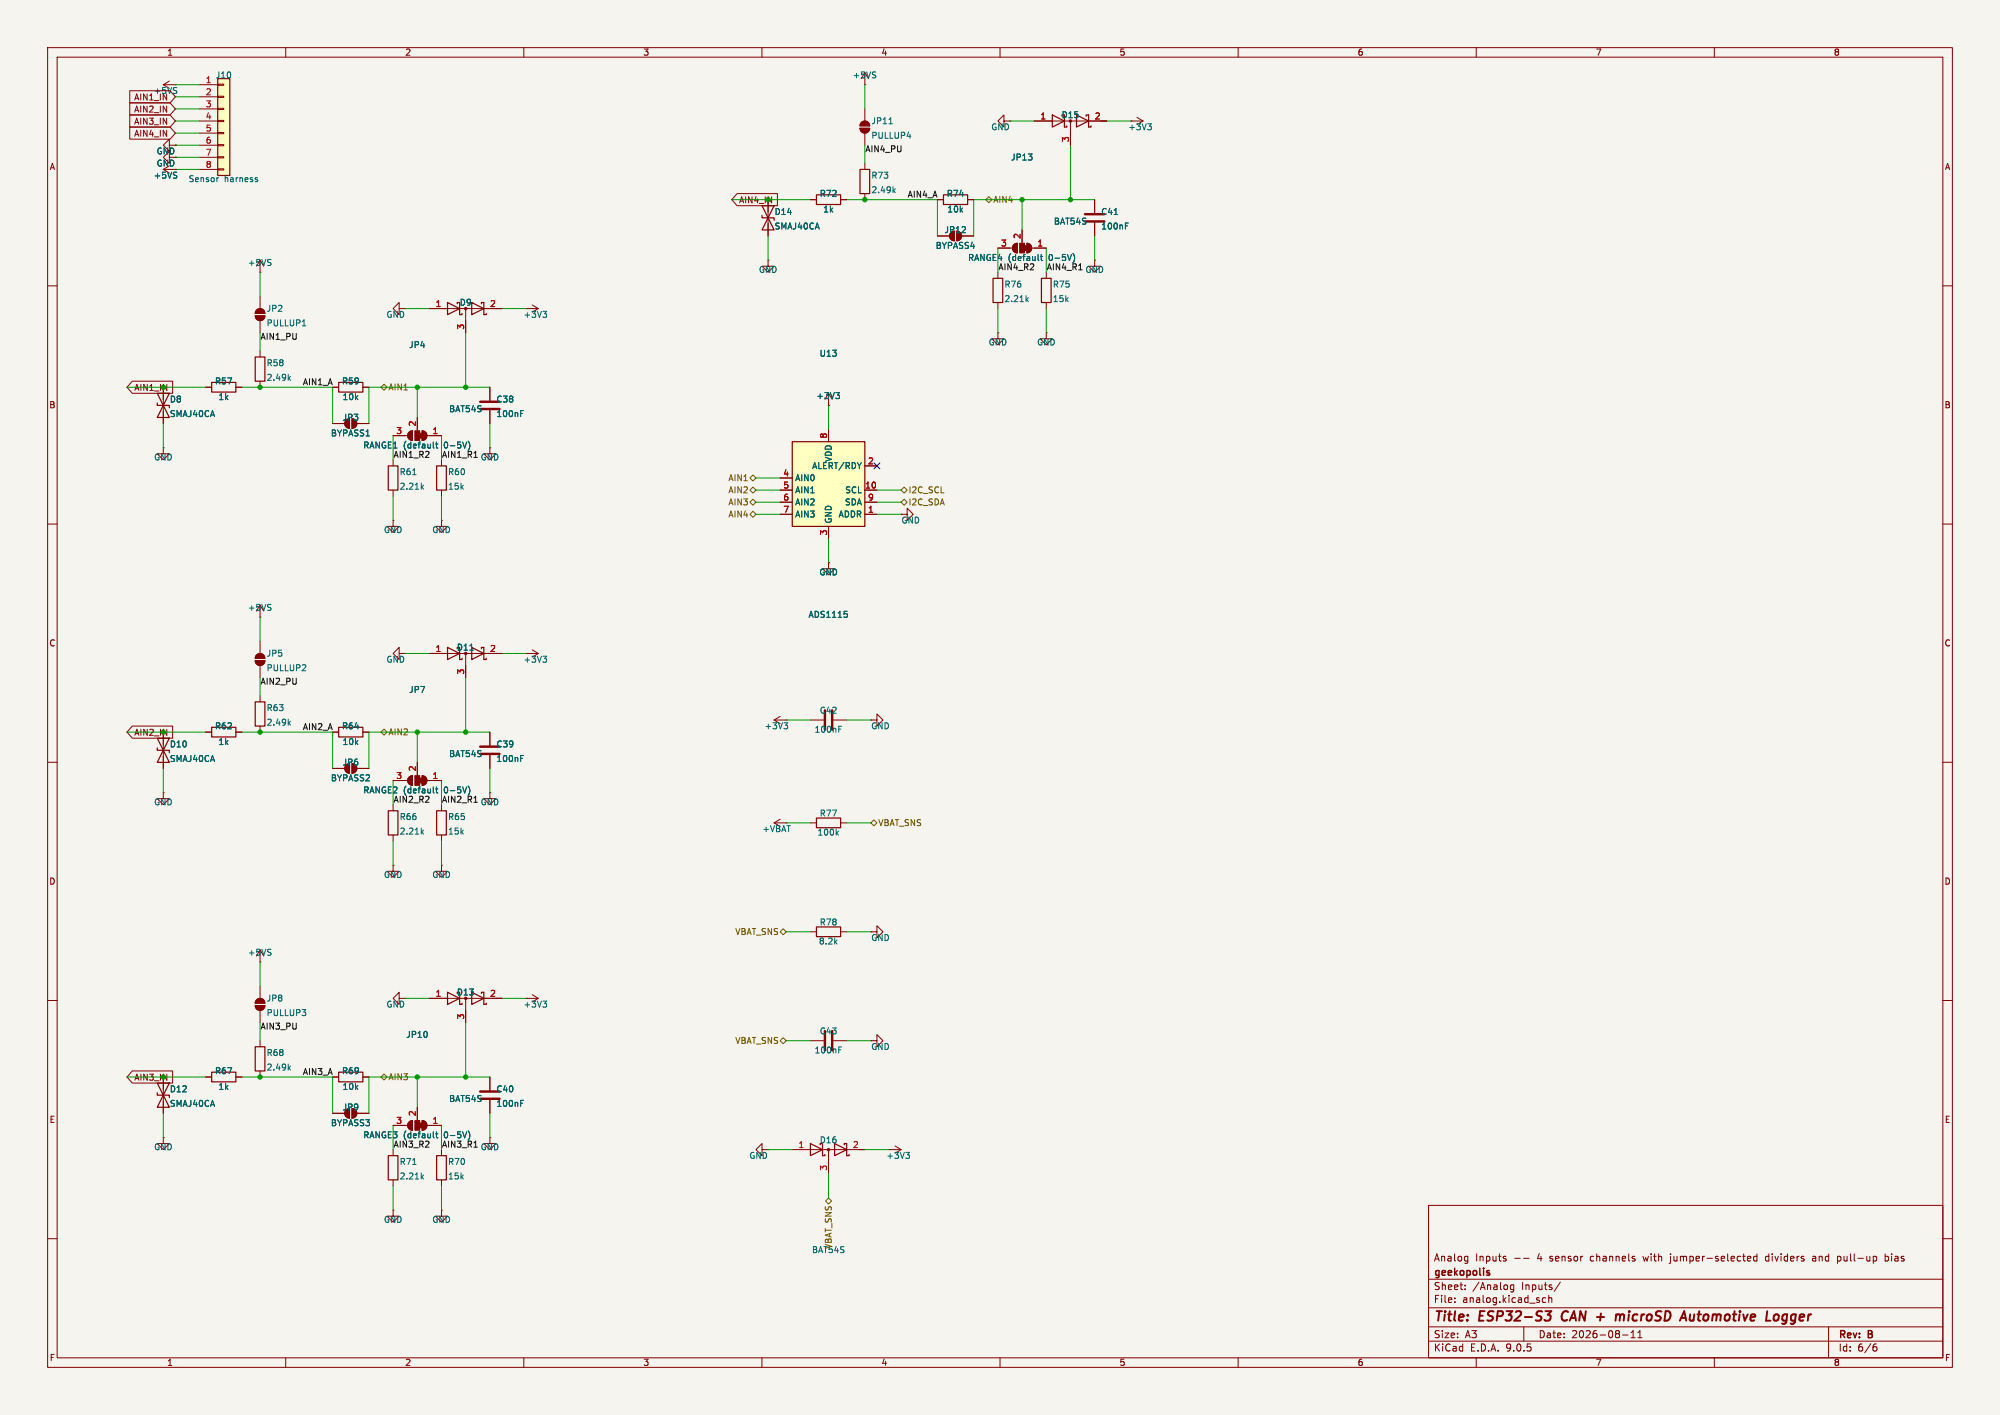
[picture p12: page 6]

3 ALERT/RDY 2 SCL 10 SDA 9 ADDR 1 U13 ADS1115 +3V3 GND

3 ALERT/RDY 2 SCL 10 SDA 9 ADDR 1 +3V3 GND

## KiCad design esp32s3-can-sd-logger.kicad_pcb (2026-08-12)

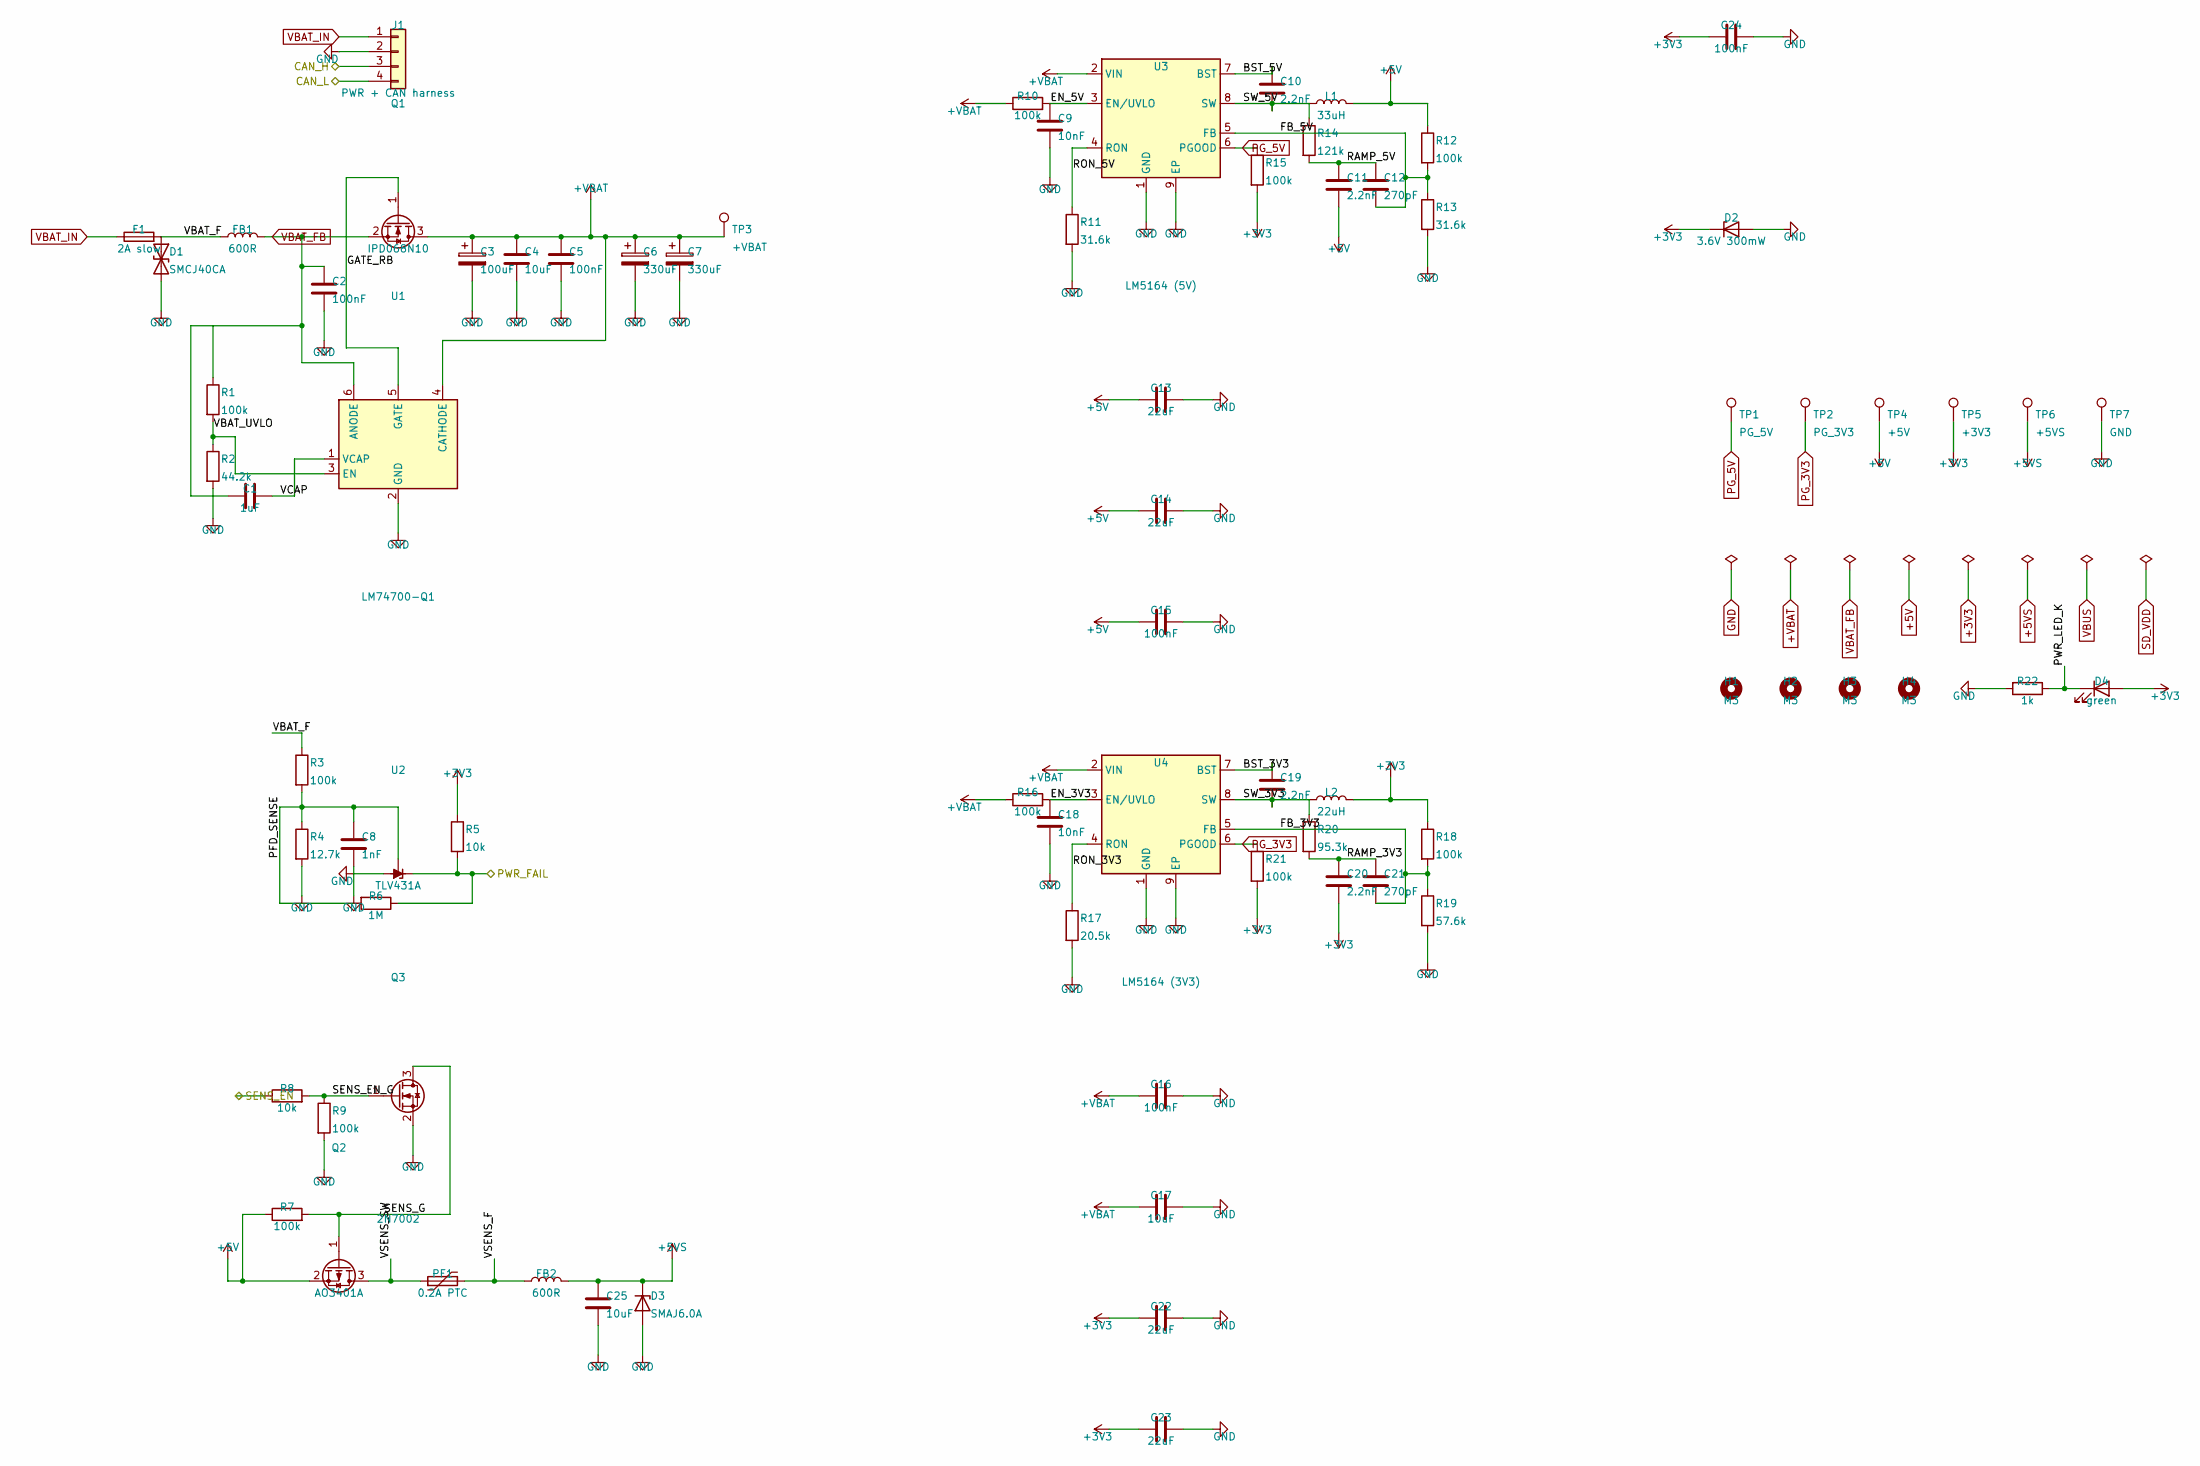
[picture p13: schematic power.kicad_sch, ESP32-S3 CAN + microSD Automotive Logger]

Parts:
C1: 1uF; C_0805_2012Metric; Voltage 50V
C2, C5, C16: 100nF; C_0805_2012Metric; Voltage 100V
C3: 100uF; CP_Elec_10x10.5; Voltage 100V; MPN Nichicon UCD2A101MNL1GS
C4, C17: 10uF; C_1206_3216Metric; Voltage 100V
C6, C7: 330uF; CP_Elec_16x22; Voltage 100V
C8: 1nF; C_0805_2012Metric; Voltage 50V
C9, C18: 10nF; C_0805_2012Metric; Voltage 100V
C10, C11, C19, C20: 2.2nF; C_0805_2012Metric; Voltage 50V
C12, C21: 270pF; C_0805_2012Metric; Voltage 50V
C13, C14, C22, C23: 22uF; C_1206_3216Metric; Voltage 16V
C15, C24: 100nF; C_0805_2012Metric; Voltage 16V
C25: 10uF; C_1206_3216Metric; Voltage 16V
D1: SMCJ40CA; D_SMC; MPN Littelfuse SMCJ40CA
D2: 3.6V 300mW; D_SOD-323; MPN onsemi MM3Z3V6T1G
D3: SMAJ6.0A; D_SMA; MPN Littelfuse SMAJ6.0A
D4: green; LED_0805_2012Metric
F1: 2A slow; Fuse_1206_3216Metric; MPN Littelfuse 0466002.NR
FB1: 600R; L_1206_3216Metric; MPN Wurth 742792625
FB2: 600R; L_0805_2012Metric; MPN Wurth 742792022
H1, H2, H3, H4: M3; MountingHole_3.2mm_M3
J1: PWR + CAN harness; JST_PH_B4B-PH-K_1x04_P2.00mm_Vertical; MPN JST B4B-PH-K-S(LF)(SN)
L1: 33uH; L_Sunlord_SWPA8040S; MPN Sunlord ASWPA8050S330MT
L2: 22uH; L_Sunlord_SWPA8040S; MPN Sunlord ASWPA8050S220MT
PF1: 0.2A PTC; R_1206_3216Metric; MPN Bourns MF-MSMF020
Q1: IPD068N10; TO-252-3_TabPin2; MPN Infineon IPD068N10N3G
Q2: AO3401A; SOT-23; MPN Alpha & Omega AO3401A
Q3: 2N7002; SOT-23; MPN onsemi 2N7002
R1, R7, R9, R10, R12, R15, R16, R18, R21: 100k; R_0805_2012Metric
R2: 44.2k; R_0805_2012Metric
R3: 100k; R_0805_2012Metric; Tolerance 1%
R4: 12.7k; R_0805_2012Metric; Tolerance 1%
R5, R8: 10k; R_0805_2012Metric
R6: 1M; R_0805_2012Metric
R11, R13: 31.6k; R_0805_2012Metric
R14: 121k; R_0805_2012Metric
R17: 20.5k; R_0805_2012Metric
R19: 57.6k; R_0805_2012Metric
R20: 95.3k; R_0805_2012Metric
R22: 1k; R_0805_2012Metric
TP1: PG_5V; TestPoint_Pad_D1.5mm
TP2: PG_3V3; TestPoint_Pad_D1.5mm
TP3: +VBAT; TestPoint_Pad_D1.5mm
TP4: +5V; TestPoint_Pad_D1.5mm
TP5: +3V3; TestPoint_Pad_D1.5mm
TP6: +5VS; TestPoint_Pad_D1.5mm
TP7: GND; TestPoint_Pad_D1.5mm
U1: LM74700-Q1; SOT-23-6; MPN LM74700QDBVRQ1
U2: TLV431A; SOT-23; MPN TLV431ASN1T1G
U3: LM5164 (5V); SOIC-8-1EP_3.9x4.9mm_P1.27mm_EP2.95x4.9mm_Mask2.71x3.4mm_Th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; MPN LM5164DDAR
U4: LM5164 (3V3); SOIC-8-1EP_3.9x4.9mm_P1.27mm_EP2.95x4.9mm_Mask2.71x3.4mm_Th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; MPN LM5164DDAR

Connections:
+3V3: C20.2, C22.1, C23.1, C24.1, D2.1 (K), D4.2 (A), L2.2, R5.1, R15.2, R18.1, R21.2, TP5.1; also elsewhere on the board
+5V: C11.2, C13.1, C14.1, C15.1, L1.2, Q2.2 (S), R7.1, R12.1, TP4.1; also elsewhere on the board
+5VS: C25.1, D3.1 (K), FB2.2, TP6.1; also elsewhere on the board
+VBAT: C3.1, C4.1, C5.1, C6.1, C7.1, C16.1, C17.1, Q1.3 (D), R10.1, R16.1, TP3.1, U1.4 (CATHODE), U3.2 (VIN), U4.2 (VIN); also elsewhere on the board
BST_3V3: C19.1, U4.7 (BST)
BST_5V: C10.1, U3.7 (BST)
CAN_H: J1.3; also elsewhere on the board
CAN_L: J1.4; also elsewhere on the board
EN_3V3: C18.1, R16.2, U4.3 (EN/UVLO)
EN_5V: C9.1, R10.2, U3.3 (EN/UVLO)
FB_3V3: C21.2, R18.2, R19.1, U4.5 (FB)
FB_5V: C12.2, R12.2, R13.1, U3.5 (FB)
GATE_RB: Q1.1 (G), U1.5 (GATE)
PFD_SENSE: C8.1, R3.2, R4.1, R6.2, U2.2 (REF)
PG_3V3: R21.1, TP2.1, U4.6 (PGOOD)
PG_5V: R15.1, TP1.1, U3.6 (PGOOD)
PWR_FAIL: R5.2, R6.1, U2.1 (K); also elsewhere on the board
PWR_LED_K: D4.1 (K), R22.1
RAMP_3V3: C20.1, C21.1, R20.2
RAMP_5V: C11.1, C12.1, R14.2
RON_3V3: R17.1, U4.4 (RON)
RON_5V: R11.1, U3.4 (RON)
SENS_EN: R8.1; also elsewhere on the board
SENS_EN_G: Q3.1 (G), R8.2, R9.1
SENS_G: Q2.1 (G), Q3.3 (D), R7.2
SW_3V3: C19.2, L2.1, R20.1, U4.8 (SW)
SW_5V: C10.2, L1.1, R14.1, U3.8 (SW)
VBAT_F: D1.1 (A1), F1.2, FB1.1, R3.1
VBAT_FB: C1.2, C2.1, FB1.2, Q1.2 (S), R1.1, U1.6 (ANODE)
VBAT_IN: F1.1, J1.1
VBAT_UVLO: R1.2, R2.1, U1.3 (EN)
VCAP: C1.1, U1.1 (VCAP)
VSENS_F: FB2.1, PF1.2
VSENS_SW: PF1.1, Q2.3 (D)

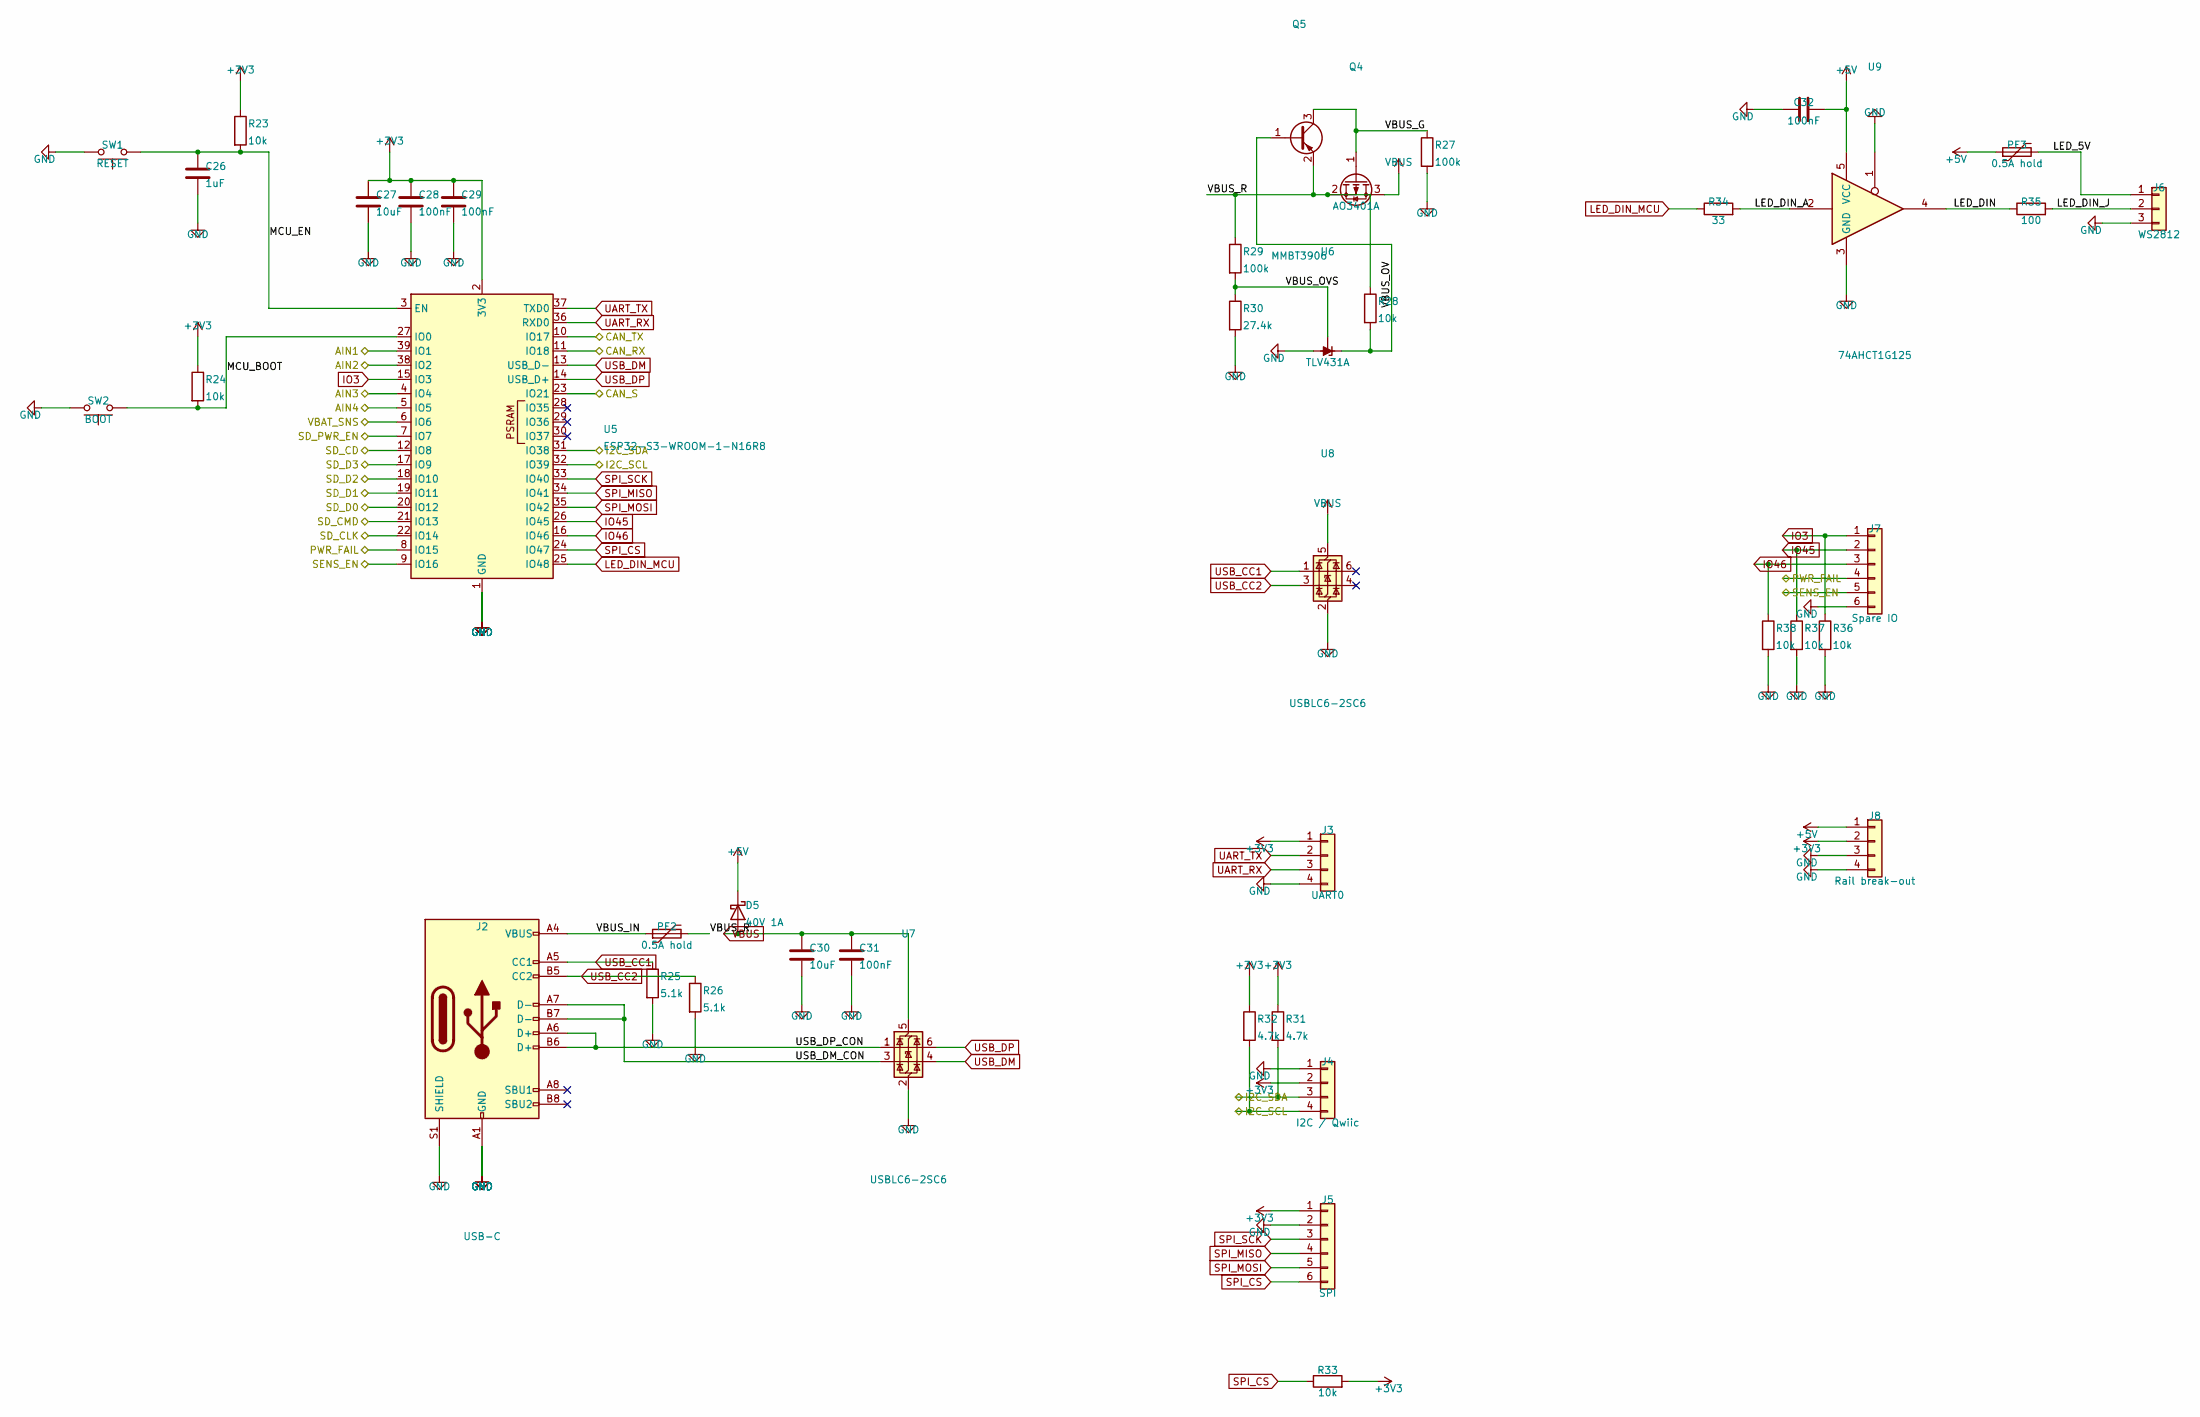
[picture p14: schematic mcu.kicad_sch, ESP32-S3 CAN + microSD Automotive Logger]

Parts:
C26: 1uF; C_0805_2012Metric; Voltage 16V
C27, C30: 10uF; C_1206_3216Metric; Voltage 16V
C28, C29, C31, C32: 100nF; C_0805_2012Metric; Voltage 16V
D5: 40V 1A; D_SOD-123; MPN PMEG4010
J2: USB-C; USB_C_Receptacle_HRO_TYPE-C-31-M-12; MPN HRO TYPE-C-31-M-12
J3: UART0; PinHeader_1x04_P2.54mm_Vertical
J4: I2C / Qwiic; PinHeader_1x04_P2.54mm_Vertical
J5: SPI; PinHeader_1x06_P2.54mm_Vertical
J6: WS2812; PinHeader_1x03_P2.54mm_Vertical
J7: Spare IO; PinHeader_1x06_P2.54mm_Vertical
J8: Rail break-out; PinHeader_1x04_P2.54mm_Vertical
PF2, PF3: 0.5A hold; R_1206_3216Metric; MPN Bourns MF-MSMF050
Q4: AO3401A; SOT-23; MPN Alpha & Omega AO3401A
Q5: MMBT3906; SOT-23; MPN onsemi MMBT3906
R23, R24, R28, R33, R36, R37, R38: 10k; R_0805_2012Metric
R25, R26: 5.1k; R_0805_2012Metric
R27: 100k; R_0805_2012Metric
R29: 100k; R_0805_2012Metric; Tolerance 1%
R30: 27.4k; R_0805_2012Metric; Tolerance 1%
R31, R32: 4.7k; R_0805_2012Metric
R34: 33; R_0805_2012Metric
R35: 100; R_0805_2012Metric
SW1: RESET; SW_SPST_TL3342; MPN TL3342F160QG
SW2: BOOT; SW_SPST_TL3342; MPN TL3342F160QG
U5: ESP32-S3-WROOM-1-N16R8; ESP32-S3-WROOM-1; MPN ESP32-S3-WROOM-1-N16R8
U6: TLV431A; SOT-23; MPN TLV431ASN1T1G
U7, U8: USBLC6-2SC6; SOT-23-6; MPN USBLC6-2SC6
U9: 74AHCT1G125; SOT-23-5; MPN SN74AHCT1G125DBVR

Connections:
+3V3: C27.1, C28.1, C29.1, J3.1, J4.2, J5.1, J8.2, R23.1, R24.1, R31.1, R32.1, R33.2, U5.2 (3V3); also elsewhere on the board
+5V: C32.1, D5.1 (K), J8.1, PF3.1, U9.5 (VCC); also elsewhere on the board
AIN1: U5.39 (IO1); also elsewhere on the board
AIN2: U5.38 (IO2); also elsewhere on the board
AIN3: U5.4 (IO4); also elsewhere on the board
AIN4: U5.5 (IO5); also elsewhere on the board
CAN_RX: U5.11 (IO18); also elsewhere on the board
CAN_S: U5.23 (IO21); also elsewhere on the board
CAN_TX: U5.10 (IO17); also elsewhere on the board
I2C_SCL: J4.4, R32.2, U5.32 (IO39); also elsewhere on the board
I2C_SDA: J4.3, R31.2, U5.31 (IO38); also elsewhere on the board
IO3: J7.1, R36.1, U5.15 (IO3)
IO45: J7.2, R37.1, U5.26 (IO45)
IO46: J7.3, R38.1, U5.16 (IO46)
LED_5V: J6.1, PF3.2
LED_DIN: R35.1, U9.4
LED_DIN_A: R34.2, U9.2
LED_DIN_J: J6.2, R35.2
LED_DIN_MCU: R34.1, U5.25 (IO48)
MCU_BOOT: R24.2, SW2.1, U5.27 (IO0)
MCU_EN: C26.1, R23.2, SW1.1, U5.3 (EN)
PWR_FAIL: J7.4, U5.8 (IO15); also elsewhere on the board
SD_CD: U5.12 (IO8); also elsewhere on the board
SD_CLK: U5.22 (IO14); also elsewhere on the board
SD_CMD: U5.21 (IO13); also elsewhere on the board
SD_D0: U5.20 (IO12); also elsewhere on the board
SD_D1: U5.19 (IO11); also elsewhere on the board
SD_D2: U5.18 (IO10); also elsewhere on the board
SD_D3: U5.17 (IO9); also elsewhere on the board
SD_PWR_EN: U5.7 (IO7); also elsewhere on the board
SENS_EN: J7.5, U5.9 (IO16); also elsewhere on the board
SPI_CS: J5.6, R33.1, U5.24 (IO47)
SPI_MISO: J5.4, U5.34 (IO41)
SPI_MOSI: J5.5, U5.35 (IO42)
SPI_SCK: J5.3, U5.33 (IO40)
UART_RX: J3.3, U5.36 (RXD0)
UART_TX: J3.2, U5.37 (TXD0)
USB_CC1: J2.A5 (CC1), R25.1, U8.1 (I/O1)
USB_CC2: J2.B5 (CC2), R26.1, U8.3 (I/O2)
USB_DM: U5.13 (USB_D-), U7.4 (I/O2)
USB_DM_CON: J2.A7 (D-), J2.B7 (D-), U7.3 (I/O2)
USB_DP: U5.14 (USB_D+), U7.6 (I/O1)
VBAT_SNS: U5.6 (IO6); also elsewhere on the board
VBUS: C30.1, C31.1, D5.2 (A), Q4.3 (D), U7.5 (VBUS), U8.5 (VBUS)
VBUS_G: Q4.1 (G), Q5.3 (C), R27.1
VBUS_IN: J2.A4 (VBUS), J2.A9 (VBUS), J2.B4 (VBUS), J2.B9 (VBUS), PF2.1
VBUS_OV: Q5.1 (B), R28.2, U6.1 (K)
VBUS_OVS: R29.2, R30.1, U6.2 (REF)
VBUS_R: PF2.2, Q4.2 (S), Q5.2 (E), R28.1, R29.1

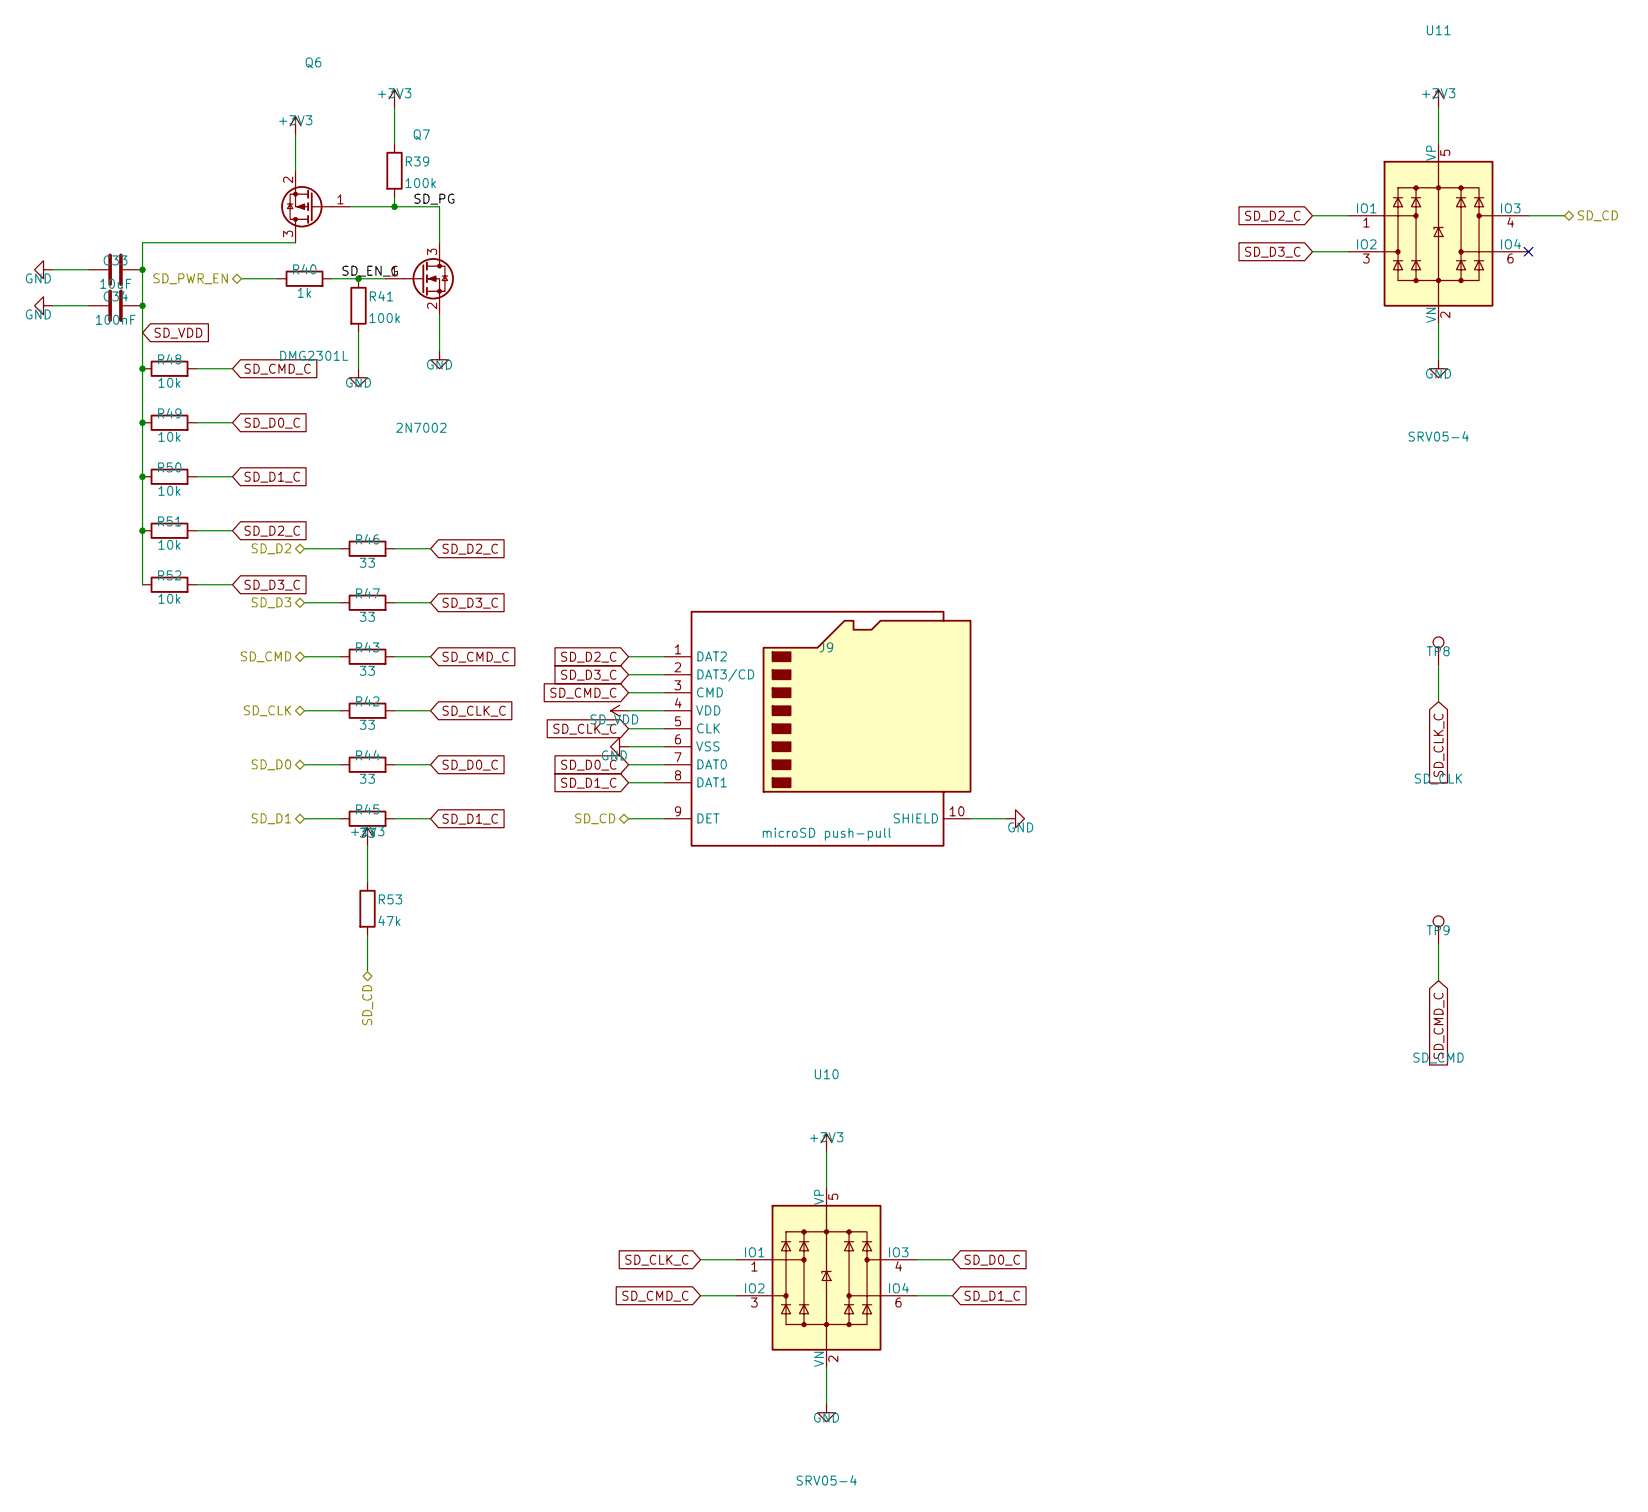
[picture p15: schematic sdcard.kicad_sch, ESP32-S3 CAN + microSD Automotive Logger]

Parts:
C33: 10uF; C_1206_3216Metric; Voltage 16V
C34: 100nF; C_0805_2012Metric; Voltage 16V
J9: microSD push-pull; microSD_HC_Hirose_DM3D-SF; MPN Hirose DM3D-SF
Q6: DMG2301L; SOT-23; MPN DMG2301L
Q7: 2N7002; SOT-23; MPN 2N7002
R39, R41: 100k; R_0805_2012Metric
R40: 1k; R_0805_2012Metric
R42, R43, R44, R45, R46, R47: 33; R_0805_2012Metric
R48, R49, R50, R51, R52: 10k; R_0805_2012Metric
R53: 47k; R_0805_2012Metric
TP8: SD_CLK; TestPoint_Pad_D1.5mm
TP9: SD_CMD; TestPoint_Pad_D1.5mm
U10, U11: SRV05-4; SOT-23-6; MPN Semtech SRV05-4.TCT

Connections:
+3V3: Q6.2 (S), R39.1, R53.1, U10.5 (VP), U11.5 (VP); also elsewhere on the board
SD_CD: J9.9 (DET), R53.2, U11.4 (IO3); also elsewhere on the board
SD_CLK: R42.1; also elsewhere on the board
SD_CLK_C: J9.5 (CLK), R42.2, TP8.1, U10.1 (IO1)
SD_CMD: R43.1; also elsewhere on the board
SD_CMD_C: J9.3 (CMD), R43.2, R48.2, TP9.1, U10.3 (IO2)
SD_D0: R44.1; also elsewhere on the board
SD_D0_C: J9.7 (DAT0), R44.2, R49.2, U10.4 (IO3)
SD_D1: R45.1; also elsewhere on the board
SD_D1_C: J9.8 (DAT1), R45.2, R50.2, U10.6 (IO4)
SD_D2: R46.1; also elsewhere on the board
SD_D2_C: J9.1 (DAT2), R46.2, R51.2, U11.1 (IO1)
SD_D3: R47.1; also elsewhere on the board
SD_D3_C: J9.2 (DAT3/CD), R47.2, R52.2, U11.3 (IO2)
SD_EN_G: Q7.1 (G), R40.2, R41.1
SD_PG: Q6.1 (G), Q7.3 (D), R39.2
SD_PWR_EN: R40.1; also elsewhere on the board
SD_VDD: C33.1, C34.1, J9.4 (VDD), Q6.3 (D), R48.1, R49.1, R50.1, R51.1, R52.1

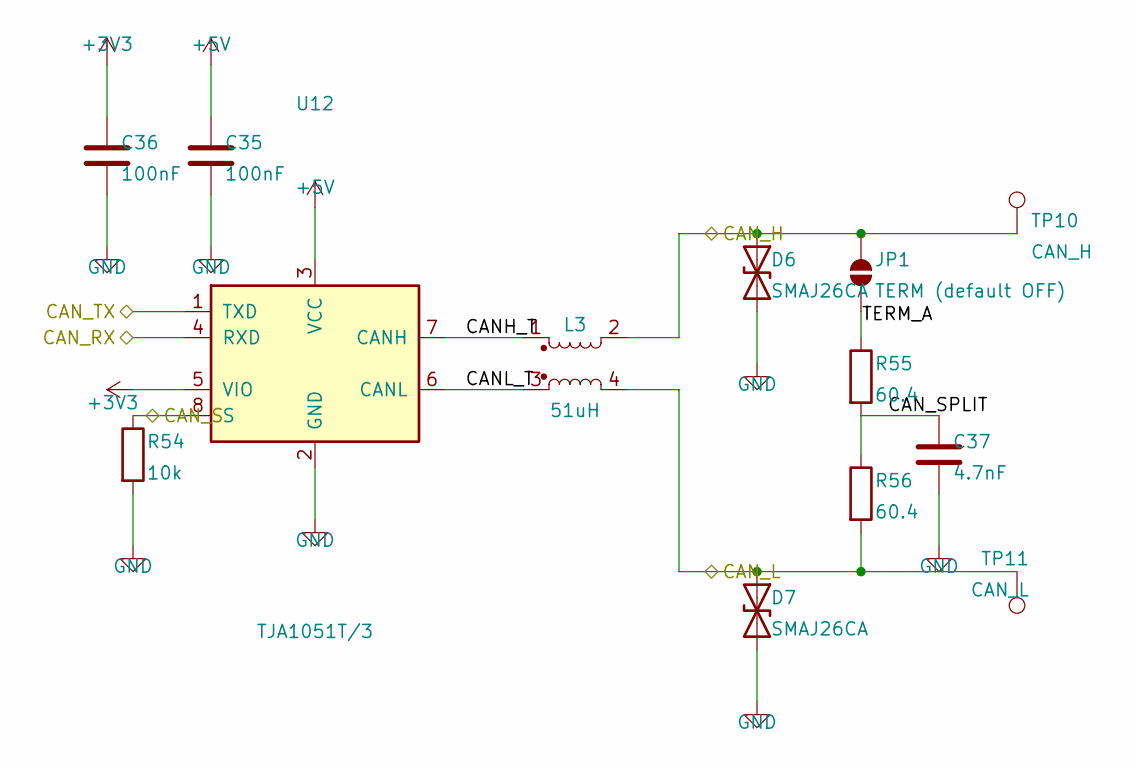
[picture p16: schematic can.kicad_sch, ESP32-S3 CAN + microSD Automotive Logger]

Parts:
C35, C36: 100nF; C_0805_2012Metric; Voltage 16V
C37: 4.7nF; C_0805_2012Metric; Voltage 50V
D6, D7: SMAJ26CA; D_SMA; MPN Diodes Inc SMAJ26CA-13-F
JP1: TERM (default OFF); SolderJumper-2_P1.3mm_Open_Pad1.0x1.5mm
L3: 51uH; L_CommonMode_TDK_ACT45B; MPN TDK ACT45B-510-2P-TL003
R54: 10k; R_0805_2012Metric
R55, R56: 60.4; R_0805_2012Metric
TP10: CAN_H; TestPoint_Pad_D1.5mm
TP11: CAN_L; TestPoint_Pad_D1.5mm
U12: TJA1051T/3; SOIC-8_3.9x4.9mm_P1.27mm; MPN TJA1051T/3,118

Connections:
+3V3: C36.1, U12.5 (VIO); also elsewhere on the board
+5V: C35.1, U12.3 (VCC); also elsewhere on the board
CANH_T: L3.1, U12.7 (CANH)
CANL_T: L3.3, U12.6 (CANL)
CAN_H: D6.1 (A1), JP1.1 (A), L3.2, TP10.1; also elsewhere on the board
CAN_L: D7.1 (A1), L3.4, R56.2, TP11.1; also elsewhere on the board
CAN_RX: U12.4 (RXD); also elsewhere on the board
CAN_S: R54.1, U12.8 (S); also elsewhere on the board
CAN_SPLIT: C37.1, R55.2, R56.1
CAN_TX: U12.1 (TXD); also elsewhere on the board
TERM_A: JP1.2 (B), R55.1

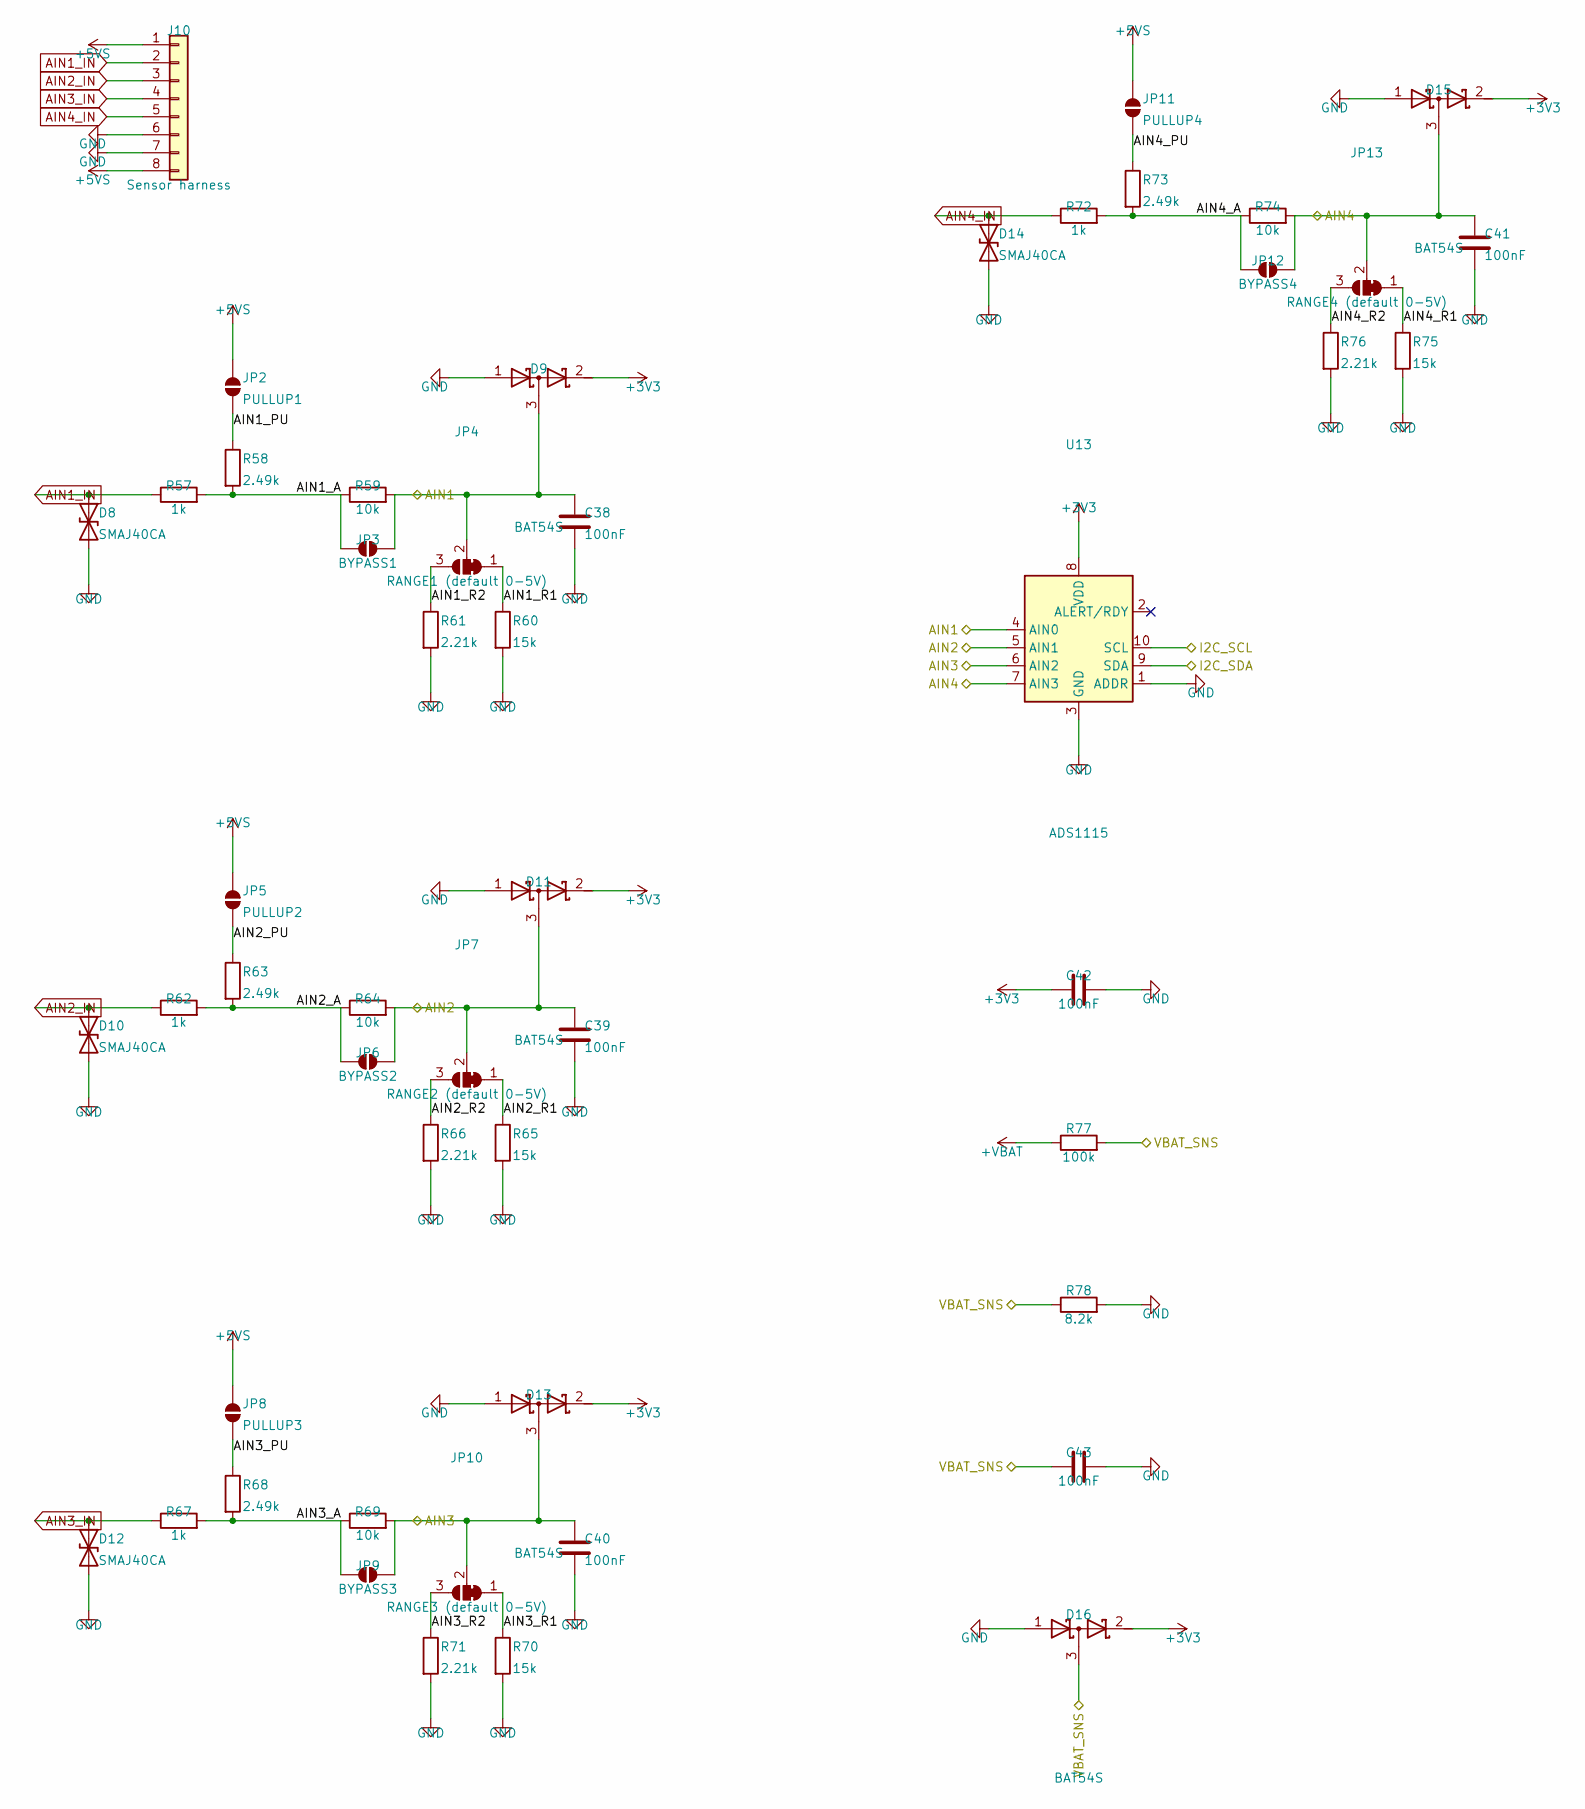
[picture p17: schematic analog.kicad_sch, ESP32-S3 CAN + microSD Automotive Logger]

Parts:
C38, C39, C40, C41, C42, C43: 100nF; C_0805_2012Metric; Voltage 16V
D8, D10, D12, D14: SMAJ40CA; D_SMA; MPN Littelfuse SMAJ40CA
D9, D11, D13, D15, D16: BAT54S; SOT-23; MPN MDD BAT54S
J10: Sensor harness; JST_PH_B8B-PH-K_1x08_P2.00mm_Vertical; MPN JST B8B-PH-K-S(LF)(SN)
JP2: PULLUP1; SolderJumper-2_P1.3mm_Open_Pad1.0x1.5mm
JP3: BYPASS1; SolderJumper-2_P1.3mm_Open_Pad1.0x1.5mm
JP4: RANGE1 (default 0-5V); SolderJumper-3_P1.3mm_Bridged12_Pad1.0x1.5mm
JP5: PULLUP2; SolderJumper-2_P1.3mm_Open_Pad1.0x1.5mm
JP6: BYPASS2; SolderJumper-2_P1.3mm_Open_Pad1.0x1.5mm
JP7: RANGE2 (default 0-5V); SolderJumper-3_P1.3mm_Bridged12_Pad1.0x1.5mm
JP8: PULLUP3; SolderJumper-2_P1.3mm_Open_Pad1.0x1.5mm
JP9: BYPASS3; SolderJumper-2_P1.3mm_Open_Pad1.0x1.5mm
JP10: RANGE3 (default 0-5V); SolderJumper-3_P1.3mm_Bridged12_Pad1.0x1.5mm
JP11: PULLUP4; SolderJumper-2_P1.3mm_Open_Pad1.0x1.5mm
JP12: BYPASS4; SolderJumper-2_P1.3mm_Open_Pad1.0x1.5mm
JP13: RANGE4 (default 0-5V); SolderJumper-3_P1.3mm_Bridged12_Pad1.0x1.5mm
R57, R62, R67, R72: 1k; R_0805_2012Metric; Tolerance 0.1%
R58, R63, R68, R73: 2.49k; R_0805_2012Metric
R59, R64, R69, R74: 10k; R_0805_2012Metric; Tolerance 0.1%
R60, R65, R70, R75: 15k; R_0805_2012Metric; Tolerance 0.1%
R61, R66, R71, R76: 2.21k; R_0805_2012Metric; Tolerance 0.1%
R77: 100k; R_0805_2012Metric
R78: 8.2k; R_0805_2012Metric
U13: ADS1115; VSSOP-10_3x3mm_P0.5mm; MPN ADS1115IDGSR

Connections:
+3V3: C42.1, D9.2 (K), D11.2 (K), D13.2 (K), D15.2 (K), D16.2 (K), U13.8 (VDD); also elsewhere on the board
+5VS: J10.1, J10.8, JP2.1 (A), JP5.1 (A), JP8.1 (A), JP11.1 (A); also elsewhere on the board
+VBAT: R77.1; also elsewhere on the board
AIN1: C38.1, D9.3 (common), JP3.2 (B), JP4.2 (C), R59.2, U13.4 (AIN0); also elsewhere on the board
AIN1_A: JP3.1 (A), R57.2, R58.2, R59.1
AIN1_IN: D8.1 (A1), J10.2, R57.1
AIN1_PU: JP2.2 (B), R58.1
AIN1_R1: JP4.1 (A), R60.1
AIN1_R2: JP4.3 (B), R61.1
AIN2: C39.1, D11.3 (common), JP6.2 (B), JP7.2 (C), R64.2, U13.5 (AIN1); also elsewhere on the board
AIN2_A: JP6.1 (A), R62.2, R63.2, R64.1
AIN2_IN: D10.1 (A1), J10.3, R62.1
AIN2_PU: JP5.2 (B), R63.1
AIN2_R1: JP7.1 (A), R65.1
AIN2_R2: JP7.3 (B), R66.1
AIN3: C40.1, D13.3 (common), JP9.2 (B), JP10.2 (C), R69.2, U13.6 (AIN2); also elsewhere on the board
AIN3_A: JP9.1 (A), R67.2, R68.2, R69.1
AIN3_IN: D12.1 (A1), J10.4, R67.1
AIN3_PU: JP8.2 (B), R68.1
AIN3_R1: JP10.1 (A), R70.1
AIN3_R2: JP10.3 (B), R71.1
AIN4: C41.1, D15.3 (common), JP12.2 (B), JP13.2 (C), R74.2, U13.7 (AIN3); also elsewhere on the board
AIN4_A: JP12.1 (A), R72.2, R73.2, R74.1
AIN4_IN: D14.1 (A1), J10.5, R72.1
AIN4_PU: JP11.2 (B), R73.1
AIN4_R1: JP13.1 (A), R75.1
AIN4_R2: JP13.3 (B), R76.1
I2C_SCL: U13.10 (SCL); also elsewhere on the board
I2C_SDA: U13.9 (SDA); also elsewhere on the board
VBAT_SNS: C43.1, D16.3 (common), R77.2, R78.1; also elsewhere on the board

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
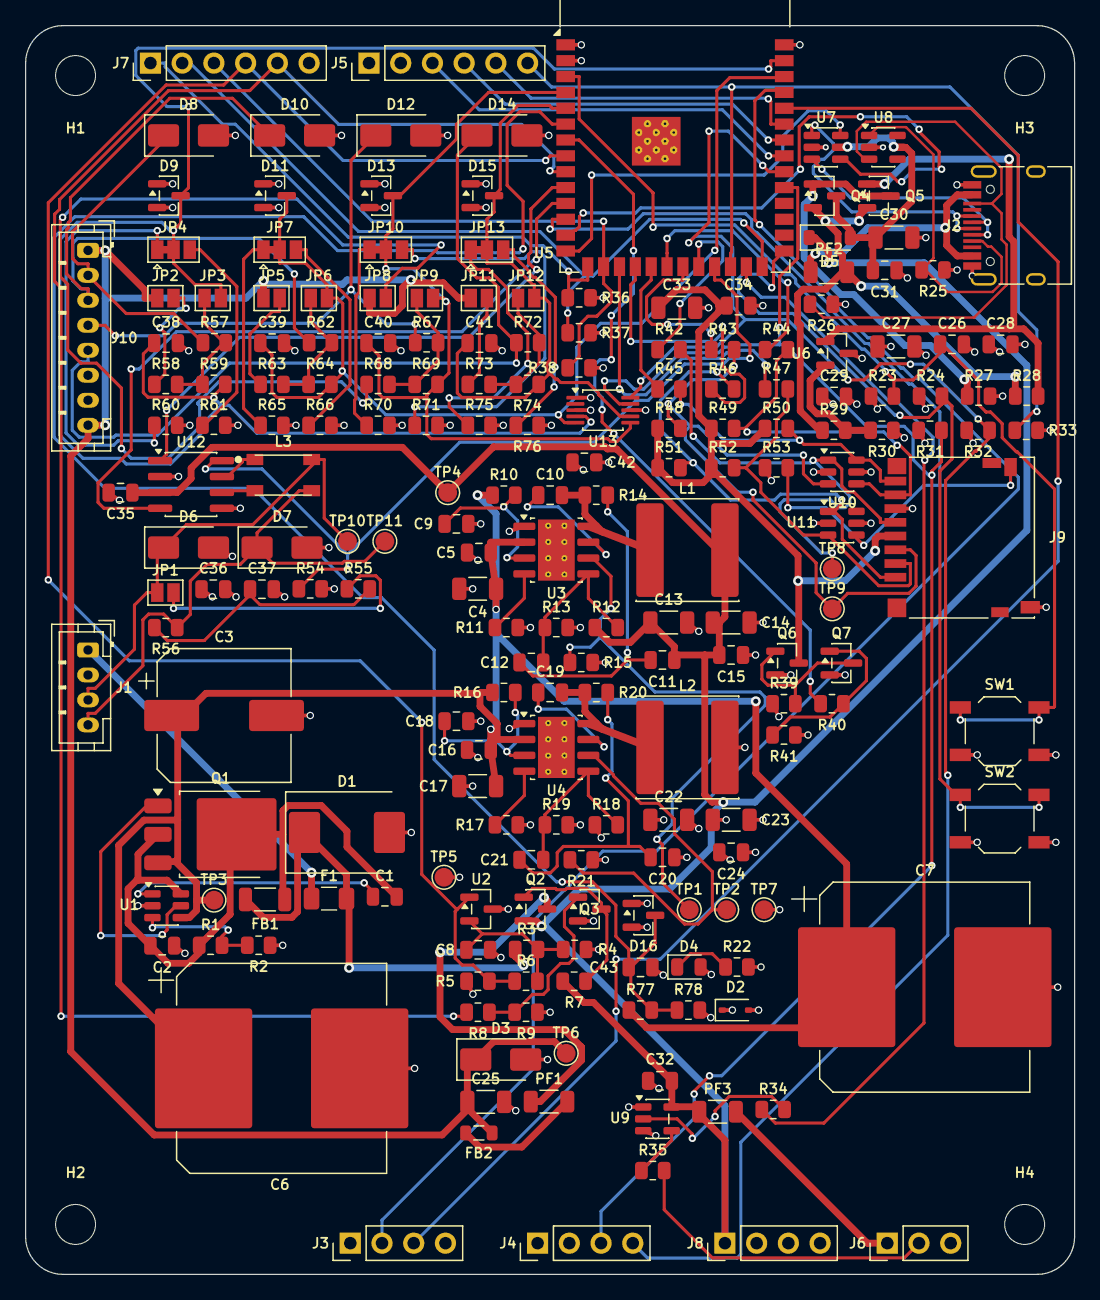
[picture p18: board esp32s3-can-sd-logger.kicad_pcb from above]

Board: 4 copper layers, 84.0 x 100.0 mm, 206 parts (0 on the bottom side), 114 nets.

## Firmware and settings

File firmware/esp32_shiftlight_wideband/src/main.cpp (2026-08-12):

// Shift light + wideband BLE bridge + microSD logger — ESP32-S3 autosport board
//
// Ported from the MINI R53 sketch that runs on a Waveshare ESP32-S3-Zero
// (mini-r53-logger, firmware/esp32_shiftlight_wideband). A verbatim copy of
// that original is kept in firmware/vendor/ and is the control build for
// gen/simulate_firmware.py; every difference below is a difference in the
// hardware, not a change of mind about the logic.
//
// What the board changes, and why each line here is what it is:
//
//   1. Every pin moves. GPIO map is README section 6, and it is the contract.
//   2. The wideband divider is 15k/26k, not 10k/10k. DIVIDER_GAIN was 2.0 and
//      is now 1.7334 — the original constant reads 17 % high here, and the
//      firmware's own 5.5 V clamp then hides the top of the range.
//   3. The +5 V sensor excitation is switched and OFF at reset. Nothing on the
//      harness reads anything until SENS_EN goes high.
//   4. WS2812 data goes through a 74AHCT1G125 whose input floats from reset,
//      so GPIO48 is driven low before the LED driver ever touches it.
//   5. There is a power-fail signal and 108 ms of ride-through behind it, and
//      a microSD card that will be left corrupt if that window is not spent.
//      README section 2 states the contract; shutdown() honours it.
//
// GATT is unchanged, so the existing WidebandBleManager in the logger app
// pairs with this board without modification.
// Libraries: FastLED 3.7+, NimBLE-Arduino 2.x. CAN uses the core's TWAI driver.

#include <Arduino.h>
#include <FastLED.h>
#include <NimBLEDevice.h>
#include <Wire.h>
#include <SD_MMC.h>
#include <driver/twai.h>
#include <math.h>

// --- Pin map (README section 6) ---------------------------------------------
#define LED_PIN     48            // via U6 74AHCT1G125 to the WS2812 header
#define NUM_LEDS    8
#define LED_TYPE    WS2812B
#define COLOR_ORDER GRB

#define CAN_TX_PIN  GPIO_NUM_17
#define CAN_RX_PIN  GPIO_NUM_18
#define CAN_S_PIN   21            // low = normal, high = listen-only

#define PWR_FAIL_PIN 15           // rising = harness below 11 V
#define SENS_EN_PIN  16           // high = +5VS live; off at reset
#define SD_PWR_EN_PIN 7
#define SD_CD_PIN     8
#define SD_CLK_PIN 14
#define SD_CMD_PIN 13
#define SD_D0_PIN  12
#define SD_D1_PIN  11
#define SD_D2_PIN  10
#define SD_D3_PIN   9

#define RPM_STALE_MS 2000         // blank the strip if CAN goes quiet

// 500 kbit/s, id 0x316, RPM in bytes 2-3 little-endian / 6.4. Lifted from the
// working car sketch, esp32-canbus-SN65HVD230-v2 — same decode, same bus.
#define CAN_RPM_ID 0x316

CRGB leds[NUM_LEDS];
uint16_t rpm = 0;
bool redBlinkState = false;
unsigned long lastBlinkTime = 0;
const unsigned long blinkInterval = 100;   // 100 ms = 5 Hz blink above 7100 rpm
unsigned long lastRpmMs = 0;
bool canUp = false;

unsigned long canFrames = 0;      // frames since the last status line

// --- Analog front end (README section 3) ------------------------------------
//
// The four channels are identical and jumper-selected. AIN1 carries the
// wideband, and the gain below MUST match the jumper actually fitted:
//
//   RANGE open, BYPASS closed   0–3.3 V   ratio 1.0000   gain 1.0000
//   RANGE A,    BYPASS open     0–5.0 V   ratio 0.5769   gain 1.7334  <- default
//   RANGE B,    BYPASS open     0–16 V    ratio 0.1673   gain 5.9773
//
// The RANGE jumper now ships BRIDGED 1-2 (0–5 V), so this constant matches a
// board straight out of the box. Change it only if you cut that bridge.
//
// This is the constant that was wrong on the first port: 2.0 is the reciprocal
// of the R53 board's 10k/10k, and using it here reads 17 % high all the way up
// the range. gen/simulate_firmware.py study 3 measures it end to end.
static const float DIVIDER_GAIN = 1.7334f;
static const int   ESP_ADC_PIN  = 1;       // AIN1 = GPIO1 = ADC1_CH0
static const int   VBAT_ADC_PIN = 6;       // VBAT_SNS = GPIO6, divided by 11
static const float VBAT_DIVIDER = 11.0f;

// I2C is on the Qwiic header, not the pins the R53 board used — GPIO7 and
// GPIO8 are the microSD supply enable and card detect here.
static const int   ADS_SDA_PIN  = 38;
static const int   ADS_SCL_PIN  = 39;
static const uint8_t ADS_ADDR   = 0x48;
static const float   ADS_LSB_MV = 0.125f;  // GAIN_ONE (+-4.096 V)

// The sensor can legitimately reach the top of its range, so the clamp has to
// sit above it rather than at 5.5 V, which on this front end is inside the
// measurement band once the gain is right.
static const float SENSOR_VMAX = 5.6f;

enum HwMode : uint8_t { HW_RESISTOR = 0, HW_ADS1115 = 1 };

static const char* DEVICE_NAME = "R53-Wideband";
static const char* SERVICE_UUID      = "4fafc201-1fb5-459e-8fcc-c5c9c331914b";
static const char* VOLTS_CHAR_UUID   = "beb5483e-36e1-4688-b7f5-ea07361b26a8";
static const char* HW_MODE_CHAR_UUID = "beb5483e-36e1-4688-b7f5-ea07361b26a9";

// The strip is redrawn every LOOP_PERIOD_MS; the wideband is notified more
// slowly. 50 Hz notifications outrun the connection interval a phone actually
// negotiates, which backs up NimBLE's buffers until the link drops — and the
// sensor itself only responds in ~100 ms, so 20 Hz loses nothing.
static const uint32_t LOOP_PERIOD_MS   = 20;
static const uint32_t NOTIFY_PERIOD_MS = 50;
static const uint32_t BLE_RETRY_MS     = 5000;
static const uint32_t LOG_FLUSH_MS     = 1000;

NimBLECharacteristic* voltsCharacteristic  = nullptr;
NimBLECharacteristic* hwModeCharacteristic = nullptr;
bool clientConnected = false;
bool bleReady        = false;
uint32_t bleRetryAtMs = 0;
uint32_t lastNotifyMs = 0;
volatile bool voltsSubscribed = false;

volatile uint8_t hwMode = HW_RESISTOR;
bool adsPresent = false;
bool adsTried   = false;

// --- Power fail --------------------------------------------------------------
//
// Set from the ISR, read from loop(). The ISR also drops SENS_EN itself rather
// than leaving it to the main loop: it is one register write, and it doubles
// the ride-through budget from 53 ms to 108 ms (sim/ridethru.png). Every
// millisecond it buys is a millisecond the card has to finish its write.
volatile bool powerFailed = false;
bool shuttingDown = false;

File logFile;
bool sdUp = false;
uint32_t lastLogFlushMs = 0;
unsigned long logLines = 0;

void updateLEDs();
bool bleInit();
void bleWatchdog();
void shutdown();

void IRAM_ATTR onPowerFail() {
  powerFailed = true;
  digitalWrite(SENS_EN_PIN, LOW);
}

/**
 * One status line a second — the only routine output, and the thing that says
 * which half is unhappy without a scope. Frames counts EVERY id on the bus, so
 * "frames 0" is a wiring/transceiver problem while "frames high, rpm 0" is a
 * decode problem.
 */
void printStatus() {
  static unsigned long last = 0;
  unsigned long now = millis();
  if (now - last < 1000) return;
  last = now;
  const char* ble;
  if (!bleReady)              ble = "DOWN";
  else if (clientConnected)   ble = "connected";
  else if (NimBLEDevice::getAdvertising()->isAdvertising()) ble = "advertising";
  else                        ble = "IDLE";
  Serial.printf("rpm %4u  can %s frames/s %-4lu  ble %-11s  sd %s lines %lu\n",
                rpm, canUp ? "up" : "DOWN", canFrames, ble,
                sdUp ? "up" : "DOWN", logLines);
  canFrames = 0;
}

// --- CAN --------------------------------------------------------------------
void canInit() {
  // CAN_S low = normal mode. R40 already pulls it there so the transceiver is
  // sane while the MCU is in reset; drive it anyway so the state is the
  // firmware's decision and not a resistor's.
  pinMode(CAN_S_PIN, OUTPUT);
  digitalWrite(CAN_S_PIN, LOW);

  twai_general_config_t g =
      TWAI_GENERAL_CONFIG_DEFAULT(CAN_TX_PIN, CAN_RX_PIN, TWAI_MODE_NORMAL);
  g.rx_queue_len = 32;   // FastLED.show() blocks ~0.5 ms; don't drop frames in it
  twai_timing_config_t t = TWAI_TIMING_CONFIG_500KBITS();
  twai_filter_config_t f = TWAI_FILTER_CONFIG_ACCEPT_ALL();

  if (twai_driver_install(&g, &t, &f) != ESP_OK || twai_start() != ESP_OK) {
    Serial.println("TWAI: init failed");
    return;
  }
  canUp = true;
  Serial.println("TWAI initialized");
}

void canPoll() {
  if (!canUp) return;
  twai_message_t msg;
  while (twai_receive(&msg, 0) == ESP_OK) {
    canFrames++;
    if (msg.extd || msg.rtr || msg.identifier != CAN_RPM_ID) continue;
    if (msg.data_length_code < 4) continue;
    uint16_t raw = msg.data[2] | ((uint16_t)msg.data[3] << 8);
    rpm = (uint16_t)constrain(raw / 6.4f, 0.0f, 9000.0f);
    lastRpmMs = millis();
  }
  twai_status_info_t st;
  if (twai_get_status_info(&st) == ESP_OK && st.state == TWAI_STATE_BUS_OFF) {
    twai_initiate_recovery();
  }
}

// --- Analog ------------------------------------------------------------------
float readEspAdcSensorVolts() {
  float v = (analogReadMilliVolts(ESP_ADC_PIN) / 1000.0f) * DIVIDER_GAIN;
  return constrain(v, 0.0f, SENSOR_VMAX);
}

float readBatteryVolts() {
  return (analogReadMilliVolts(VBAT_ADC_PIN) / 1000.0f) * VBAT_DIVIDER;
}

bool adsWriteReg(uint8_t reg, uint16_t value) {
  Wire.beginTransmission(ADS_ADDR);
  Wire.write(reg);
  Wire.write((uint8_t)(value >> 8));
  Wire.write((uint8_t)(value & 0xFF));
  return Wire.endTransmission() == 0;
}

bool adsReadReg(uint8_t reg, uint16_t* out) {
  Wire.beginTransmission(ADS_ADDR);
  Wire.write(reg);
  if (Wire.endTransmission(false) != 0) return false;
  if (Wire.requestFrom(ADS_ADDR, (uint8_t)2) != 2) return false;
  uint16_t hi = Wire.read();
  uint16_t lo = Wire.read();
  *out = (hi << 8) | lo;
  return true;
}

/** Lazy I2C — only touch the bus when the phone asks for ADS1115 mode. */
void ensureAdsProbed() {
  if (adsTried) return;
  adsTried = true;
  Wire.begin(ADS_SDA_PIN, ADS_SCL_PIN);
  Wire.setClock(400000);
  if (!adsWriteReg(0x01, 0x4283)) return;   // continuous AIN0, +-4.096 V, 128 SPS
  delay(10);
  uint16_t check = 0;
  adsPresent = adsReadReg(0x01, &check);
}

float readAdsSensorVolts() {
  ensureAdsProbed();
  if (!adsPresent) return NAN;
  uint16_t raw = 0;
  if (!adsReadReg(0x00, &raw)) return NAN;
  float v = (((int16_t)raw) * ADS_LSB_MV / 1000.0f) * DIVIDER_GAIN;
  return constrain(v, 0.0f, SENSOR_VMAX);
}

float readSensorVolts() {
  if (hwMode == HW_ADS1115) {
    float v = readAdsSensorVolts();
    if (isfinite(v)) return v;
  }
  return readEspAdcSensorVolts();
}

// --- microSD -----------------------------------------------------------------
void sdInit() {
  pinMode(SD_CD_PIN, INPUT);
  pinMode(SD_PWR_EN_PIN, OUTPUT);
  digitalWrite(SD_PWR_EN_PIN, HIGH);       // the card supply is switched
  delay(10);                               // let the rail come up before clocking

  SD_MMC.setPins(SD_CLK_PIN, SD_CMD_PIN, SD_D0_PIN, SD_D1_PIN, SD_D2_PIN, SD_D3_PIN);
  if (!SD_MMC.begin("/sdcard", false)) {   // 4-bit: ~4x the write throughput
    Serial.println("SD: mount failed");
    return;
  }
  logFile = SD_MMC.open("/log.csv", FILE_APPEND);
  if (!logFile) {
    Serial.println("SD: could not open /log.csv");
    return;
  }
  logFile.println("t_ms,rpm,wideband_v,vbat_v");
  sdUp = true;
  Serial.println("SD: logging to /log.csv");
}

void logSample(float volts, float vbat) {
  if (!sdUp || shuttingDown) return;
  logFile.printf("%lu,%u,%.3f,%.2f\n", millis(), rpm, volts, vbat);
  logLines++;
  uint32_t now = millis();
  if (now - lastLogFlushMs >= LOG_FLUSH_MS) {
    lastLogFlushMs = now;
    logFile.flush();     // bound what an unexpected reset can lose to one second
  }
}

/**
 * The firmware half of README section 2. The hardware guarantees roughly
 * 108 ms between PWR_FAIL and the converters dropping out; this is what spends
 * it. Order matters: the sensor rail is already off (the ISR did it), the strip
 * goes dark so it is not drawing from the bank, then the file is closed, and
 * only then is the card supply removed — with SD_MMC.end() first, because
 * dropping SD_PWR_EN while the bus pins are still driven back-feeds the card
 * through its ESD structures (README section 5).
 */
void shutdown() {
  if (shuttingDown) return;
  shuttingDown = true;
  digitalWrite(SENS_EN_PIN, LOW);          // idempotent; the ISR got here first

  FastLED.clear(true);

  if (sdUp) {
    // close() flushes. Calling flush() first as well costs a second full
    // card-side write, and on this budget that is not a tidiness question:
    // gen/simulate_firmware.py study 11 measures the double flush cutting the
    // tolerable card latency from ~100 ms to ~50 ms.
    logFile.close();
    SD_MMC.end();
    sdUp = false;
  }
  digitalWrite(SD_PWR_EN_PIN, LOW);

  Serial.printf("PWR_FAIL at %lu ms: %lu lines flushed and closed\n", millis(), logLines);
}

// --- BLE ---------------------------------------------------------------------
class ServerCallbacks : public NimBLEServerCallbacks {
  void onConnect(NimBLEServer* server, NimBLEConnInfo& info) override {
    clientConnected = true;
    // Ask for a link the phone can hold: 15–30 ms interval, no slave latency,
    // 4 s supervision timeout. The default timeout can run to 20 s, and while
    // it counts down after a dropout the server is neither connected nor
    // advertising — twenty seconds of "no wideband bridge found" on the phone.
    server->updateConnParams(info.getConnHandle(), 12, 24, 0, 400);
  }
  void onDisconnect(NimBLEServer*, NimBLEConnInfo&, int) override {
    clientConnected = false;
    // Cleared here, not left to onSubscribe(0): a link that drops out of range
    // or times out never delivers an unsubscribe, and a stale true would have
    // us notifying into nothing until the next client happened to connect.
    voltsSubscribed = false;
    // Deliberately NOT calling startAdvertising() here: this runs on the NimBLE
    // host task while the connection is still being torn down.
    // advertiseOnDisconnect() restarts it at a safe point and bleWatchdog()
    // catches it if that ever doesn't take.
  }
};

class VoltsCallbacks : public NimBLECharacteristicCallbacks {
  void onSubscribe(NimBLECharacteristic*, NimBLEConnInfo&, uint16_t subValue) override {
    voltsSubscribed = (subValue != 0);
  }
};

class HwModeCallbacks : public NimBLECharacteristicCallbacks {
  void onWrite(NimBLECharacteristic* c, NimBLEConnInfo&) override {
    NimBLEAttValue v = c->getValue();
    if (v.length() < 1) return;
    uint8_t mode = v[0];
    if (mode == HW_RESISTOR || mode == HW_ADS1115) {
      hwMode = mode;
      c->setValue(&mode, 1);
    }
  }
};

/**
 * Bring the whole BLE stack up, checking every step. Returns false — leaving
 * the stack torn back down so the next attempt starts clean — if any of them
 * fails. Every one of these calls returns a status in NimBLE 2.x; ignoring them
 * is exactly how the board ends up running the shift light perfectly with no
 * BLE at all and nothing on the terminal to say why.
 */
bool bleInit() {
  voltsCharacteristic  = nullptr;
  hwModeCharacteristic = nullptr;

  if (!NimBLEDevice::init(DEVICE_NAME)) {
    Serial.println("BLE: NimBLEDevice::init() failed");
    return false;
  }
  NimBLEDevice::setPower(ESP_PWR_LVL_P9);

  NimBLEServer* server = NimBLEDevice::createServer();
  if (server == nullptr) {
    Serial.println("BLE: createServer() failed");
    NimBLEDevice::deinit(true);
    return false;
  }
  server->setCallbacks(new ServerCallbacks());
  server->advertiseOnDisconnect(true);

  NimBLEService* service = server->createService(SERVICE_UUID);
  if (service == nullptr) {
    Serial.println("BLE: createService() failed");
    NimBLEDevice::deinit(true);
    return false;
  }
  voltsCharacteristic = service->createCharacteristic(
      VOLTS_CHAR_UUID, NIMBLE_PROPERTY::NOTIFY);
  hwModeCharacteristic = service->createCharacteristic(
      HW_MODE_CHAR_UUID, NIMBLE_PROPERTY::READ | NIMBLE_PROPERTY::WRITE);
  if (voltsCharacteristic == nullptr || hwModeCharacteristic == nullptr) {
    Serial.println("BLE: createCharacteristic() failed");
    voltsCharacteristic = nullptr;
    hwModeCharacteristic = nullptr;
    NimBLEDevice::deinit(true);
    return false;
  }
  voltsCharacteristic->setCallbacks(new VoltsCallbacks());
  hwModeCharacteristic->setCallbacks(new HwModeCallbacks());
  uint8_t hwModeInit = hwMode;
  hwModeCharacteristic->setValue(&hwModeInit, 1);
  voltsSubscribed = false;

  // The phone filters the scan on the 128-bit service UUID, so that UUID has to
  // be advertised or nothing will ever match. 18 bytes of UUID + 3 of flags
  // fills most of the 31-byte advert, which is why the name goes in the scan
  // response instead of competing for room with it.
  NimBLEAdvertising* adv = NimBLEDevice::getAdvertising();
  adv->setName(DEVICE_NAME);
  adv->addServiceUUID(SERVICE_UUID);
  adv->enableScanResponse(true);
  if (!adv->start()) {
    Serial.println("BLE: advertising failed to start");
    voltsCharacteristic = nullptr;
    hwModeCharacteristic = nullptr;
    NimBLEDevice::deinit(true);
    return false;
  }

  bleReady = true;
  Serial.printf("BLE: advertising as %s (free heap %u)\n",
                DEVICE_NAME, (unsigned)ESP.getFreeHeap());
  return true;
}

/**
 * Two failures this recovers from, both of which used to need a power cycle:
 * a bring-up that never succeeded (retry it), and a stack that is up but has
 * silently stopped advertising while nothing is connected (restart it).
 */
void bleWatchdog() {
  uint32_t now = millis();

  if (!bleReady) {
    if ((int32_t)(now - bleRetryAtMs) < 0) return;
    bleRetryAtMs = now + BLE_RETRY_MS;
    Serial.printf("BLE: retrying bring-up (free heap %u)\n", (unsigned)ESP.getFreeHeap());
    bleInit();
    return;
  }

  static uint32_t lastCheck = 0;
  if (now - lastCheck < 1000) return;
  lastCheck = now;
  if (!clientConnected && !NimBLEDevice::getAdvertising()->isAdvertising()) {
    Serial.println("BLE: advertising had stopped — restarting");
    NimBLEDevice::getAdvertising()->start();
  }
}
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
void loop() {
  // Checked before anything else: from here on the only job is to finish the
  // write and stop. Nothing below this line may start new work.
  if (powerFailed) {
    shutdown();
    delay(LOOP_PERIOD_MS);
    return;
  }

  canPoll();
  bleWatchdog();

  float volts = readSensorVolts();

  // getSubscribedCount() — not just clientConnected. A phone is connected for
  // a beat before it discovers services and writes the CCCD, and notifying into
  // that gap is pure churn on the link at the least forgiving moment.
  if (bleReady && voltsCharacteristic != nullptr && voltsSubscribed &&
      (uint32_t)(millis() - lastNotifyMs) >= NOTIFY_PERIOD_MS) {
    lastNotifyMs = millis();
    if (isfinite(volts)) {
      voltsCharacteristic->setValue((uint8_t*)&volts, sizeof(volts));
      voltsCharacteristic->notify();
    }
  }

  logSample(volts, readBatteryVolts());

  updateLEDs();
  FastLED.show();
  printStatus();
  delay(LOOP_PERIOD_MS);
}

void updateLEDs() {
#ifdef RPM_STALE_MS
  if (rpm != 0 && (unsigned long)(millis() - lastRpmMs) > RPM_STALE_MS) rpm = 0;
#endif

  CRGB color;

  // Number of LED pairs to light, 0 to 4.
  int numPairs = constrain(map(rpm, 0, 7100, 0, 4), 0, 4);

  if (rpm < 3000) {
    color = CRGB(0, 0, 0);                // off below 3000 rpm
  } else if (rpm < 6000) {
    color = CRGB(0, 255, 0);              // solid green 3000-6000
  } else if (rpm <= 7100) {
    uint8_t t = map(rpm, 6000, 7100, 0, 255);   // green to red 6000-7100
    color = CRGB(t, 255 - t, 0);
  } else {
    if (millis() - lastBlinkTime >= blinkInterval) {
      redBlinkState = !redBlinkState;
      lastBlinkTime = millis();
    }
    color = redBlinkState ? CRGB(255, 0, 0) : CRGB(0, 0, 0);
    numPairs = 4;                         // all eight blink above 7100
  }

  // Light from the ends inward.
  for (int i = 0; i < NUM_LEDS; i++) {
    leds[i] = CRGB(0, 0, 0);
    if (numPairs >= 1 && (i == 0 || i == 7)) leds[i] = color;
    if (numPairs >= 2 && (i == 1 || i == 6)) leds[i] = color;
    if (numPairs >= 3 && (i == 2 || i == 5)) leds[i] = color;
    if (numPairs >= 4 && (i == 3 || i == 4)) leds[i] = color;
  }
}

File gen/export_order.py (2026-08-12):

#!/usr/bin/env python3
"""
Shopping list for building the boards yourself.

  python gen/export_order.py [--boards 5] [--spares-passive 20] [--spares-ic 1]

`fab/bom.csv` is written for JLCPCB's assembly flow, where quantities are
implicit and the eight through-hole connectors and three unavailable
electrolytics are deliberately absent. None of that is right for buying the
parts loose and reflowing them at home, which needs the opposite: every part,
an explicit count, and spares for the ones that will get lost or tombstoned.

Writes three files to `fab/`:

  order-lcsc.csv       part number + quantity, ready to paste into LCSC's
                       bulk-order box
  order-elsewhere.csv  the parts LCSC/JLC cannot supply, with what to search
  order-summary.txt    a readable version of both, with the reasoning

Spares default to +20 pieces on passives (they cost fractions of a cent and
LCSC has minimum order quantities anyway, which will round most of them up
regardless) and +1 on anything with a package you would not want to hand-place
twice.
"""

from __future__ import annotations

import argparse
import collections
import csv
import os
import re
import sys

HERE = os.path.dirname(os.path.abspath(__file__))
PROJ = os.path.abspath(os.path.join(HERE, ".."))
FAB = os.path.join(PROJ, "fab")

# Parts no assembly house here can supply, or that are through-hole and were
# deliberately kept out of fab/. Buy these separately.
#
# The three electrolytics are the interesting ones: JLCPCB's SMD aluminium
# electrolytic library stops at 47 uF once 100 V is needed, so there is no
# part to order from them at all. Nichicon UCD / Rubycon MV are the reference
# series. Check the can diameter before ordering -- the land patterns are
# 10 mm and 16 mm, and an 18 mm part will not fit.
ELSEWHERE = [
    ("C3",        1, "100uF 100V SMD electrolytic, 10 mm can",
     "Nichicon UCD2A101MNL1GS or equivalent. Land is CP_Elec_10x10.5"),
    ("C6, C7",    2, "330uF 100V SMD electrolytic, 16 mm can",
     "Land is CP_Elec_16x22 (same pads as 16x17.5). If 330 uF only exists at "
     "18 mm, fit 220 uF at 16 mm instead -- the bank drops to 540 uF and the "
     "ride-through to ~108 ms, which is what the board was simulated at "
     "originally"),
    ("J1",        1, "JST PH 4-pin vertical header, 2.00 mm", "B4B-PH-K-S"),
    ("J10",       1, "JST PH 8-pin vertical header, 2.00 mm", "B8B-PH-K-S"),
    ("J3, J4, J8", 3, "0.1\" pin header, 1x04 vertical", "any"),
    ("J5, J7",    2, "0.1\" pin header, 1x06 vertical", "any"),
    ("J6",        1, "0.1\" pin header, 1x03 vertical", "any"),
    ("harness",   1, "JST PH crimp housings + crimps for J1 (4) and J10 (8)",
     "buy with the headers or the harness cannot be made up"),
]


# LCSC enforces a minimum order quantity and an order *multiple* per part, and
# asking for 95 of something sold in hundreds is a rejected line rather than a
# rounded one. Sampled from the live catalogue on 2026-08-13:
#
#   0805 resistor  C17414   min 100, multiple 100
#   0805 capacitor C49678   min  20, multiple  20
#   1206 capacitor C13585   min  20, multiple  20
#   SOT-23 BAT54S  C408389  min  50, multiple  50
#   SO-8 LM5164    C477928  min   1, multiple   1
#   ESP32 module   C2913202 min   1, multiple   1
#
# The pattern is commodity-versus-branded, not package: cheap jellybean parts
# are sold in reels of 20-100, anything with a manufacturer's name on it goes
# in ones. Rounding passives to 100 satisfies every 20/50/100 multiple at once
# and costs about thirty cents a line, which is cheaper than a second order.
MOQ_EXACT = {}                      # per-part overrides, if one ever surprises us
MOQ_PASSIVE = 100                   # 0402 .. 1210
MOQ_DISCRETE = 50                   # SOT-23 / SOD-123 jellybean semiconductors
_DISCRETE_FP = re.compile(r"SOT-\d|SOD-\d|SOT23|TO-236")


def moq_round(pn, qty, footprint):
    """Bump a quantity up to something LCSC will actually accept."""
    step = MOQ_EXACT.get(pn)
    if step is None:
        if re.search(r"_(0402|0603|0805|1206|1210)_", footprint):
            step = MOQ_PASSIVE
        elif _DISCRETE_FP.search(footprint):
            step = MOQ_DISCRETE
        else:
            step = 1               # branded ICs, connectors, inductors
    return ((qty + step - 1) // step) * step


def main():
    ap = argparse.ArgumentParser()
    ap.add_argument("--boards", type=int, default=5)
    ap.add_argument("--spares-passive", type=int, default=20)
    ap.add_argument("--spares-ic", type=int, default=1)
    args = ap.parse_args()

    bom = os.path.join(FAB, "bom.csv")
    if not os.path.exists(bom):
        raise SystemExit("fab/bom.csv missing -- run gen/export_fab.py first")

    per_part = collections.defaultdict(lambda: {"n": 0, "refs": [], "cmt": "", "fp": ""})
    unspecified = []
    for row in csv.DictReader(open(bom, encoding="utf-8")):
        pn = row["JLCPCB Part #"].strip()
        refs = [r.strip() for r in row["Designator"].split(",") if r.strip()]
        if not pn:
            unspecified.append((row["Comment"], row["Designator"]))
            continue
        e = per_part[pn]
        e["n"] += len(refs)
        e["refs"] += refs
        e["cmt"] = row["Comment"]
        e["fp"] = row["Footprint"].split(":")[-1]

    def is_passive(fp):
        return bool(re.search(r"_(0402|0603|0805|1206|1210)_", fp))

    lines = []
    for pn, e in sorted(per_part.items(), key=lambda kv: -kv[1]["n"]):
        need = e["n"] * args.boards
        spare = args.spares_passive if is_passive(e["fp"]) else args.spares_ic
        lines.append((pn, need + spare, need, spare, e["cmt"], e["fp"],
                      ",".join(sorted(set(e["refs"])))))

    os.makedirs(FAB, exist_ok=True)
    out = os.path.join(FAB, "order-lcsc.csv")
    with open(out, "w", newline="", encoding="utf-8") as fh:
        w = csv.writer(fh)
        w.writerow(["LCSC Part Number", "Order Qty", "Needed", "Spares",
                    "Comment", "Footprint", "Designators"])
        for pn, order, need, spare, cmt, fp, refs in lines:
            w.writerow([pn, moq_round(pn, order, fp), need, spare,
                        cmt, fp, refs])
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

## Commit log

2026-08-10 Add ESP32-S3 CAN + microSD automotive logger schematic (rev A)
    Schematic-only release of a 10-off board: automotive-grade power input
    with reverse-battery protection, onboard microSD, one CAN transceiver,
    and four sensor inputs with jumper-selectable dividers.
    Power chain is an LM74700-Q1 ideal-diode controller driving a 100V
    N-channel FET, with the load-dump TVS placed behind the blocking FET so
    a reversed battery blocks instead of blowing the fuse. Two LM5164-Q1
    bucks run directly off the protected node, so a shorted sensor harness
    trips a polyfuse without browning out the MCU.
    The schematic is generated: gen/generate_schematic.py holds the netlist
    as the source of truth and pulls symbol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
    [analog.kicad_sch, bom.csv, can.kicad_sch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]
2026-08-10 Support KiCad 8/9 toolchains in the schematic generator and validator
    validate.py now runs `kicad-cli sch erc` when the installed CLI has it
    (8.0 and later), reporting violations as failures; on 7.x it skips with
    an explicit notice rather than silently passing. ERC was never run on
    this design, since the container that produced it only had KiCad 7.
    generate_schematic.py records the schematic format it emits and the
    symbol-library format its embedded definitions were validated against,
    and warns when the installed libraries are a different generation. The
    generator copies symbol definitions verbatim, so a KiCad 9 library set
    would embed 9-era syntax in a file declaring the 7.0 format; the wa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
    [generate_schematic.py, validate.py]
2026-08-10 Make the generator and validator work on Windows and macOS
    Both scripts assumed a Linux install and failed immediately elsewhere.
    generate_schematic.py defaulted --symbol-dir to /usr/share/kicad/symbols,
    so on Windows it died with "symbol library not found". It now auto-detects
    the symbol libraries from the KICADn_SYMBOL_DIR environment variables or
    the standard install paths on Windows, macOS and Linux, preferring the
    newest KiCad when several are present, and prints an actionable message
    with per-platform examples when it finds none.
    validate.py invoked kicad-cli by bare name, which the Windows installer
    does not put on PATH. It now resolves the executable from PATH or the
    usual install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
    [generate_schematic.py, validate.py]
2026-08-10 Pass ERC clean on KiCad 9.0 and regenerate against its libraries
    - Add a PWR_FLAG on VBAT_FB so the LM74700 ANODE power-input pin, fed
    through the reverse-battery FET and EMI bead, no longer trips
    power_pin_not_driven.
    - Resolve the generic MOSFET symbols from Transistor_FET where the
    KiCad 9 libraries moved them out of Device.
    - Handle the KiCad 9 library format in the raw-symbol extractor: tab
    indentation, CRLF line endings, and no trailing space after the
    symbol name.
    - Flatten derived symbols the way KiCad does — carry the child's whole
    property blocks into the parent geometry instead of only swapping the
    value strings — so the embedded USBLC6-2SC6 matches the library c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
    [analog.kicad_sch, can.kicad_sch, mcu.kicad_sch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]
2026-08-10 Fix the LM5164 power stages against the datasheet and TI's DDA drawing
    Review of datasheet SNVSAU4D and package drawing 4214849/B (DDA0008B)
    caught five issues, all fixed and re-verified:
    - RON placeholders (100k -> ~125/83kHz) corrected to 31.6k (396kHz, 5V)
    and 20.5k (402kHz, 3V3); minimum on-time at the 53.3V clamp is
    237ns/154ns, well above the 50ns floor.
    - Bootstrap caps were 100nF; the datasheet mandates exactly 2.2nF and
    warns larger values damage the internal VCC regulator. Now 2.2nF 50V.
    - No FB ripple injection on the all-ceramic outputs -- a COT stability
    requirement (Table 6-1). Added Type-3 networks (RA/CA/CB: 121k and
    95.3k / 3.3nF / 270pF) sized for ~20mV ramp at 1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
    [analog.kicad_sch, bom.csv, can.kicad_sch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]
2026-08-10 Add an ADS1115-Q1 precision path for AFR logging
    The board's mission now includes wideband AFR, and the ESP32-S3 ADC's
    ±1-2% (±0.2 AFR on a 0-5V output) is not tuning-grade. U7, an ADS1115-Q1
    16-bit delta-sigma on the existing I2C bus at 0x48, shares the four
    conditioned AINx nodes so firmware can choose per channel between the
    fast internal ADC and the accurate external one. Inputs stay inside the
    ADS1115 absolute maximum thanks to the existing BAT54S clamps.
    The front end is upgraded to match: the divider resistors (1k series,
    10k upper, 15k and 2.21k range legs) are now 0.1% thin-film, and the
    range notes are corrected to include the 1k series resistor in the
    divider math (5.0V in read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
    [analog.kicad_sch, bom.csv]
2026-08-10 Source the BOM for JLCPCB assembly; fix a nonexistent FET part number
    Availability check against LCSC / DigiKey / Mouser (2026-08), with the
    board now targeted at JLCPCB pick-and-place:
    - Q1 was specified as PSMN4R3-100BSE, a part number that does not exist
    (Nexperia's nearest real part is the D2PAK PSMN4R8-100BSE, which would
    not fit the TO-252 footprint anyway). Replaced with Infineon
    IPD068N10N3G (LCSC C88066): DPAK, 100V, 6.8mOhm, in stock.
    - LM5164QDDARQ1 is backordered at DigiKey and nearly dry at Mouser;
    switched to the non-automotive LM5164DDAR (LCSC C477928, DigiKey 3.4k
    in stock). Same silicon, minus AEC-Q100.
    - ADS1115QDGSRQ1 requires a manufacturer quote at DigiKey; sw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
    [analog.kicad_sch, bom.csv, power.kicad_sch]
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2026-08-10 Reconcile placement ownership: generate_pcb places, route_bucks routes
    The board generator and route_bucks.py both placed the buck parts and
    fought each other -- 180 DRC violations of stacked pads and courtyards.
    Now generate_pcb.py owns all placement: the two LM5164 islands are in a
    BUCK_FIXED table keyed by (sheet, value, exact net set), so reference
    renumbering can never scatter them again, and their geometry is
    redesigned against real courtyard sizes (EN/BST/ramp row, IC+inductor
    row with input caps rotated toward the VIN pin, RON/FB row, ripple/PG
    row, output caps at the inductor).
    route_bucks.py is routing-only: it finds parts on the saved board by
    value/net signature and draws the SW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
    [esp32s3-can-sd-logger.kicad_pcb]
2026-08-10 Add the routing pipeline: plane stitching, plane-safe DSN, fab export
    Routing the board turned out to hinge on two things the obvious approach
    gets wrong, so both are now encoded in scripts rather than lore:
    - KiCad exports every copper layer to Specctra as `signal`, so the
    autorouter ran IO45 and SPI_MOSI straight across the middle of the
    +3V3 pour, fragmenting it and orphaning everything that depended on
    the plane. gen/export_dsn.py rewrites In1/In2 as `power` so routing
    stays on F.Cu/B.Cu.
    - A pad on GND or +3V3 wants a via to its plane, not a routed track.
    gen/stitch_planes.py places all 117 of them before routing, so the
    router sees them as obstacles and has only signals le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
    [bom.csv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]
2026-08-10 Route the board: 338 of 341 connections, DRC-clean
    The board now carries ~1500 tracks and 210 vias over solid GND and +3V3
    planes, and kicad-cli pcb drc reports zero violations. Three connections
    in the two most congested blocks are left for the interactive router and
    are named in README section 10.
    What made routing work, beyond the plane-safe DSN and pre-stitched plane
    vias added in the previous commit:
    - Per-zone part spacing. The microSD block is nothing but series
    resistors that all have to be routed through, and at the global 0.4 mm
    courtyard gap there was no channel for a 0.2 mm track with clearance
    either side, so the router could not get in at all. That one zone now
    packs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
    [esp32s3-can-sd-logger-B_Cu.gbr, esp32s3-can-sd-logger-B_Mask.gbr, esp32s3-can-sd-logger-B_Paste.gbr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]
2026-08-10 Finish the board: rip-up routing closes the last three connections
    The autorouter left SD_CMD, SD_D0 and USB_DM_CON open, and no amount of
    searching was going to find them a path -- there wasn't one. It routes the
    easy nets first and fences the awkward ones in: SD_CLK ran straight under
    the ESP32 module's pads 20 and 21 and walled both off, and at 1.27 mm pitch
    nothing slips past sideways.
    gen/maze_route.py does what a person does. It grids each copper layer at
    0.1 mm from real pad, track, via and keepout geometry, searches both layers
    at once with Dijkstra, and when that fails works out which nets are pressed
    against the dead end, tears them out, routes the trapped net through the
    space th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
    [esp32s3-can-sd-logger-B_Cu.gbr, esp32s3-can-sd-logger-B_Mask.gbr, esp32s3-can-sd-logger-B_Paste.gbr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]
2026-08-10 Fix netclasses being silently lost: the power rails were 0.2 mm
    Checking the ESP32 pin assignments turned up something worse than a pin
    conflict. The committed project file held only the Default netclass and
    zero netclass patterns, so Power (0.5 mm track, 0.8 mm via) and CAN had
    never been applied and the whole board routed at 0.2 mm -- including +5V
    and +5VS, which are 1 A rails.
    Nothing caught it because narrow track is legal track. 0.2 mm in 1 oz
    copper is 1.01 A at a 20 C rise and drops 147 mV over a 60 mm run; on
    +5VS, the sensor excitation rail, that droop lands straight on every
    ratiometric reading the 0.1% dividers and the 16-bit ADC exist to
    protect.
    Three separate causes, all fix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
    [bom.csv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]
2026-08-11 Docs: correct five wrong part references and refresh the stale artifacts
    The R62/R63 slip turned out not to be alone. Cross-checking every
    component reference in the README against bom.csv and netlist.txt found
    five that name the wrong part, all in prose that reads perfectly well:
    - the battery divider is R63 (100k) / R64 (10k), not R62/R63 -- R62 is
    channel 4's 2.21k range resistor
    - the CAN transceiver is U7, not U6; U6 is the WS2812 buffer
    - CAN_S is pulled low by R40 (10k), not R39, which is the SD
    card-detect pull-up
    - the split-termination capacitor is C28; C27 is a decoupler
    - the common-mode choke is a TDK ACT45B-510-2P-TL003, not a Wurth
    WE-SL2 -- the BOM and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
    [generate_pcb.py]
2026-08-11 Prepare Pinscope inputs, and fix the BOM bug that preparing them exposed
    Pinscope (github.com/Faradworks/Pinscope) reviews a schematic against the
    manufacturers' datasheets -- the one class of check nothing else here
    does. KiCad's ERC knows the netlist is self-consistent; it has no idea
    whether pin 5 of U7 is allowed to sit at 3.3 V.
    It takes a PADS-PCB netlist and a BOM. Both are now generated and, more
    usefully, checked against Pinscope's own parsers rather than assumed
    good: format detected as pads, 168 parts and 107 nets recovered,
    validate_netlist() clean, and every netlist reference resolving in the
    BOM except TP1-TP7, which are bare pads and correctly absent.
    Making the BOM parse tu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
    [bom.csv, esp32-autosport-bom.csv]
2026-08-11 Fix the assembly BOM dropping 129 of 144 parts
    export_fab.py's bom() skipped any part without a pre-filled LCSC number,
    on the assumption they would be chosen in JLC's catalogue later. They
    cannot be: JLC pairs the BOM to the placement file by designator, so a
    designator that appears in positions.csv and in no BOM line is not
    "pick it later", it is not assembled. The uploaded pair would have been
    144 placements against 15 BOM lines, and the boards would have come back
    with almost nothing on them.
    Every placed part is now written, with an empty LCSC cell where no part
    is chosen yet -- which is exactly what JLC's parts-matching screen is
    for. Solder jumpers join mounting holes and test points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
    [bom.csv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]
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2026-08-11 Fix the assembly BOM so JLC actually reads our part numbers
    JLC's returned match file has a "Your BOM -> JLCPCB Part #" column and it
    was empty on all 73 rows: the column has to be headed "JLCPCB Part #",
    and ours said "LCSC", so it was ignored outright. Every line, including
    the fifteen that were carefully sourced, fell through to the fuzzy text
    matcher instead.
    What that produced, from JLC's own descriptions in the returned file:
    D5 "40V 1A" -> SS0750301F040V1A, an SPDT lever *limit switch*
    J6 "WS2812" -> an actual WS2812 RGB LED, for a 3-pin header
    U6 -> LMV324 quad op-amp in TSSOP-14, not a SOT-23-5 buffer
    C2 -> a through-hole 10x17mm electrolytic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
    [bom.csv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]
2026-08-11 Fix two BOM-matching faults JLC's second pass exposed
    U6 had the wrong LCSC number. C7975 is an LMV324IPWRG4 quad op-amp in
    TSSOP-14, not the SN74AHCT1G125DBVR buffer in SOT-23-5. JLC resolved our
    number to it and warned that the footprint did not match -- which is the
    only reason it surfaced, since a wrong-but-valid part number matches
    silently and the price total looks fine. Cleared, with a comment naming
    the trap so it does not get pasted back in. Every other pre-sourced
    number was confirmed correct by JLC's own resolution.
    The maker prefix on Comment was my own regression. These tables store
    the manufacturer alongside the part number ("Littelfuse SMCJ33A"), JLC
    strips the space, and "Li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
    [bom.csv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]
2026-08-11 Schematic: power symbols and readable text placement (items 1-2 of 5)
    The schematic was a netlist drawn as a picture: 486 global labels for 108
    nets, roughly four per net, every part an island with a name flag on each
    pin and no wires between anything. You could not trace a circuit by eye.
    That is a fair description of a document that fails at the one thing a
    schematic is for, and it is on me -- the generator was built to produce a
    correct netlist and the drawing was an afterthought.
    Two of the five agreed fixes are in:
    Rails are power symbols. GND, +3V3, +5V, +5VS, +VBAT, VBUS and SD_VDD now
    carry a proper power symbol instead of a net-name label -- 190 of them,
    taking the label count fro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
    [analog.kicad_sch, bom.csv, can.kicad_sch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]
2026-08-11 Rev B board: netclass fix for the sense nodes, and a floor under rip-up
    Two real faults, both of the kind that pass DRC while being wrong.
    VBAT_UVLO and VBAT_SNS were being routed at 0.5 mm. The netclass pattern
    "VBAT_*" swept them into the Power class along with the three nets that
    actually carry battery current. Neither of them carries any: VBAT_UVLO is
    the LM74700 enable divider midpoint and VBAT_SNS is the ADC sense node,
    both high-impedance at microamps. Wide copper there is wasted, couples
    more noise onto an analog node, and made a 63 mm run across a congested
    board far harder than it needed to be. Replaced with explicit patterns
    for VBAT_IN, VBAT_F and VBAT_FB.
    maze_route could make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
    [bom.csv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]
2026-08-11 Rev B is fully routed: zero DRC errors, nothing unconnected
    84 x 84 mm, 1447 tracks, 258 vias, 179 footprints, 106 nets.
    The last few connections were never routing problems. Each one was a part
    sited away from the net it belongs to, and the autorouter reporting "no
    path at any width" was telling the truth:
    +5VS the sensor rail's source (PF1/FB2/D3) sat on the right beside the
    WS2812 header while everything it feeds -- the sensor harness and
    all four channel pull-ups -- is on the left. The net existed as
    two complete halves with a 45 mm gap through buck islands and the
    SD socket. Moved the source to the harness side.
    IO46 the strapping pull-downs were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
    [analog.kicad_sch, bom.csv, can.kicad_sch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]
2026-08-11 Schematic: wire the two-pin nets instead of naming them twice
    A net drawn as two name labels is correct and unreadable. Where a net has
    exactly two pins in the whole design and both sit on one sheet, the two
    parts can simply be placed against each other and joined with a wire,
    because that is what the connection is. 21 nets qualify.
    Those parts now travel with the pin they serve: the satellite is parked
    8.89 mm beyond the host pin, rotated so its own pin faces back, which
    makes the join a single straight wire rather than an L. F1 and FB1 read
    as a series pair; C7 hangs off U2's BST pin where it belongs.
    The name moves onto the wire as a local label, which is where a
    schematic puts it. Drop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
    [analog.kicad_sch, can.kicad_sch, mcu.kicad_sch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]
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2026-08-11 Schematic: draw the buck converters by hand instead of packing them
    Auto-layout of an arbitrary netlist is the hard problem; drawing this
    circuit is not. gen/sch_blocks.py holds the LM5164 step-down as explicit
    coordinates, wires and junctions, and both converters are stamped from
    it -- the same trick gen/generate_pcb.py already uses for the buck
    islands on the board.
    Three things had to be learned from KiCad the hard way:
    - A wire must END at every junction on it. The editor splits wires when
    you drop a junction and the netlister relies on that; a junction left
    mid-segment stranded the far half on a net of its own, so SW stopped
    at the bootstrap cap and never reached the ind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
    [power.kicad_sch]
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2026-08-11 Turn the USB-C round, clamp ahead of the FET, draw the last two blocks
    Two review findings from Matt, both correct:
    - The USB-C receptacle faced the wrong way. Its fab outline runs
    y -3.65..+3.65 and the signal pads sit at y -4.04, outside it: the
    contacts leave the REAR of the shell, so at 0 degrees the mouth faces
    +y, and at the 270 it was placed at the opening pointed back into the
    middle of the board. At 90 the mouth ends ~2 mm inside the right edge
    -- the plug approaches over the top of the laminate, so those last
    2 mm are not in its way -- and the pad row faces inboard, which is
    where the D+/D- via columns and the USBLC6 already were.
    - The transient c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
    [analog.kicad_sch, bom.csv, can.kicad_sch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]
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2026-08-11 Draw the module and the shift-light chain; unpack the crowded text
    The last two packed groups are now hand-drawn blocks. The module block is
    the ESP32 and only the parts that exist to serve it: its decoupling on a
    3V3 rail across the top, EN out to the left with its pull-up, delay cap
    and reset button, IO0 out with its pull-up and the boot button. The
    WS2812 block is the shift-light output in signal order -- series damping,
    the level shifter that lifts 3.3 V to the 5 V the strip wants, its bypass
    cap, a second series resistor, and the strip's own 5 V through a
    resettable fuse.
    Routing EN and IO0 out of the module needed care. Every other pin down
    that edge takes a 5.08 mm stub to a label, s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
    [analog.kicad_sch, can.kicad_sch, mcu.kicad_sch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]
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2026-08-11 Board: put the four mounting holes on a square
    They were at three different insets -- a fixing beside the module, another
    halfway down the right edge, and the bottom pair 6 mm out of line with the
    top, left over from when the board was 74 mm tall. Now one per corner, 4 mm
    in from each, so the four of them form a 76 x 76 square.
    4 mm rather than something rounder is set by H1: the keepout ring is 6.94 mm
    across, and any further in it eats into J7, which cannot move because the
    top header row has no slack. At the other end J6 shifts 1.5 mm left so H4's
    ring clears the connector body by 1.7 mm -- at the old position the screw
    head would have overlapped its corner.
    Rerouted: 0 DRC errors, 0 un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
    [esp32s3-can-sd-logger-B_Cu.gbr, esp32s3-can-sd-logger-B_Mask.gbr, esp32s3-can-sd-logger-B_Paste.gbr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]
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2026-08-12 Harden the board-build pipeline against four ways it shipped defects
    - route_bucks find() takes `near`: both bucks now carry an identical
    input-cap pair, so value + net signature no longer names one part.
    Nearest-to-the-VIN-pin does, and stays stable through renumbering.
    - finish_routing runs before the autorouter as well as after (--early):
    the tie between a connector's duplicated pins has exactly one corridor,
    and once signals fill it the tie cannot be made at all -- J2's second
    VBUS pad was left open on an otherwise fully-routed board.
    - tie vias offset across the pad-pair axis, not always in x: on a
    side-by-side pair (SW1/SW2) the old offset put both vias on one point,
    whic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
    [build_board.py, export_plots.py, finish_routing.py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]
2026-08-12 Add the checks DRC cannot make: a physical audit and ngspice simulation
    gen/audit_pcb.py reads the routed board and judges rail current capacity
    against IPC-2221, copper inside the antenna keepout, bypass-capacitor
    distance to the pin served (skipping plane-fed rails), dissipation against
    copper and thermal vias, pad/net coverage, and drilled holes that overlap
    -- the last because DRC only compares holes on different nets. Its
    decoupling check found the 3V3 buck with no input capacitor of its own and
    the CAN transceiver's bypass 8.8 mm from its supply pin.
    gen/simulate.py runs four ngspice decks (needs ngspice + numpy +
    matplotlib, plain Python 3) and writes decks, data and plots to sim/: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
    [audit_pcb.py, simulate.py]
2026-08-12 Power-fail ride-through: detect, coast, shed; board grows to 84 x 100
    The ignition cuts this board's power with a log file open, every drive.
    Three new pieces make that survivable, all simulated before layout:
    - Detect: TLV431 + 100k/12.7k divider on VBAT_F, AHEAD of the ideal
    diode, asserting PWR_FAIL (IO15) at 11.0 V with ~0.3 V hysteresis.
    The harness collapses microseconds after the key turns while +VBAT
    coasts, so the warning costs no stored energy.
    - Coast: two 220 uF/100 V cans join the 100 uF on +VBAT. 540 uF on the
    input rail, where a volt of headroom is worth most.
    - Shed: AO3401 + 2N7002 high-side switch on the sensor rail (SENS_EN,
    IO16, off at reset), with PF1 moved b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
    [analog.kicad_sch, bom.csv, can.kicad_sch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]
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2026-08-12 Studies 9-11, post-route extraction, strap audit, readable labels, production BOM numbers
    New tests, run against the final board:
    - audit_routes.py: Dijkstra IR drop over the routed copper (worst 55 mV
    at rated current), SD/USB/CAN routed lengths (USB pair matched to
    1.1 mm), buck switch-node copper area. All clean.
    - audit_straps.py: every ESP32-S3 strapping pin against what the netlist
    hangs on it; all five boot in their required state.
    - simulate.py 9, stability: the LM5164 ripple-injection criterion across
    the input window. Found the ramp thin (10.6 mV) at a legitimate 8 V
    operating point -- ramp caps changed 3.3 nF -> 2.2 nF, now 15.8 mV+
    everywhere above crank voltages. Boa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
    [analog.kicad_sch, bom.csv, can.kicad_sch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]
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2026-08-12 Study 12 (scipy signal fidelity), bring-up checklist, STEP model
    - simulate.py study 12 puts numbers on what sampling does to logged
    data: an AFR-style sweep plus 100 mV rms of 0.2-5 kHz engine noise
    through each jumper mode's real filter at the ADS1115's 860 SPS.
    Divider modes log at 0.37 % / 0.23 % of full scale -- the earlier
    above-Nyquist warning is benign there; bypass mode is the noisy one
    at 1.84 % and wants firmware averaging. This is also the study that
    finally uses scipy; kibot proved redundant to kicad-cli and this
    pipeline does not use it.
    - docs/BRINGUP.md: staged first-power checklist, every step with its
    expected value and the study that derived it -- visual, d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
    [simulate.py]
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
